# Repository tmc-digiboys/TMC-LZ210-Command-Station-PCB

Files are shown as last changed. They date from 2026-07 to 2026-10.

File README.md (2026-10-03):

[🇬🇧 English](README.md) | [🇩🇪 Deutsch](README.de.md) | [🇳🇱 Nederlands](README.nl.md)

# DCC Command Station LZ210-TMC

Modular DCC command station with Ethernet and USB connectivity, and (partial) support for the XpressNet and Z21 protocols. The board supports LocoNet-T and XpressNet handhelds and other equipment, provides an interface for external boosters via CDE and LocoNet-B, and has a connection for RS-Bus feedback modules.

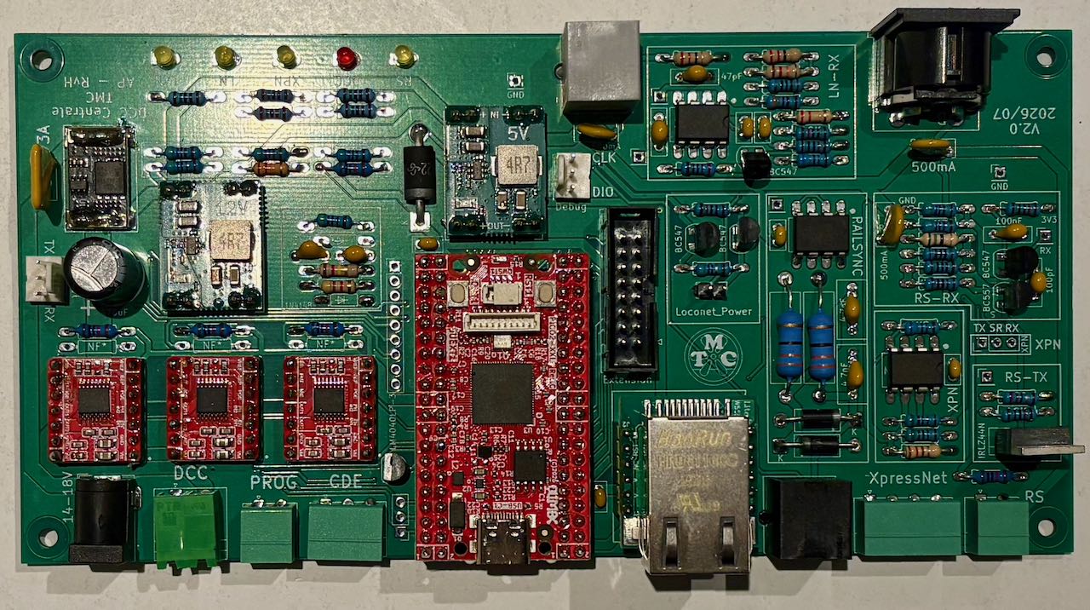
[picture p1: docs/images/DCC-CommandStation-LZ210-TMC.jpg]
DCC Command Station


## Why this board
The [Twentse Modelspoorweg Club (TMC)](https://twentsemodelspoorweg.club) is modernising its electronics and software for digital layout control. For each of its stations (Hengelo, Enschede, Oldenzaal, Almelo) it needs its own new DCC command station to operate all turnouts and signals, and to receive occupancy feedback. Although DCC command stations are of course available ready-made, building your own is not only a nice challenge, but also a potential cost saving.

The starting point is a modular design, similar to the [Z21PG](https://pgahtow.de/w/Zentrale_Z21PG/de). Initially we looked at whether we could simply adapt or replicate this design. We quickly realised that upgrading to a modern processor and ready-made modules would lead to better results and a lower price.

The goal is to develop a command station that can be extended step by step and that **club members and other interested persons can easily adapt and rebuild**. That is why we deliberately chose an easy-to-solder, low-cost THT (Through-Hole Technology) PCB, and, for the critical components, ready-made modules that can easily be bought online.

For the processor we chose the RP2350B, mainly because of its PIO peripheral, which allows a fully jitter-free DCC signal to be generated. It is an inexpensive and modern dual-core processor, running at 125 MHz. See [processor choice](docs/processor.md) for a comparison with ESP32, DxCore and STM32.

The name LZ210-TMC was chosen as a contraction of Z21 (Roco, Z21 protocol, LocoNet) and LZ100 (Lenz, XpressNet, RS-Bus interface and CDE booster connection).

## Schematic
The complete schematic (all hierarchical sheets) is available in [Schematic.pdf](docs/Schematic.pdf).

The schematic is divided into the following functional blocks (click the name for more details):

<details>
<summary><strong>Power supply</strong></summary>

The command station must be powered with a DC voltage equal to the desired track voltage. In practice, a switching or laptop-style power supply can be used that can deliver a voltage between 14 and 20 volts, and 3 to 4 amps.

⚠️ **Note:** not every switching power supply is suitable or safe for this purpose. Practical advice: choose a power supply of the kind used with other DCC command stations, for example the [Roco 10851](https://www.roco.cc/rde/10851-schaltnetzteil-54-watt.html) or [YaMoRC YD7460-18](https://yamorc.de/products/?singleproduct=13843).

The external supply voltage enters via a 3 amp eFuse and a so-called "ideal diode", which protects the circuit against reverse polarity, and then feeds VCC and two step-down converter modules.

VCC powers the H-bridges for the track voltage and the programming track. VCC also runs to the processor, so that a resistor divider and an ADC input can be used to check whether the external supply voltage has the correct value.

The 12V step-down converter supplies power to LocoNet, XpressNet, the CDE booster interface, and RS-Bus feedback. The 12V voltage is likewise, for monitoring purposes, fed through a resistor divider to an ADC input.

The choice of the 5V step-down converter requires some explanation, because the processor and peripherals actually expect 3V3. The reason 5V was chosen is that the Olimex RP2350 Pico2-XL module already has its own step-down chip on board. An external 3V3 converter must *not* be connected to the 3V3 output of the Olimex module (see below). The output of the Olimex module does deliver enough power to supply the rest of the peripherals with 3V3. The diode between the 5V step-down converter and the Olimex RP2350 Pico2-XL module prevents damage from occurring if, in addition to the external supply, power is also being supplied via the USB connector.

><details>
><summary>Explanation: why not an external 3V3 on the Olimex module?</summary>
>
> The TPS62A02A chip on the Olimex module has active output discharge: as soon as the TPS62A02A is switched off (for example by pulling 3V3_EN to GND), an internal FET is switched on to actively discharge the energy still stored in the external inductor. If, in that state, 3.3V is nevertheless applied to the output of the TPS62A02A, the internal FET keeps conducting and draws tens of mA from the external supply. This can cause the SOT-563 package to overheat. This behaviour is also described on [TI's E2E forum](https://e2e.ti.com/support/power-management-group/power-management/f/power-management-forum/1305135/tps62a01-active-output-discharge).
>
> Hence the choice to feed not the 3V3 output but the VSYS input. This keeps the onboard TPS62A02A always active, regardless of whether power comes from the 5V step-down converter or from USB. The TPS62A02A can deliver enough power to also supply the remaining peripherals.
>
> This behaviour differs from the original Raspberry Pi Pico2: that board uses the RT6150B as its step-down converter, which does not have this active output discharge. On the Pico2, pulling 3V3_EN to GND and then applying an external 3.3V to the output is in fact the method documented by Raspberry Pi itself. For other RP2350B modules: always check which step-down converter is fitted first, since behaviour can differ per board.
>
> </details>

</details>

<details>
<summary><strong>Processor</strong></summary>

We chose a Raspberry Pi Pico processor; see [processor choice](docs/processor.md) for details. An important advantage of the Raspberry Pi Pico is that it has a Programmable IO (PIO) peripheral, a specialised co-processor that can generate very precisely timed output signals.

Within the Pico series there are two variants: the RP2040, with two PIOs, and the RP2350, with three PIOs. Because we use three PIOs, we chose the RP2350. The first PIO is used for the DCC signal, the second for the RS-Bus master, and the third for the XpressNet RS-485 connection.

The RP2350 in turn comes in two variants: the "plain" RP2350, which has 30 General Purpose IO (GPIO) pins, and the RP2350B, which has 18 more. For an early test version of the command station the "plain" RP2350 was used, but because we wanted to use more IO pins we ultimately chose the RP2350B.

Several suppliers (such as Olimex, Waveshare and WeAct) offer different RP2350B modules. We chose the RP2350B-X(X)L module from Olimex; see the reasoning below under Building.

><details>
><summary>Explanation: are alternative modules possible?</summary>
>
> If fewer pins and fewer PIOs are needed — for example because there is no need for an RS-Bus master or XpressNet — RP2040 modules can also be used. In that case, the PCB layout and possibly the power supply would need to be adapted.
>
> </details>

><details>
><summary>Explanation: why a PIO for XpressNet?</summary>
>
> On most processors it is possible to use a UART to send and receive XpressNet messages. That works because the UART on many processors supports both 8 and 9 data bits. XpressNet, however, requires 9 data bits (where the ninth bit indicates whether it is an address or a data byte). Compared with other processors, the UART on the Raspberry Pi Pico is relatively limited and only supports 8 data bits. By writing a small PIO program, it is nevertheless possible to work with 9 data bits on the Raspberry Pi Pico as well, and so support XpressNet.
>
> It would in principle be possible, with some tricks, to still use the UART on the Raspberry Pi Pico for XpressNet. However, since there are only two UARTs, we decided against this.
>
> </details>

</details>

<details>
<summary><strong>Ethernet</strong></summary>

The Ethernet schematic contains only the WIZnet W5500 module. All pins are wired through to the processor.

The older (and often more expensive) W5100 and W5100S modules will probably also work, but this has not been tested.

</details>

<details>
<summary><strong>Track output</strong></summary>

The DCC signal is amplified by a DRV8874 module, fitted with the same driver IC that is also used in the DCC-EX project.

The schematic contains few components because the module itself already contains a number of resistors that result in settings usable for our command station.

By default, I<sub>TRIP</sub> is set to approximately 3 amps. If desired, a different value can be chosen by removing the 2.49 kΩ resistor on the module and fitting R601 with a different value.

By default, **PMODE** is connected to 3V3, which activates PWM mode. If desired, the "PWM (PH / EN) solder jumper" on the bottom of the PCB can be used to connect **PMODE** to GND instead. To do this, remove the existing copper connection to 3V3 to avoid a short circuit, and make the other solder connection to GND.

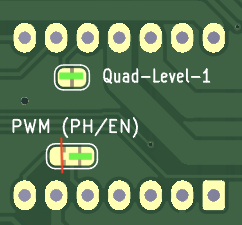
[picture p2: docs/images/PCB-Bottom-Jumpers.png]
CD booster input


By default, the module is set to Quad-Level 2, but this can be changed via a second "solder jumper" on the bottom of the PCB by connecting **IMODE** to GND. See the DRV8874 datasheet for the differences between the modes.

No space has been reserved on the PCB for a snubber circuit and/or power inductor. If desired, these can be placed after the connector, in the wiring to the rails.

Detailed background information on the choice and limitations of this driver IC is described on a separate page. That page discusses in detail the inrush-current problems that this and similar chips can have with capacitive loads. See: [DRV8874 output stage](docs/DRV8874.md)

How overcurrent faults (OCP and ITRIP) show up on the **nFAULT** pin, how the processor handles them, and which value of the sense resistor is recommended, is described in [Dealing with nFAULTs](docs/nFault.md).

</details>

<details>
<summary><strong>Programming track</strong></summary>

The PCB allows you to use the same DRV8874 H-bridge module as for the normal track output. The advantage of reusing modules is a uniform parts list and easier building.

However, it is better to use a DRV8876 module instead of a DRV8874 module. These modules can deliver somewhat less power, which is actually an advantage for a programming track, and they are also somewhat cheaper.

An important technical difference between the DRV8874 and DRV8876 modules is that the latter has a higher current-mirror gain factor **AIPROPI**, namely 1000 (instead of 450). As a result, the voltage seen by the processor's ADC input during a (60 mA) DCC-ACK signal is 150 mV (instead of 67 mV). This allows a more reliable measurement of the DCC-ACK signal.

As with the normal track output, it is possible to remove the 2.49 kΩ resistor fitted by default on the module and replace it with R801. A good value for R801 is 6.8 kΩ. With this value, the maximum current I<sub>TRIP</sub> that can be delivered during programming is limited to 500 mA. RCN-216 recommends a (non-mandatory) limit of 250 mA ±20% at power-up, but also permits fixed current limiters up to 1 A; 500 mA fits comfortably within that.

An additional advantage of replacing the 2.49 kΩ resistor with a 6.8 kΩ resistor is that the voltage during a DCC-ACK is increased to well over 400 mV, making it easier to measure on the processor's ADC input.

</details>

<details>
<summary><strong>CDE booster interface</strong></summary>

The PCB uses the same type of H-bridge module as for the programming track (DRV8876 or DRV8874). Technically, a DRV8871 module from AliExpress could also be used. However, the dimensions of this module do not fit the current PCB.

For the CDE output, the well-known inrush-current problems of the DRV887x ICs do not apply. The load is not capacitive, and the CDE signal requires no more than a few hundred milliamps. The internal short-circuit protection of the DRV887x does not trigger during start-up, unless the output is genuinely short-circuited. The DRV887x is oversized for this purpose, but can in principle be used without issue.

Detailed information about the CDE interface is described on a separate page: [CDE interface](docs/CDE.md).

</details>

<details>
<summary><strong>LocoNet</strong></summary>

The schematic for the LocoNet section is standard, and described in many places online. However, the values of a number of components have been adapted so that the whole works on 3V3 as well.

In addition to the LocoNet-T interface, there is also a LocoNet-B interface, which supplies a RailSync signal for boosters via the outermost pins of the connector. The RailSync signal can be generated in several ways.

- Up to and including V2.2, a design was used that was copied from the Internet (https://www.fucik.name/masinky/NanoL/, https://oshwlab.com/fiorinid/z21pg-by-df-pro). These circuits utilise a specialised driver IC; the diagram lists a number of options. Of the options listed, only the UCC27425 IC has an ENABLE input, which allows the RailSync signal to be easily disabled. Resistors rated at 33 Ω / 2 Watt (or preferably 22 Ω / 5 Watt) are connected to the outputs of this driver. On the one hand, these resistors serve as short-circuit protection (which is why they must be capable of dissipating 2 to 5 Watt). On the other hand, these resistors, together with the 4.7 nF capacitors, form a low-pass filter, thus reducing interference. The P6KE15A are ESD diodes that protect the LocoNet driver IC. The disadvantage of this circuit is that it cannot supply more than 100 mA, which limits the maximum number of boosters that can be connected to approximately 10, depending on the type of booster.

- From version 2.3 onwards, RailSync uses the CD(E) (booster) signal. This not only reduces the number of components required (thereby lowering costs), but also allows a much larger number of boosters to be connected. Furthermore, all connected boosters now have exactly the same signal, regardless of whether they are connected via CDE or via LocoNet-T.

</details>

<details>
<summary><strong>XpressNet</strong></summary>

The XpressNet interface is simple and standard. The [OpenDCC site](https://www.opendcc.de/elektronik/opendcc/xpressnet_hw.html) has a basic circuit that many have built. The only change is that the 1K5 resistors have been replaced with 560 Ω, because the driver IC is powered not from 5V but from 3V3. The 8K2 resistor (R504) ensures the driver starts in RX mode.

A MAX(3)485 IC is often used as the driver. A better choice is the MAX(3)483, the slew-rate-limited version of this driver, since it limits possible high-frequency interference on the RS-485 line. Unfortunately, this IC is noticeably more expensive. The OpenDCC page mentioned above gives further details on possible alternative driver ICs.

</details>

<details>
<summary><strong>RS-Bus feedback</strong></summary>

The schematic for the RS-Bus was taken from the [Der-Moba website](https://www.der-moba.de/index.php/RS-Rückmeldebus).
The transistor for transmitting mentioned there has, however, been replaced with an (IRLZ44) MOSFET, allowing for a somewhat higher load.

</details>

## Building
To build the command station, the easiest approach is to have the current PCB manufactured by sending the file [production/TMC-Centrale.zip](production/TMC-Centrale.zip) to a company such as JLCPCB. This file contains all the (Gerber) files the manufacturer needs. In the summer of 2026, having 5 PCBs made, including shipping, cost approximately €25.

The design is open source. Building, modifying, and distributing is encouraged under the terms of the [licence](LICENSE), and with reference to this source.

The complete list of components is: [production/bom.csv](production/bom.csv).

To make building as easy as possible, we chose, wherever possible, ready-made modules of the kind sold online by AliExpress and others. Below is an overview of the main modules, as well as the connectors that fit the PCB:

<details>
<summary><strong>RP2350B (MCU module)</strong></summary>

For the processor we chose the [Olimex RP2350B-XL](https://www.olimex.com/Products/RaspberryPi/PICO/PICO2-XXL/open-source-hardware) module. Olimex guarantees that production of these modules will be supported until at least 2035, and has published all KiCad design files and manufacturing files openly on GitHub.

There are two variants of this module: the RP2350B-XL (€5) and the RP2350B-XXL (€9). The difference is that the XXL has some extra capabilities that are not needed for this command station. Although the schematic references the XXL, the XL variant is preferred for its price. Both variants fit the PCB, however.

The modules can be bought from [Olimex](https://www.olimex.com/Products/RaspberryPi/PICO/PICO2-XXL/open-source-hardware) directly, but also via distributors such as [TME](https://www.tme.eu).

</details>

<details>
<summary><strong>DRV8874 / DRV8876 (motor drivers)</strong></summary>

Ready-made DRV8874 / DRV8876 modules are used for the DCC, programming track, and CDE outputs.

Pololu brought modules for the [DRV8874](https://www.pololu.com/product/4035) and [DRV8876](https://www.pololu.com/product/4037) to market some years ago. Since spring 2026, (cheaper) variants have also become available on AliExpress. The Pololu module includes an extra reverse-polarity-protection MOSFET as additional protection, which the AliExpress modules lack. This extra protection is not needed for this command station.

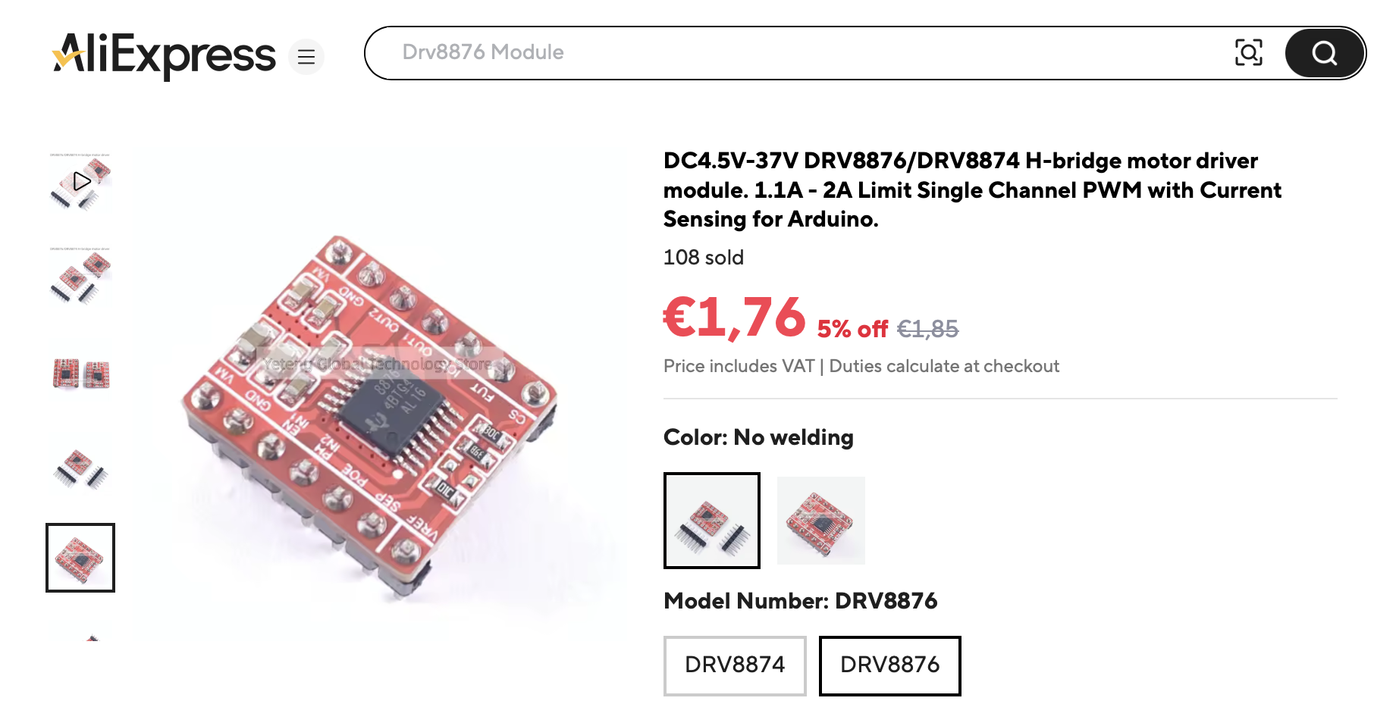
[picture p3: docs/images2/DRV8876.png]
AliExpress DRV8876


</details>

<details>
<summary><strong>Step-down module (5V/12V)</strong></summary>

The PCB footprint dimensions are matched to the well-known MP1584 step-down modules, offered by multiple suppliers on AliExpress. Two modules are needed. The first supplies the 5V supply voltage for the processor (note: the Olimex processor module itself converts this 5V to 3V3 again), and the second module supplies 12V. Instead of modules with a fixed 5V/12V output voltage, adjustable-output modules can also be used.

Modules other than the MP1584 will in principle also work, but do not fit the PCB footprint.

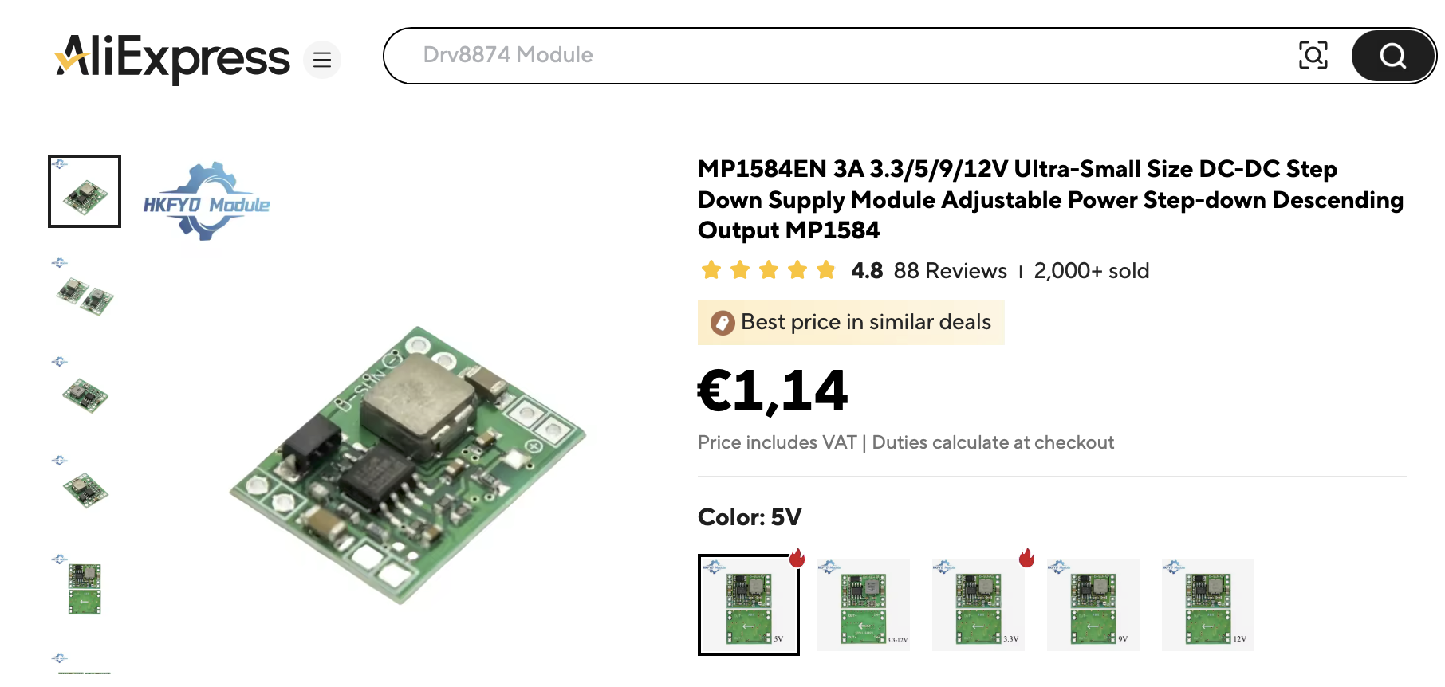
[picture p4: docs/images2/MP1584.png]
AliExpress MP1584


</details>

<details>
<summary><strong>Ideal-diode module</strong></summary>

An XL74610 module is used for reverse-polarity protection, as sold on AliExpress and by other suppliers.

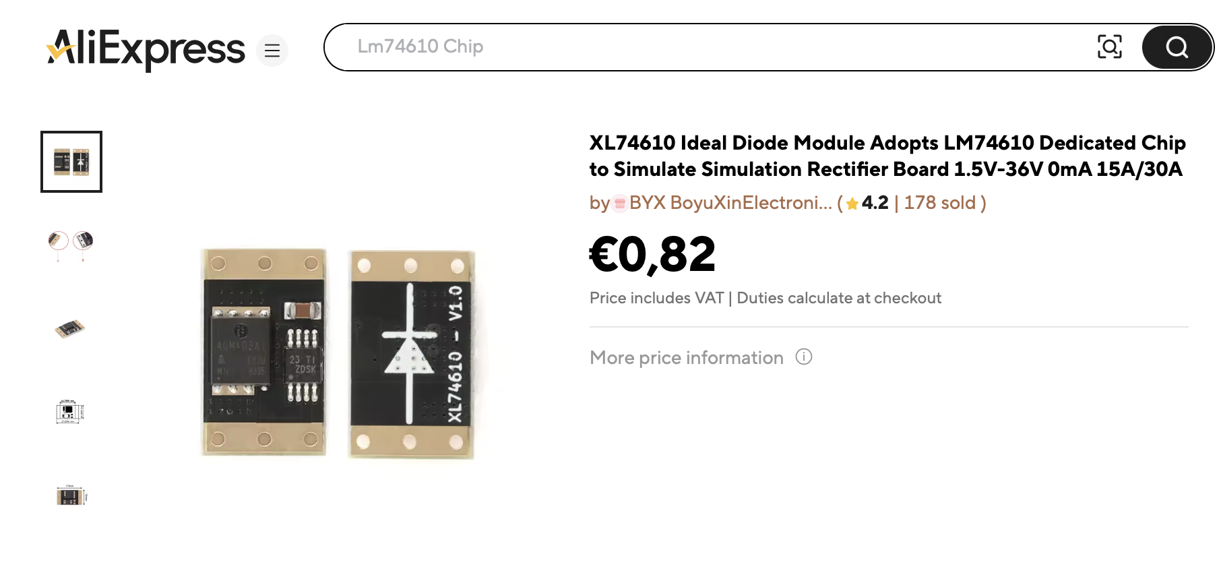
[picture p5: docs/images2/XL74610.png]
AliExpress XL74610


</details>

<details>
<summary><strong>W5500 Ethernet</strong></summary>

A W5500 module is used for the Ethernet connection, as sold on AliExpress and by other suppliers.

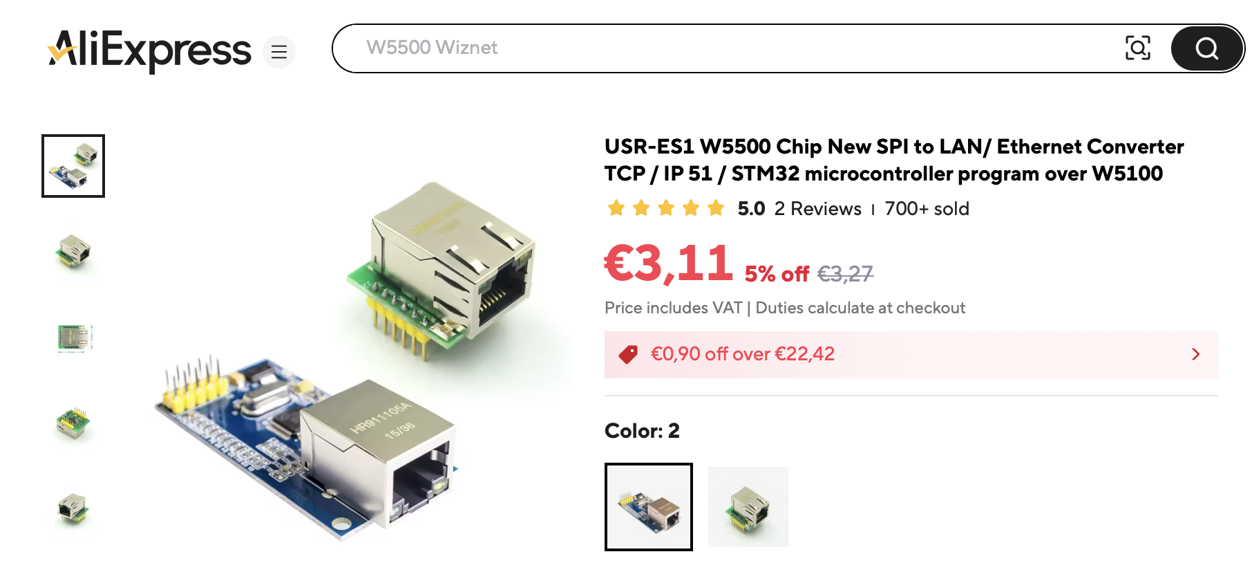
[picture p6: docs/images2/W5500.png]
AliExpress W5500


</details>

<details>
<summary><strong>Connectors</strong></summary>

The PCB is designed for the following connectors:

><details>
><summary>LocoNet: 6P6C (RJ12)</summary>
>
> There are several brands and types of 6P6C connectors on the market, with different footprints. The PCB is designed for connectors with a footprint matching the WayConn MJEA connectors. These have their electrical connections on the bottom (PCB side).
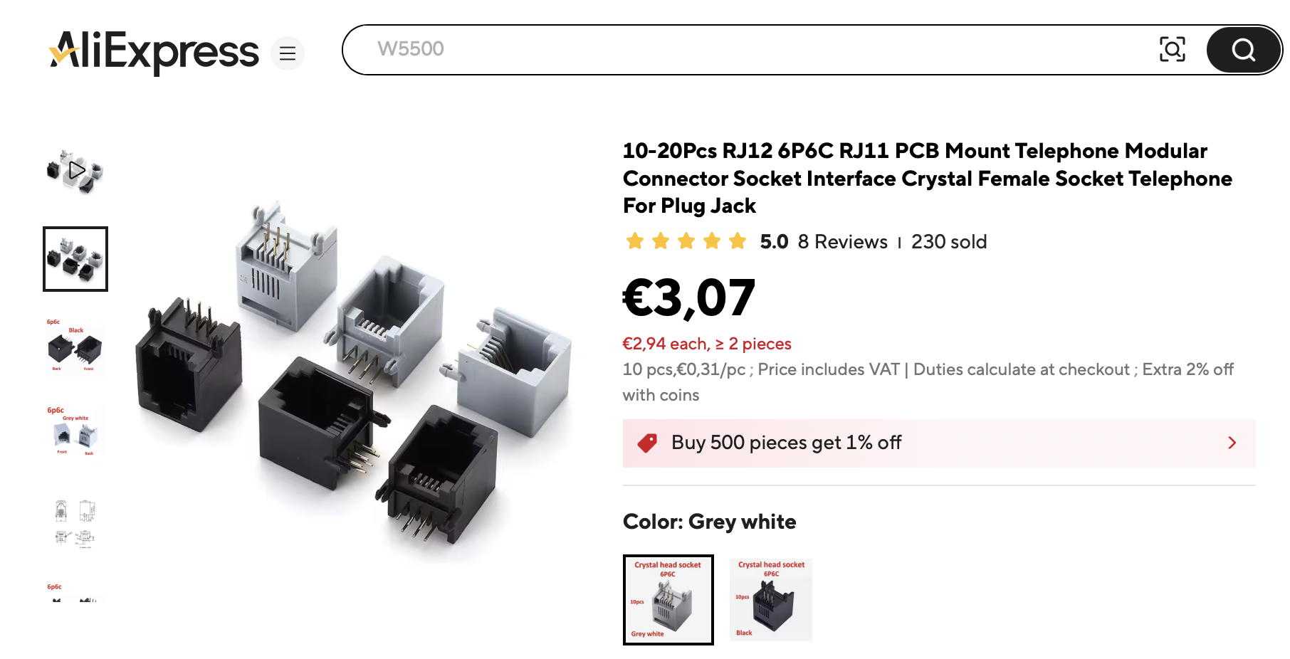
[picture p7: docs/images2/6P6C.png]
AliExpress 6P6C
> 
>
> </details>
><details>
><summary>Barrel Jack</summary>
>
> A 5.5x2.1mm barrel jack is used for the power connector.
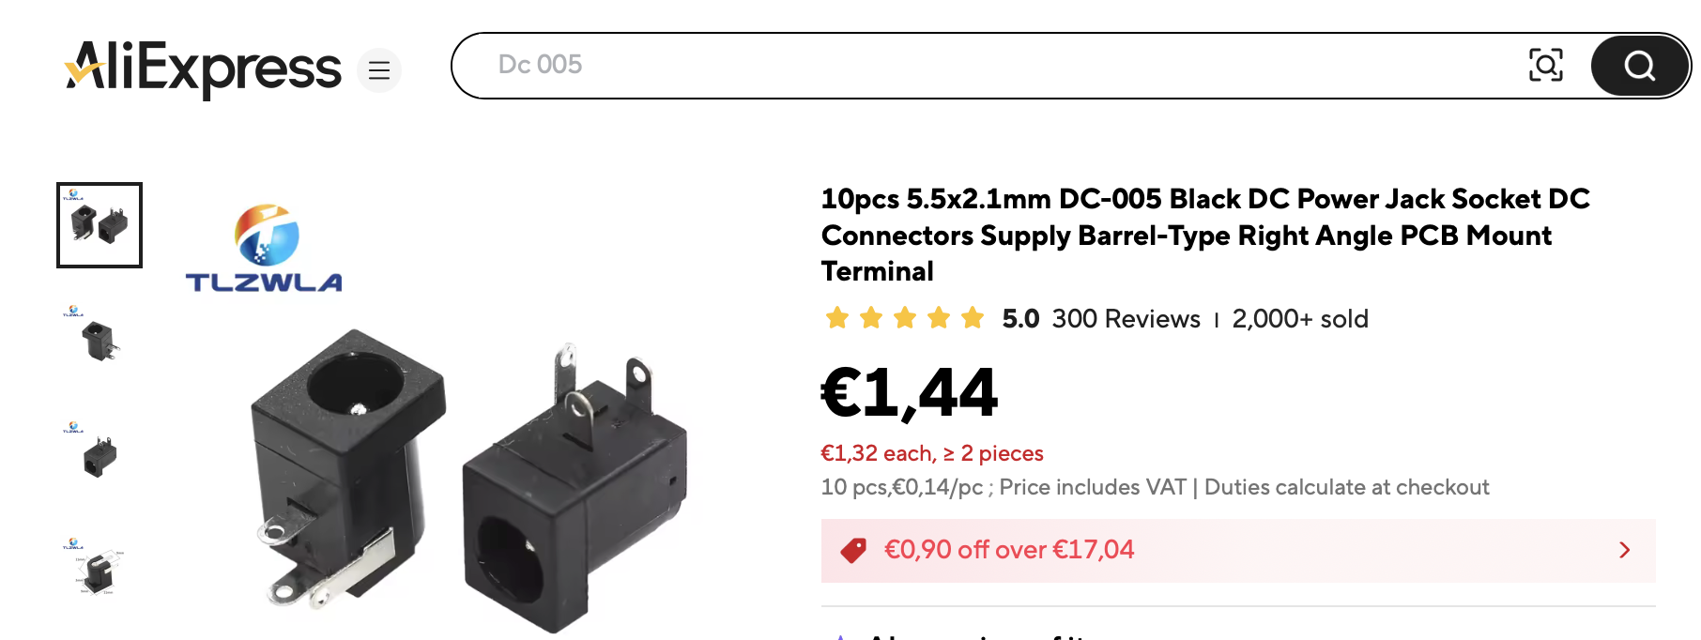
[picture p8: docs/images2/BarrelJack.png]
AliExpress BarrelJack
> 
>
> </details>
><details>
><summary>Terminal Blocks</summary>
>
> A PhoenixContact MSTBA 2.5/2-G, with a pin spacing of 5.00 mm, is used for the DCC track output. Terminal blocks with a pin spacing of 5.08 mm will also fit, however.
>
> A Phoenix Contact MC 1.5/2-G-3.81 terminal block is used for the programming output.
>
> A Phoenix Contact MC 1.5/3-G-3.81 terminal block is used for the CDE output.
>
> A Phoenix Contact MC 1.5/2-G-3.81 terminal block is used for the RS-Bus input.
>
> A Phoenix Contact MC 1.5/4-G-3.81 terminal block is used for the XpressNet output. A 5-pin DIN connector is fitted at the front.
>
> Variants of these connectors are offered by several manufacturers, including PTR/Hartmann.
>
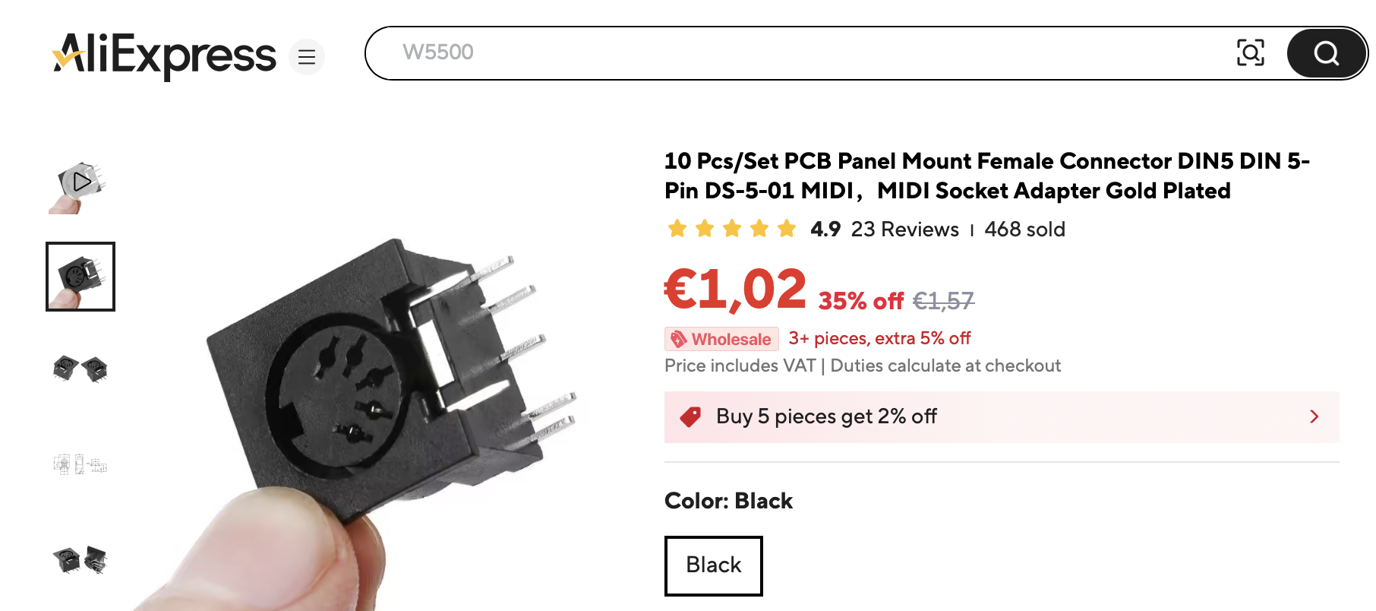
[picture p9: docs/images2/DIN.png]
AliExpress DIN
> 
>
> </details>

</details>

## Software

The firmware for this command station can be found in its own GitHub repository, and is therefore not discussed further at: [https://github.com/tmc-digiboys/TMC-LZ210-Command-Station](https://github.com/tmc-digiboys/TMC-LZ210-Command-Station)

## Comparison with other command stations

This command station does not stand on its own, but stands in a long tradition of open-source DCC command stations:

<details>
<summary><strong>OpenDCC</strong></summary>

One of the earliest open-source DCC command stations is the [OpenDCC Z1](https://www.opendcc.de/elektronik/opendcc/opendcc.html). This command station was designed twenty years ago by Wolfgang Kufer.
- **Processor.** OpenDCC runs on an 8-bit Atmel AVR (ATmega32 or ATmega644P) at 16 MHz. This command station uses a dual-core RP2350 at 125 MHz with a PIO peripheral, and is therefore orders of magnitude more powerful.
- **Output stage.** OpenDCC uses a fixed H-bridge (STM L6206), theoretically rated at 2.8 A per output, but thermally limited on the PCB to about 1.5 A continuous. This command station uses a DRV8874 module (6 A theoretical), whose current is limited on the module itself to about 2.7 A.
- **Feedback.** OpenDCC supports S88, with an extension for turnout-position feedback. This command station uses RS-Bus and LocoNet.
- **Connection to a PC.** OpenDCC communicates via RS232/USB with a PC, using XpressNet or P50X as the higher-layer protocol; OpenDCC itself has no network or WiFi connection. This command station has, in addition to USB, its own Ethernet connection, and supports XpressNet and Z21 as higher-layer protocols.
- **Boosters.** OpenDCC has no separate interface for external boosters, such as CDE or LocoNet-B.
- **Handhelds.** Like this command station, OpenDCC supports XpressNet handhelds (such as the Roco Multimaus). OpenDCC does not support LocoNet handhelds, however.

The OpenDCC Z1 command station can be seen as a forerunner of open-source DCC command stations. Many of its ideas, circuits, and software have been copied (in adapted form) by others, and are still in use today. However, building the Z1 today no longer seems like a good idea: modern microcontrollers are both cheaper and many times more powerful than the 8-bit ATmega generation on which the OpenDCC Z1 was based at the time.
</details>

<details>
<summary><strong>BiDiB</strong></summary>

[BiDiB](https://www.bidib.org/) can be seen as a successor to the OpenDCC Z1 command station. BiDiB has been developed since 2010 by — again — Wolfgang Kufer, and is brought to market in hardware form by, among others, Fichtelbahn.
- **Architecture.** BiDiB is primarily a bus onto which multiple intelligent components (such as GBMboost/GBM16T/OpenSwitch/IF2) can be connected. It is not a command station in the traditional sense, with a built-in booster and interfaces such as XpressNet, LocoNet and RS-Bus.
- **Processor.** BiDiB implementations are based on the Atmel XMEGA processor. Although this is one of the most powerful 8/16-bit / 32 MHz processors, it is also a fairly old processor and, compared with the dual-core RP2350 / 125 MHz processor of this command station, quite expensive.
- **Building.** BiDiB PCBs are designed for SMD components. Although BiDiB designs are more advanced and of higher quality than those of this (THT) command station, they are also harder to build, adapt and extend.
- **RailCom.** BiDiB excels at receiving, analysing and processing RailCom feedback. This command station offers no support for this.

BiDiB offers a complete ecosystem with a focus on intelligent components and extensive RailCom processing. This command station is primarily a traditional command station like those from Roco and Lenz, communicating via established protocols with equipment from various manufacturers.

</details>

<details>
<summary><strong>Z21PG</strong></summary>

[Z21PG](https://pgahtow.de/w/Zentrale_Z21PG/) is an Arduino-based self-build project by Philipp Gahtow for a low-cost Roco Z21 clone.
- **Ease of building.** Philipp Gahtow himself publishes mainly software (Arduino sketches) and separate schematics for a number of hardware variants (Arduino MEGA, ESP32, ...). Unlike this command station, there is no official Z21PG (KiCad) PCB design. Third-party PCB designs do exist for the Z21PG, however. Both command stations are easy to build.
- **Processor and DCC signal.** The most commonly built Z21PG variant runs on an (older) ATmega2560 (16 MHz), although ESP32 is also mentioned as an option. The DCC signal is generated in software via timer interrupts, not via a dedicated hardware peripheral. This command station uses a (modern) dual-core RP2350 at 125 MHz with a PIO peripheral, more than ten times as fast and with a jitter-free DCC signal.
- **Interfaces.** Z21PG offers connections comparable to the Roco Z21 command station: LAN, X-Bus (XpressNet), L-Bus (LocoNet-T), booster connection, track and programming output. This command station additionally has an RS-Bus connection, and its booster connections are compatible with CDE and LocoNet-B.

Of all the projects discussed here, Z21PG has the most in common with this command station. Both are modularly designed and relatively easy and cheap to build. Z21PG primarily takes the Roco Z21 as its model, whereas this command station also takes the Lenz command stations as a model. Z21PG is a somewhat older design; this command station uses more modern components.
</details>

<details>
<summary><strong>DCC-EX</strong></summary>

A currently popular self-build command station is [DCC-EX](https://dcc-ex.com/). There are functional similarities (including the DRV8874 output stage), but also a number of significant differences:
- **Availability.** DCC-EX offers both factory-assembled boards (EX-CSB1, from approx. €75–115 excl. VAT/shipping) and DIY builds on Arduino form-factor boards. This command station is intended for self-building, and its component cost is lower (approx. €40).
- **Connection to a PC/network.** This command station uses Ethernet (XpressNet and Z21); DCC-EX uses WiFi (with JMRI, WiThrottle and Engine Driver support).
- **Interfaces for handhelds.** This command station has native (RS485) XpressNet and LocoNet interfaces, to which Lenz, Roco and other handhelds can be connected. DCC-EX focuses primarily on WiFi throttles and JMRI.
- **Interfaces for feedback.** This command station has native RS-Bus and LocoNet interfaces. DCC-EX has no such interfaces.
- **Booster interfaces.** This command station supports external boosters via LocoNet-B and the CDE interface. DCC-EX has no CDE/LocoNet-B support, but does have a RailSync mechanism, through which external boosters can be connected.
- **Mixed DCC/DC operation.** DCC-EX can switch each output between DCC and DC PWM, so that classic DC locomotives can run as well. This command station supports DCC only.

Where this command station differs most clearly is the ecosystem it fits into. DCC-EX is strongly oriented towards the American hobby scene: WiFi throttles, JMRI, and, for accessories, the LCN (Layout Control Node) concept, in which inexpensive Arduino Nanos with nRF24L01 radio modules wirelessly drive turnouts, signals and lighting. This command station, by contrast, is more oriented towards traditional European users: XpressNet and LocoNet handhelds, CDE/LocoNet-B boosters, and RS-Bus feedback. For clubs that already work with Lenz, Roco or similar equipment, that is a more direct fit than the WiFi/JMRI/LCN route taken by DCC-EX.
</details>

<details>
<summary><strong>OpenRemise</strong></summary>

[OpenRemise](https://github.com/OpenRemise) is explicitly aimed at **ease of use without any soldering or electronics knowledge**: the system is essentially plug-and-play and, once installed, is operated entirely via a web interface on a smartphone, tablet or PC. In that sense, its philosophy is almost the opposite of this command station.
- **Hardware.** OpenRemise is aimed mainly at users who want a ready-made PCB; the board consists mostly of SMD components and is not easy to hand-solder. This command station is aimed mainly at people who want to solder it themselves and possibly modify it.
- **Processor.** OpenRemise is based on a modern, powerful processor (ESP32), just like this command station (RP2350). For jitter-free DCC signal generation, OpenRemise uses a dedicated peripheral (RMT), just like this command station (PIO).
- **Output stage.** OpenRemise has an output stage based on discrete MOSFETs, which is superior to the DRV8874 output stage used in this command station.
- **Target audience.** OpenRemise excels at updating decoder firmware, but can also be used as a complete command station. This command station is more intended as a traditional DCC command station, and has more standard interfaces (XpressNet, LocoNet, CDE).
- **Network.** OpenRemise supports WiFi and focuses on web-based control. This command station supports Ethernet and focuses on PC control via the XpressNet / Z21 protocol.

OpenRemise is primarily a ready-made SMD PCB design with accompanying firmware. This command station is aimed primarily at hobbyists who want an inexpensive command station that is easy to build and modify. As a result, this command station has had to make a number of trade-offs (such as the DCC output stage) that OpenRemise did not have to make.
</details>

## Status and future plans
The command station has been in use at TMC since summer 2026 for operating turnouts, signals, and for occupancy feedback. Although most functions have been tested and found to work well, there is no guarantee that everything works exactly as it should.

There are plans to also create an SMD version of the command station, although these plans are not yet definite.

The PCB has room for an extension connector, carrying SPI and I2C, among others. An extension board could be used to implement additional functions, such as a display, RailCom feedback, S88N, or the CAN bus.

In principle it should also be possible to equip the command station with a WiFi interface. However, because Ethernet is more reliable, we decided against WiFi.

## References

<details>
<summary><strong>Details of this design</strong></summary>

- [Processor choice](docs/processor.md) — comparison of the RP2350 with ESP32, DxCore and STM32
- [DRV8874 output stage](docs/DRV8874.md) — background on the chosen driver IC and inrush-current issues
- [Dealing with nFAULTs](docs/nFault.md) — OCP and ITRIP faults, inrush handling and recommendations for the sense resistor
- [CDE interface](docs/CDE.md) — background on the external booster interface

</details>

<details>
<summary><strong>Protocols and circuits</strong></summary>

- [RailCommunity (RCN)](https://railcommunity.de) — DCC standards
- [XpressNet Specification](https://www.lenz-elektronik.de/media/0a/d1/4e/1760451943/XpressNet_V40_2.pdf?ts=1760451943) — XpressNet Version 4.0 (Lenz)
- [XpressNet circuit](https://www.opendcc.de/elektronik/opendcc/xpressnet_hw.html) — Basic circuit (OpenDCC)
- [LocoNet](https://www.digitrax.com/static/apps/cms/media/documents/tech_notes/loconet-personal-edition-1-0.pdf) — Personal Use Edition (Digitrax)
- [RS-Bus](https://www.der-moba.de/index.php/RS-Rückmeldebus) — Basic circuit (Der Moba)
- [Paco's Official Web Site](https://usuaris.tinet.cat/fmco/home_en.htm) — Basic circuits for XpressNet, LocoNet, CDE and boosters

</details>

<details>
<summary><strong>Commercial command stations and comparable self-build projects</strong></summary>

- [Lenz](https://www.digital-plus.de/) — LZV100/LZV200 command stations (XpressNet, CDE and RS-Bus)
- [Roco/Fleischmann](https://www.z21.eu/) — Z21 command station
- [OpenDCC](https://www.opendcc.de/)
- [BiDiB](https://www.bidib.org/)
- [Z21PG](https://pgahtow.de/w/Zentrale_Z21PG/)
- [DCC-EX](https://dcc-ex.com/)
- [OpenRemise](https://github.com/OpenRemise)

</details>

<details>
<summary><strong>Other</strong></summary>

- [Olimex RP2350B-XL/XXL](https://www.olimex.com/Products/RaspberryPi/PICO/PICO2-XXL/open-source-hardware) — MCU module

</details>

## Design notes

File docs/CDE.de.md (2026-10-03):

[🇬🇧 English](CDE.md) | [🇩🇪 Deutsch](CDE.de.md) | [🇳🇱 Nederlands](CDE.nl.md)

# CDE-Booster-Schnittstelle

Im Gegensatz zu DCC selbst ist die CDE-Booster-Schnittstelle durch keinen RCN- oder NMRA-Standard definiert. Lenz, der Entwickler dieser Schnittstelle, hat zudem nur wenig technische Informationen dazu veröffentlicht. Im Internet finden sich jedoch verschiedene Schaltpläne für die Booster-Seite der Schnittstelle, darunter der [Z21PG Booster](https://pgahtow.de/w/Booster#/media/Datei:Booster_v2.png) und [Paco’s BoosteR-CDE](https://usuaris.tinet.cat/fmco/railcom_en.html#booster).

Die Herkunft des Namens **CDE** ist nicht dokumentiert. In einigen Internetforen wird vermutet, dass die Buchstaben für **C**ommon, **D**ata und **E**rror stehen. Das könnte eine mögliche Erklärung sein, passt jedoch nicht gut zu aktuellen Implementierungen. In modernen Implementierungen sind **C** und **D** zueinander symmetrisch und bilden somit ein Differentialsignal. Eine alternative Möglichkeit ist, dass Lenz die Buchstaben **A** und **B** bereits für die XpressNet-Schnittstelle verwendet hatte. Schließlich werden die RS-485-Signale, auf denen XpressNet basiert, oft als **A** und **B** bezeichnet. Nach dieser Logik könnte **CDE** einfach die nächste Buchstabenfolge sein.

## Das CD-Signal

Die Anschlüsse **C** und **D** führen das DCC-Signal, das vom Booster zur Erzeugung des Gleissignals verwendet wird. Messungen an einem **LZ100**, **LZV100** und **LZV200** zeigen, dass **C** und **D** relativ zur Masse abwechselnd zwischen etwa 0 V und +12 V wechseln.
Die beiden Signale wechseln in entgegengesetzter Phase: Wenn **C** bei 12 V liegt, liegt **D** bei 0 V und umgekehrt. Die Spannungsdifferenz zwischen **C** und **D** wechselt daher zwischen etwa +12 V und −12 V.

Die folgende Oszilloskopabbildung zeigt das **CD**-Signal eines LZV200.

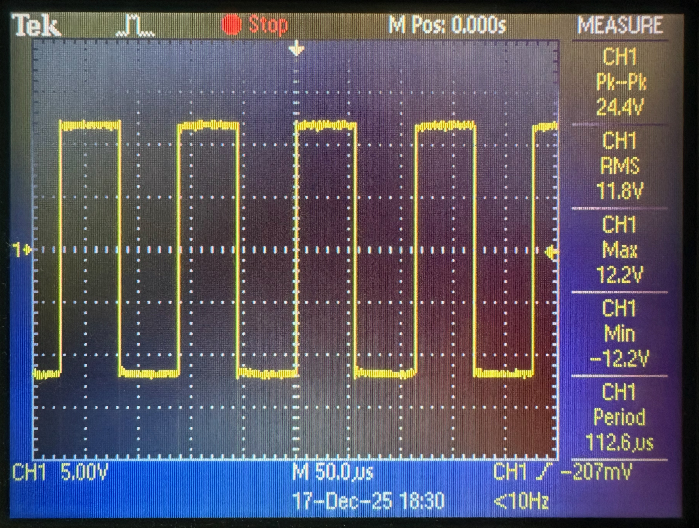
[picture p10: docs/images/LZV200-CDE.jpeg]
CD signal LZV200


Es ist wahrscheinlich, dass Lenz eine interne H-Brücke verwendet, um dieses **CD**-Signal zu erzeugen. Ohne eine H-Brücke wären zusätzliche Bauteile erforderlich, um sowohl +12 V als auch −12 V relativ zur Masse zu erzeugen. Dies würde einen zusätzlichen DC-Wandler erfordern, was das System unnötig komplex und damit teurer machen würde. Zu beachten ist, dass die H-Brücke nur eine begrenzte Leistung liefern muss.
Selbst bei großen Modelleisenbahnanlagen mit mehreren Verstärkern dürfte der benötigte Strom auf wenige hundert Milliampere begrenzt bleiben.

Es stellt sich die Frage, ob die Gleisspannung selbst oder ein 5-V-Signal nicht ausreichen würde, um das CD-Signal zu erzeugen. Um dies zu klären, muss die Eingangsseite eines modernen Boosters genauer betrachtet werden. Der folgende Schaltplan zeigt die Eingangsseite eines Paco-Boosters.

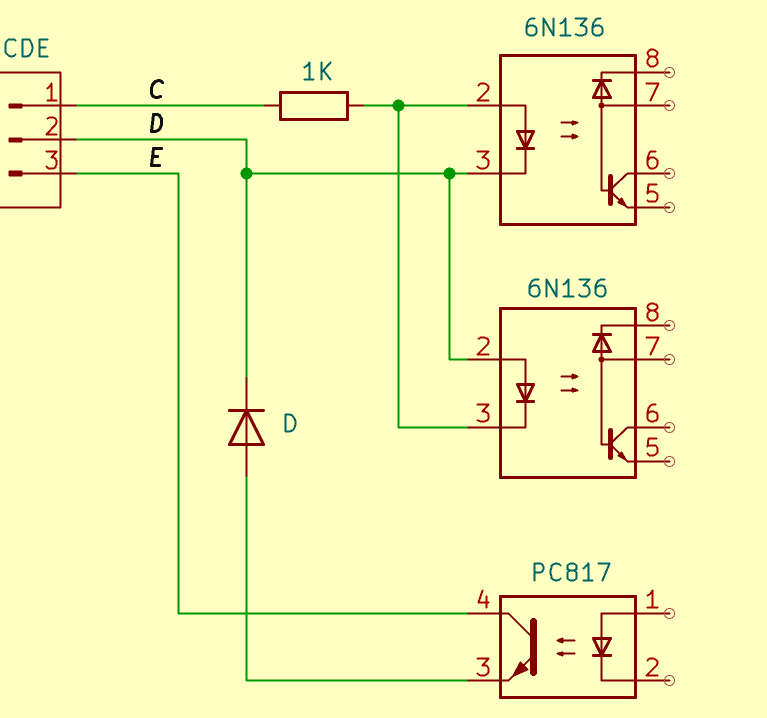
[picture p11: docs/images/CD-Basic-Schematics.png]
CD booster ingang


Die Schaltplan enthält zwei Hochgeschwindigkeits-Optokoppler (6N136). Der obere ist aktiv, wenn **C** relativ zu **D** positiv ist; der untere, wenn **C** relativ zu **D** negativ ist. Diese Konfiguration mit zwei Optokopplern ist erforderlich, da drei unterschiedliche Zustände zu berücksichtigen sind: **C** höher als **D**, **C** niedriger als **D** und die RailCom-Cutout, bei der **C** gleich **D** ist.

Entscheidend bei dieser Schaltung ist der in Reihe mit dem **C**-Signal geschaltete 1-kΩ-Widerstand, bei dem es sich in der Regel um einen 250-mW-Widerstand handelt. Bei einer **CD**-Spannung von 12 V fällt über diesem Widerstand ein Spannung von etwa 10,4 V (der Optokoppler hat eine feste Durchlassspannung von V<sub>F</sub> = 1,6 V). Der Widerstand muss also fast 110 mW Verlustleistung aushalten. Bei **CD** = 16 V steigt diese auf über 200 mW. Bei einer Spannung von 18 V oder höher wird der 250-mW-Widerstand überlastet.

Bei einer Spannung von **5 V** fallen am Widerstand nur **3,4 V** ab, und der Strom durch die Optokoppler-LED beträgt somit 3,4 mA. Dies ist zu gering, um die LEDs im Optokoppler bei DCC-Geschwindigkeit zuverlässig zu betreiben.

## Das E-Signal

Das **E**-Signal darf von einem Booster zur Anzeige eines Kurzschlusses verwendet werden. Zu diesem Zweck verwenden sowohl der Lenz- als auch der Paco-Booster einen zusätzlichen Optokoppler (z. B. einen PC817, siehe Abbildung oben). Im Falle eines Kurzschlusses wird dieser Optokoppler aktiviert, sodass Strom von **E** nach **D** fließen kann. Es ist auch möglich, einen Not-Aus-Schalter zwischen **E** und **M** (Masse) anzuschließen, wie in der folgenden Abbildung aus dem Lenz LZV100-Handbuch dargestellt, sodass Strom von **E** nach **M** fließen kann.

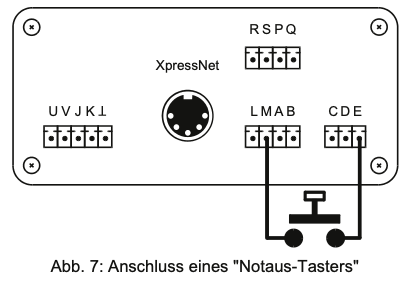
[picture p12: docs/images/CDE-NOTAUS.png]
Not Aus


### Prinzip der Kurzschlusserkennung

Das folgende Schema zeigt eine Schaltung, mit der eine DCC-Zentrale einen Kurzschluss oder ein Not-Aus-Signal erkennen kann.

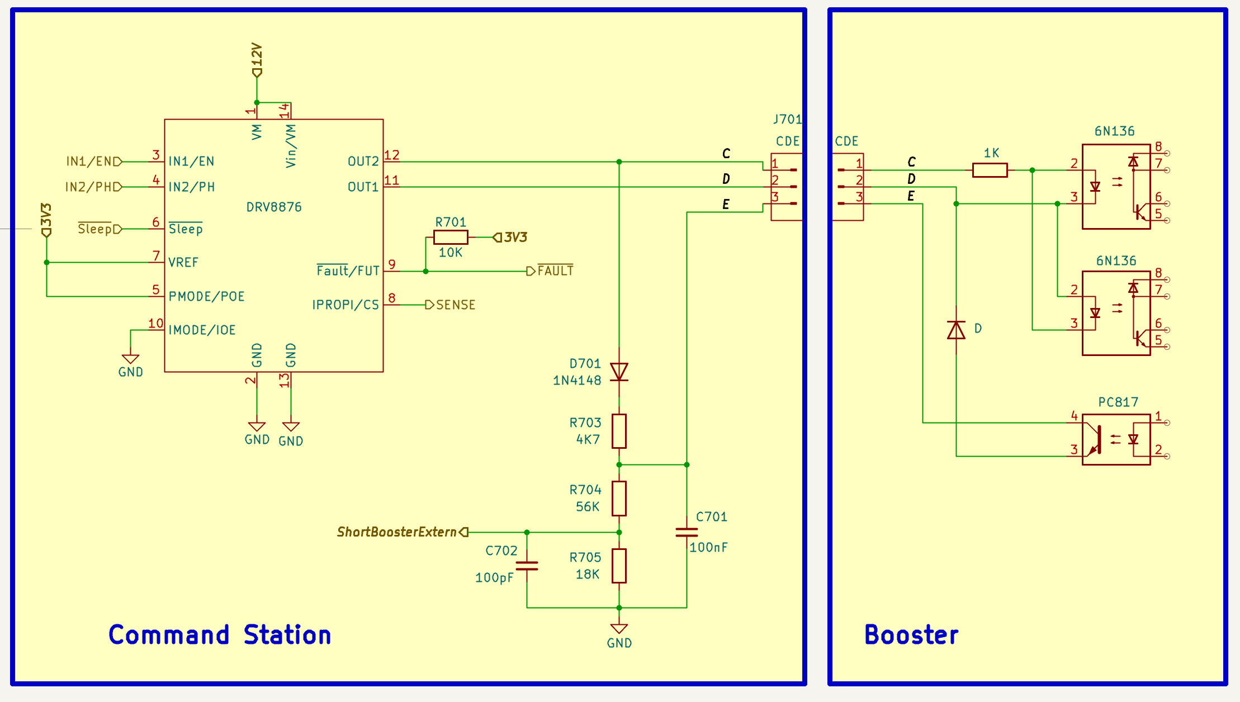
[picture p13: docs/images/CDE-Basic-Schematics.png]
Short-Circuit Detection


Wenn der Booster einen Kurzschluss erkennt, aktiviert er den Optokoppler (PC817). Ist die Spannung an **D** höher als die an **E**, verhindert die Diode (z. B. eine 1N4148), dass Strom von **D** nach **E** fließt, sodass die Spannung an **E** unverändert bleibt.
Ist die Spannung an **D** niedriger als die an **E**, kann Strom vom **E**-Anschluss des Boosters fließen. Dieser Strom fließt über Pin 4 (Kollektor) und Pin 3 (Emitter) des Optokopplers und dann zurück durch die Diode zum D-Anschluss. Der Booster zieht daher die Spannung an **E** über den Optokoppler in Richtung **D**.

<B>Die Schaltung liegt daher bei einem Kurzschluss oder Not-Aus auf *Low* und im Normalbetrieb auf *High*.</B>

### Normalbetrieb
Wird kein Kurzschluss gemeldet, funktioniert die Schaltung wie folgt: Wenn das **C**-Signal auf „High“ steht, wird der 100-nF-Kondensator (C701) über den 4,7-kΩ-Widerstand (R703) geladen. Die Zeit, die benötigt wird, um den Kondensator auf seine maximale Spannung aufzuladen, hängt von der Spannung und der genauen Form des DCC-Signals ab, liegt jedoch in der Größenordnung von wenigen Millisekunden. Die Diode 1N4148 (D701) verhindert, dass sich der Kondensator entlädt, wenn das **C**-Signal niedrig ist.

Um eine geeignete Eingangsspannung für einen 3V3-Mikrocontroller zu erhalten, wird die Spannung am Kondensator mithilfe eines Spannungsteilers aus den Widerständen 56 kΩ (R704) und 18 kΩ (R705) auf etwa 25 % der ursprünglichen Spannung reduziert. Bei einer maximalen **C**-Spannung von **12 V** wird der Knoten auf folgende Spannung aufgeladen: *V<sub>node</sub> = (12 − 0,7) × 18 / (56 + 18 + 4,7) ≈ 2,5 V*. Der 100-pF-Kondensator (C702) bildet zusammen mit dem Widerstandsteiler einen Tiefpassfilter mit einer Grenzfrequenz von etwa 100 kHz. Dieser Filter unterdrückt hochfrequente Störungen am Eingang des Mikrocontrollers.

Wird anstelle eines 3,3-V-Mikrocontrollers ein 5-V-Mikrocontroller verwendet, muss der 18-kΩ-Widerstand durch einen 47-kΩ-Widerstand ersetzt werden.

### Kurzschluss

Bei einem Kurzschluss oder einem Not-Aus kann sich der 100-nF-Kondensator über den Anschluss **E**, den Optokoppler und die Diode im Booster nach **D** entladen.
Diese Entladung findet nur statt, wenn das **D**-Signal auf Low ist, also jeweils für maximal 58 (DCC 1) oder 100 (DCC 0) µs.

Die Spannung an **E** sinkt auf einen Wert, der der Summe aus der Durchlassspannung der Diode und der Sättigungsspannung des Optokopplers entspricht (*V* <sub>CE(sat)</sub>). Diese liegt typischerweise bei etwa 0,7 bis 1,1 V: etwa 0,6 V für die Diode und 0,1 bis 0,5 V für den Optokoppler, je nachdem, inwieweit der Fototransistor gesättigt ist. Da der Spannungsteiler die Spannung am Kondensator auf etwa 25 % ihres ursprünglichen Wertes reduziert, beträgt die Spannung am Eingang des Mikrocontrollers während eines Kurzschlusses typischerweise nur 0,2 bis 0,4 V.

Im Falle eines NOT-AUS, bei dem **E** direkt mit Masse verbunden wird, wird die Spannung am Eingang des Mikrocontrollers schnell auf 0 V heruntergezogen. Bei 12 V fließt dadurch ein Strom von weniger als 3 mA durch den 4,7-kΩ-Widerstand. Dieser Strom ist klein genug, um eine thermische Überlastung des Widerstands zu verhindern.

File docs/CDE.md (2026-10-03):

[🇬🇧 English](CDE.md) | [🇩🇪 Deutsch](CDE.de.md) | [🇳🇱 Nederlands](CDE.nl.md)

# CDE Booster Interface

Unlike DCC itself, the CDE booster interface is not defined by any RCN or NMRA standard. Lenz, the developer of this interface, has also published very little technical information on the subject. However, various schematics for the booster side of the interface can be found online, including the [Z21PG Booster](https://pgahtow.de/w/Booster#/media/Datei:Booster_v2.png) and [Paco’s BoosteR-CDE](https://usuaris.tinet.cat/fmco/railcom_en.html#booster).

The origin of the name **CDE** is not documented. On some internet forums, it is suggested that the letters stand for **C**ommon, **D**ata and **E**rror. That could be a possible explanation, but it does not fit well with current implementations. In modern implementations, **C** and **D** are symmetrical in relation to each other and thus form a differential signal. An alternative possibility is that Lenz had already used the letters **A** and **B** for the XpressNet interface. After all, the RS-485 signals on which XpressNet is based are often designated as **A** and **B**. Based on that reasoning, **CDE** could simply be the next sequence of letters.

## The CD signal

The **C** and **D** connections carry the DCC signal used by the booster to generate the track signal. Measurements taken on an **LZ100**, **LZV100** and **LZV200** show that **C** and **D** switch alternately between approximately 0 V and +12 V relative to ground. The two signals switch in opposite phase: when **C** is at 12 V, **D** is at 0 V, and vice versa. The voltage difference between **C** and **D** therefore alternates between approximately +12 V and −12 V.

The oscilloscope waveform below shows the **CD** signal of a LZV200.

CD signal LZV200

It is likely that Lenz uses an internal H-bridge to generate this **CD** signal. Without an H-bridge, additional circuitry would be necessary to generate both +12 V and −12 V relative to ground. This would require an additional DC converter, making the system unnecessarily complex and therefore more expensive. Note that the H-bridge only needs to supply a limited amount of power. Even on large model railway layouts with multiple boosters, the required current is expected to remain limited to a few hundred milliamps.

A legitimate question is whether the DCC voltage itself, or a 5 V differential signal, would suffice to generate the **CD** signal. To answer that question, we need to take a closer look at the input side of a modern booster. The schematic below shows the input side of the Paco booster.

CD booster ingang

The schematic contains two high speed optocouplers (6N136). The upper one is active when **C** is positive relative to **D**; the lower one when **C** is negative relative to **D**. This two-optocoupler configuration is necessary because there are three distinct states to consider: **C** higher than **D**, **C** lower than **D**, and the RailCom cut-out, where **C** is equal to **D**.

Crucial to this circuit is the 1 kΩ resistor connected in series with the **C** signal, which is usually a 250 mW resistor. At a **CD** voltage of 12 V, approximately 10.4 V is dropped across this resistor (a fixed forward voltage of V<sub>F</sub> = 1.6 V is dropped across the optocoupler). The resistor must then dissipate nearly 110 mW. At **CD** = 16 V, this rises to over 200 mW. At a voltage of 18 V or higher, a 250 mW resistor will be overloaded.

At a voltage of **5 V**, only **3.4 V** is dropped across the resistor, and the current through the optocoupler LED is therefore 3.4 mA. This is too low for the LEDs in the optocoupler to switch reliably at DCC speed.

## The E-signal

The **E** signal may be used by a booster to indicate a short circuit. To this end, both the Lenz and Paco boosters use an additional optocoupler (such as a PC817, see the diagram above). In the event of a short circuit, this optocoupler is activated, allowing current to flow from **E** to **D**. It is also possible to connect an emergency stop switch between **E** and **M** (Masse = Ground), as illustrated in the figure below taken from the Lenz LZV100 manual, allowing current to flow from **E** to **M**.

Not Aus

### Principle of Short-Circuit Detection

The diagram below shows a circuit that enables a DCC command station to detect a short-circuit or emergency stop signal.

Short-Circuit Detection

When the booster detects a short circuit, it activates the (PC817) optocoupler. If the voltage at **D** is higher than that at **E**, the diode (for example, a 1N4148) prevents current from flowing from **D** to **E**, leaving the voltage at **E** unaffected.
If the voltage at **D** is lower than that at **E**, current can flow from the booster’s **E** connection. That current flows via pin 4 (collector) and pin 3 (emitter) of the optocoupler and then back through the diode to the D connection. The booster therefore pulls **E** towards **D** via the optocoupler.

<B>The circuit therefore has a *low signal* during a short circuit or emergency stop, and a *high signal* during normal operation.</B>

### Normal operation
If no short circuit is reported, the circuit operates as follows. When the **C** signal is high, the 100 nF capacitor (C701) is charged via the 4.7 kΩ resistor (R703). The time required to charge the capacitor to its maximum voltage depends on the voltage and the precise shape of the DCC signal, but is in the order of a few milliseconds. The 1N4148 diode (D701) prevents the capacitor from discharging when the **C** signal is low.

To obtain a suitable input voltage for a 3V3 microcontroller, the voltage across the capacitor is reduced to approximately 25% of the original voltage using a voltage divider comprising 56 kΩ (R704) and 18 kΩ (R705) resistors. At a maximum **C** voltage of **12 V**, the node charges to: *V<sub>node</sub> = (12 − 0,7) × 18 / (56 + 18 + 4,7) ≈ 2,5 V*. The 100 pF capacitor (C702), together with the resistor divider, forms a low-pass filter with a cut-off frequency of around 100 kHz. This filter suppresses any high-frequency interference at the microcontroller’s input.

If a 5 V microcontroller is used instead of a 3.3 V microcontroller, the 18 kΩ resistor must be replaced with a 47 kΩ resistor.

### Short circuit

During a short circuit or emergency stop, the 100 nF capacitor may discharge via the **E** terminal, the optocoupler and the diode in the booster, to **D**. This discharge only occurs when the **D** signal is low, so for a maximum of 58 (DCC 1) or 100 (DCC 0) µs each time.

The voltage at **E** drops to the sum of the diode’s forward voltage and the optocoupler’s saturation voltage (*V*<sub>CE(sat)</sub>). This is typically around 0.7 to 1.1 V: approximately 0.6 V for the diode and 0.1 to 0.5 V for the optocoupler, depending on the degree to which the phototransistor is saturated. As the voltage divider reduces the voltage across the capacitor to approximately 25% of its original value, the voltage at the microcontroller input during a short circuit is typically only 0.2 to 0.4 V.

In the event of an EMERGENCY STOP, where **E** is connected directly to ground, the voltage at the microcontroller input is rapidly pulled down to 0 V.  At 12 V, this causes a current of less than 3 mA to flow through the 4.7 kΩ resistor. This current is low enough to prevent thermal overload of the resistor.

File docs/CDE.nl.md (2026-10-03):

[🇬🇧 English](CDE.md) | [🇩🇪 Deutsch](CDE.de.md) | [🇳🇱 Nederlands](CDE.nl.md)

# CDE Booster Interface

Het CDE-boosterinterface is, in tegenstelling tot DCC zelf, niet vastgelegd in een RCN- of NMRA-norm. Ook Lenz, de ontwikkelaar van dit interface, heeft hierover weinig technische informatie gepubliceerd. Op internet zijn wel verschillende schema's voor de boosterkant van het interface te vinden, waaronder de [Z21PG Booster](https://pgahtow.de/w/Booster#/media/Datei:Booster_v2.png) en [Paco's BoosteR-CDE](https://usuaris.tinet.cat/fmco/railcom_en.html#booster).

De oorsprong van de naam **CDE** is niet gedocumenteerd. Op sommige internetfora wordt gesuggereerd dat de letters staan voor **C**ommon, **D**ata en **E**rror. Dat zou een mogelijke verklaring kunnen zijn, maar past niet goed bij de huidige implementatie. Bij moderne centrales zijn **C** en **D** symmetrische ten opzichte van elkaar en vormen dus een differentieel signaal. Een andere mogelijkheid is dat Lenz de letters **A** en **B** al had gebruikt voor het XpressNet-interface. De RS-485-signalen waarop XpressNet is gebaseerd, worden immers vaak aangeduid als **A** en **B**. Vanuit die gedachte zou **CDE** eenvoudigweg de volgende letterreeks kunnen zijn.

## Het CD-signaal

De aansluitingen **C** en **D** voeren het DCC-signaal waarmee de booster het railsignaal genereert. Metingen aan een **LZ100**, **LZV100** en **LZV200** laten zien dat **C** en **D** ten opzichte van massa afwisselend tussen ongeveer 0 V en +12 V schakelen. De twee aansluitingen schakelen daarbij in tegengestelde fase: wanneer **C** op 12 V staat, is **D** 0 V, en omgekeerd. Het spanningsverschil tussen **C** en **D** bedraagt daardoor afwisselend ongeveer +12 V en −12 V.

De onderstaande oscilloscoopafbeelding toont ter illustratie het **CD signaal van de LZV200**. CD signaal LZV200.
Het is waarschijnlijk dat Lenz intern een H-brug gebruikt om dit CD-signaal te genereren. Zonder H-brug zou een schakeling nodig zijn die zowel +12 V als −12 V ten opzichte van massa kan genereren. Daarvoor zou een extra DC/DC-omzetter nodig zijn, waardoor de schakeling onnodig complex en dus duurder zou worden. Merk op dat de H-brug hiervoor maar weinig vermogen hoeft te leveren. Ook bij grote modelbanen met meerdere aangesloten boosters zal de benodigde stroom naar verwachting beperkt blijven tot enkele honderden milliampères.

Een legitieme vraag is of niet de DCC-spanning zelf, of een differentieel signaal van 5 V zou volstaan. Om die vraag te beantwoorden, moeten we iets beter kijken naar de ingang van de Paco-booster, zie onderstaand schema.

CD booster ingang

Het schema bevat twee snelle optocouplers (6N136). De bovenste is actief wanneer **C** positief is ten opzichte van **D**; de onderste wanneer **C** negatief is ten opzichte van **D**. Deze constructie met twee optocouplers is nodig omdat er drie te onderscheiden toestanden zijn: **C** hoger dan **D**, **C** lager dan **D**, en de RailCom-cutout, waarbij **C** gelijk is aan **D**.

Cruciaal in deze schakeling is de weerstand van 1 kΩ die in serie staat met het **C**-signaal. Dit is meestal een weerstand met een vermogen van 250 mW. Bij een **CD** spanning van 12 V, valt ongeveer 10,4 V over deze weerstand (over de optocoupler valt een vaste voorwaartse spanning van V<sub>F</sub> = 1,6 V). De weerstand moet dan bijna 110 mW dissiperen. Bij **CD** = 16 V loopt dit op tot ruim 200 mW. Bij een spanning van 18 V of hoger wordt een 250 mW-weerstand dus overbelast.

Bij een spanning van **5 V** valt er nog maar **3,4 V** over de weerstand en bedraagt de stroom door de optocoupler-LED dus 3,4 mA. Dat is voor de LEDs in de optocoupler te weinig om bij DCC-snelheid betrouwbaar te schakelen.

## Het E-signaal

Het **E**-signaal kan door een booster worden gebruikt om kortsluiting te melden. Daartoe gebruiken zowel de Lenz- als de Paco-boosters een additionele optocoupler (zoals een PC817, zie het bovenstaande schema). Bij een kortsluiting wordt deze optocoupler ingeschakeld, waardoor stroom kan vloeien tussen **E** en **D**. Daarnaast is het mogelijk om tussen **E** en **M** (Masse = GND) een noodstopschakelaar aan te sluiten. Zie hiervoor de onderstaande afbeelding uit de handleiding van de Lenz LZV100.

Not Aus

### Principe Kortsluitdetectie

Onderstaand schema toont een schakeling waarmee een DCC centrale een kortsluit- of noodstopmelding kan detecteren.

Kortsluitdetectie

Wanneer de booster een kortsluiting detecteert, activeert deze de optocoupler (bijvoorbeeld een PC817). Als de spanning op **D** hoger is dan die op **E**, spert de diode (bijvoorbeeld een 1N4148), waardoor er geen stroom kan vloeien en de spanning op **E** niet wordt beïnvloed.
Als de spanning op **D** lager is dan die op **E**, kan er wel stroom vloeien vanaf de **E**-aansluiting van de booster. Deze stroom loopt via pin 4 (collector) en pin 3 (emitter) van de optocoupler en vervolgens door de diode terug naar de **D**-aansluiting. De booster trekt **E** in dat geval dus via de optocoupler naar **D** toe.

<B>De schakeling heeft dus een *laag signaal* tijdens kortsluiting / noodstop, en een *hoog signaal* tijdens normaal bedrijf.</B>

### Normaal bedrijf
Als er geen kortsluiting wordt gemeld, werkt de schakeling als volgt. Wanneer het **C**-signaal hoog is, wordt de 100 nF-condensator (C701) via de 4,7 kΩ-weerstand (R703) opgeladen. De benodigde tijd om de condensator tot vrijwel zijn maximale spanning op te laden, hangt af van de spanning en de precieze vorm van het DCC-signaal, maar ligt in de orde van enkele milliseconden. De 1N4148-diode (D701) voorkomt dat de condensator zich ontlaadt wanneer het **C**-signaal laag is.

Om een geschikte spanning voor een 3V3-microcontrolleringang te verkrijgen, wordt de spanning over de condensator met een spanningsdeler van 56 kΩ (R704) en 18 kΩ (R705) verlaagd tot ongeveer 25% van de oorspronkelijke spanning. Bij een maximale **C** spanning van **12 V** laadt het knooppunt op tot: *V<sub>node</sub> = (12 − 0,7) × 18 / (56 + 18 + 4,7) ≈ 2,5 V*. De 100 pF-condensator (C702) vormt samen met de weerstands­deler een laagdoorlaatfilter met een afsnijfrequentie van ruim 100 kHz. Dit filter onderdrukt eventuele hoogfrequente storingen op de ingang van de microcontroller.

Mocht in plaats van een 3V3-microcontroller een 5V-microcontroller worden gebruikt, dan moet de weerstand van 18 kΩ worden vervangen door een weerstand van 47 kΩ.

### Kortsluiting

Tijdens een kortsluiting of noodstop kan de 100 nF-condensator via de **E**-aansluiting, de optocoupler en de diode in de booster naar **D** ontladen. Dit ontladen kan alleen plaatsvinden wanneer het **D**-signaal laag is, dus steeds maximaal 58 (DCC-1) of 100 (DCC-0) µs.

De spanning op **E** daalt daarbij tot de som van de doorlaatspanning van de diode en de verzadigingsspanning (*V*<sub>CE(sat)</sub>) van de optocoupler. Deze bedraagt typisch ongeveer 0,7 tot 1,1 V: circa 0,6 V voor de diode en 0,1 tot 0,5 V voor de optocoupler, afhankelijk van de mate waarin de fototransistor verzadigd is. Omdat de spanningsdeler de spanning over de condensator verlaagt tot ongeveer 25% van de oorspronkelijke waarde, bedraagt de spanning op de microcontrolleringang bij een kortsluiting typisch slechts 0,2 tot 0,4 V.

Bij een NOODSTOP, waarbij **E** rechtstreeks met massa wordt verbonden, wordt de spanning op de microcontrolleringang hard naar 0 V getrokken. Door de 4,7 kΩ-weerstand loopt daarbij minder dan 3 mA. Deze stroom is laag genoeg om bij 12 V niet thermisch overbelast te raken.

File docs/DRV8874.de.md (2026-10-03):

[🇬🇧 English](DRV8874.md) | [🇩🇪 Deutsch](DRV8874.de.md) | [🇳🇱 Nederlands](DRV8874.nl.md)

# DRV8874 Überstromabschaltung (OCP)

Der DRV8874 verfügt über eine integrierte Überstromabschaltung, genannt **IOCP**, die auslöst, wenn der Ausgangsstrom einen festen internen Schwellwert überschreitet. Dieser Schwellwert ist nicht konfigurierbar und ist mit mindestens 6 A und typisch 10 A spezifiziert. Überschreitet der Ausgangsstrom den **IOCP**-Schwellwert länger als 3 µs (*t*<sub>OCP</sub>), wird die H-Brücke abgeschaltet und der **nFAULT**-Ausgang auf Low gezogen.

Was anschließend geschieht, hängt von der Einstellung von **IMODE** ab. Im Autorestart-Modus (Quad-Level 1 oder 2) bleiben die Ausgänge für 2 ms (*t*<sub>RETRY</sub>) deaktiviert, bevor die H-Brücke wieder eingeschaltet wird. Besteht die Überlastung weiterhin, wiederholt sich dieser Zyklus. Im latched-off mode (Quad-Level 3 oder 4) bleiben die Ausgänge deaktiviert, bis der Baustein über **nSLEEP** oder durch Abschalten der Versorgungsspannung **VM** zurückgesetzt wird. Auch ein Reset über **nSLEEP** benötigt mindestens 2 ms (*t*<sub>SLEEP</sub> + *t*<sub>WAKE</sub>).

Es ist nicht möglich, **IOCP** zu deaktivieren oder seine Auslösung beispielsweise durch einen niedrigeren Wert des Stromreglers (**ITRIP**) zu verhindern. Der Grund dafür ist, dass der **ITRIP**-Regelkreis zu langsam reagiert.

Laut Datenblatt des DRV8874 setzt sich die Reaktionszeit aus mehreren Zeitanteilen zusammen: der Verzögerung des Stromspiegels *t*<sub>DELAY</sub> (1,6 µs), der Sperrzeit nach einer Schaltflanke *t*<sub>BLK</sub> (1,1 µs) sowie der Entprellzeit des Komparators *t*<sub>DEG</sub> (0,6 µs). Zusammen ergibt sich daraus eine absolute minimale Reaktionszeit von 3,3 µs.

In der Praxis ist die tatsächliche Reaktionszeit aufgrund zusätzlicher Verzögerungen im internen Komparator, in der Gate-Treiberlogik sowie durch eine eventuell an **IPROPI** angeschlossene Kapazität deutlich länger.

### Anforderungen an eine DCC-Ausgangsstufe

Eine DCC-Ausgangsstufe betreibt ein Gleis mit hoher kapazitiver Last. Lokomotiven und Wagen mit eingebauten Kondensatoren müssen diese beim Einschalten der Versorgungsspannung zunächst aufladen. Die dabei auftretenden Einschaltströme sind ein normaler Bestandteil des Betriebs und dürfen nicht als Fehlerzustand interpretiert werden.

Der Einschaltstrom wird durch **I = C × dV/dt** beschrieben. Ein vollständig entladener 1000-µF-Kondensator, der an eine DCC-Versorgung von 16 V angeschlossen wird, zieht beispielsweise einen Einschaltstrom, der nahezu ausschließlich durch die parasitären Widerstände und Induktivitäten des Gleissystems begrenzt wird. Dadurch steigt der Strom extrem schnell an und kann innerhalb von 3 µs den **IOCP**-Schwellwert von 6 bis 10 A überschreiten, wodurch OCP auslöst.

Wenn OCP auslöst, wird die H-Brücke für die Sperrzeit (*t*<sub>RETRY</sub>) von 2 ms deaktiviert. Während der vorausgehenden 3 µs konnte der Kondensator jedoch nur eine vernachlässigbare Ladung aufnehmen. Wird die H-Brücke anschließend wieder aktiviert, ist der Kondensator praktisch noch vollständig entladen und verursacht erneut denselben Einschaltstrom. OCP löst erneut aus, die H-Brücke wird wieder deaktiviert und dieser Zyklus wiederholt sich unbegrenzt. Dadurch erreicht der Kondensator niemals seine Betriebsspannung und das DCC-Signal wird niemals stabil.

### Einschaltstrombegrenzung

Es gibt keine einfache Methode, das Auslösen von OCP während des Ladens von Kondensatoren zu verhindern. DCC-EX löst dieses Problem durch eine spezielle PWM-Einschaltsequenz. Das Prinzip besteht darin, jeden Puls kürzer als die OCP-Reaktionszeit (etwa 3 µs) zu halten, sodass OCP nicht auslöst. Die AUS-Zeit muss kurz genug sein, um die Gleiskondensatoren innerhalb einer angemessenen Zeit aufzuladen, gleichzeitig aber lang genug, um die Erwärmung des DRV8874 zu begrenzen. DCC-EX verwendet hierfür eine AUS-Zeit von 13 µs, wobei eine längere AUS-Zeit vorteilhaft sein kann, um die Chiptemperatur zu senken. Unsere Implementierung schlägt daher eine EIN-Zeit von 2,5 µs vor, gefolgt von einer AUS-Zeit von 17,5 µs.

Wann und wie diese Sequenz gestartet wird, wie ein Einschaltstrom von einem Kurzschluss unterschieden wird und wie der Strom gemessen wird, ist in [Umgang mit nFAULTs](nFault.de.md) beschrieben.

### Implementierung der Einschaltstrombegrenzung

Der DRV8874 unterstützt sowohl den **PH/EN-Modus** als auch den **PWM-Modus** zur Erzeugung der 2,5-µs-Pulsfolge für die Einschaltstrombegrenzung. Um einen Gleichspannungsanteil auf dem Gleis zu vermeiden, muss der 2,5-µs-Puls bei beiden Polaritäten des DCC-Signals symmetrisch erzeugt werden.

Im **PH/EN-Modus** wird der 2,5-µs-Puls erzeugt, indem der **EN**-Eingang auf High gesetzt wird, während **PH** abwechselnd auf High und Low geschaltet wird. Während der 17,5-µs-AUS-Zeit muss **EN** auf Low liegen.

Im **PWM-Modus** wird der 2,5-µs-Puls erzeugt, indem entweder **IN1** oder **IN2** auf High gesetzt wird, während der jeweils andere Eingang auf Low bleibt.

Im **PWM-Modus** kann die 17,5-µs-AUS-Zeit entweder im **Coast-** oder im **Brake-Modus** realisiert werden. Bei Schaltungen ohne Ausgangsspule sind beide Modi geeignet; der praktische Unterschied ist in der Regel gering. Wird jedoch eine Ausgangsspule eingesetzt, ist der **Brake-Modus** im Allgemeinen vorzuziehen. Im **Coast-Modus** fließt der Spulenstrom über die Body-Dioden des DRV8874, während der **Brake-Modus** einen definierten Freilaufpfad über die Low-Side-MOSFETs bereitstellt.

### Ausgangsspule

Eine mögliche Hardwarelösung zur Verringerung des Einschaltstroms besteht darin, eine Leistungsdrossel zwischen den Ausgang der H-Brücke und das Gleis zu schalten. Die Drossel begrenzt die Stromanstiegsgeschwindigkeit, wodurch die Wahrscheinlichkeit sinkt, dass der **IOCP**-Schwellwert schon innerhalb der ersten Mikrosekunden nach dem Einschalten erreicht wird. Gleichzeitig reduziert sie die Flankensteilheit des Ausgangssignals und verringert dadurch EMV-Störungen sowie Überschwingen des DCC-Signals.

Die erforderliche Induktivität ergibt sich unmittelbar aus

**dI/dt = V/L** bzw. **L = V × t / I**

Soll beispielsweise der Strom nach 3 µs auf höchstens 6 A begrenzt werden und wird ein entladener Kondensator an die DCC-Versorgung von 16 V angeschlossen, liegen etwa 16 V über der Drossel und die erforderliche Induktivität beträgt

**L = 16 V × 3 µs / 6 A = 8 µH**

In der Praxis verschlechtert eine Induktivität dieser Größe die Signalqualität des DCC-Signals bereits merklich.

### Strommessung – ADC

Neben der Einstellung der programmierbaren Strombegrenzung (**ITRIP**) kann der **IPROPI**-Ausgang auch zur Messung des Gleisstroms mit einem ADC verwendet werden. Der **IPROPI**-Pin liefert einen Strom, der proportional zum Ausgangsstrom der H-Brücke ist. Fließt dieser Strom durch den **R<sub>IPROPI</sub>**-Widerstand, entsteht eine Spannung, die vom Mikrocontroller gemessen werden kann.

Für den DRV8874 gilt:

**V<sub>IPROPI</sub> = I<sub>OUT</sub> × R<sub>IPROPI</sub> × 450 µA/A**

Mit **R<sub>IPROPI</sub> = 2,49 kΩ** (dem Wert des **R<sub>IPROPI</sub>**-Widerstands auf den Pololu- und AliExpress-Modulen) ergibt sich eine Ausgangsspannung von etwa **1,12 V/A**. Bei einem Ausgangsstrom von 2,9 A beträgt die **IPROPI**-Spannung ungefähr **3,25 V**.

### Zusammenfassung

Der DRV8874 eignet sich als Ausgangsstufe einer DCC-Zentrale oder eines Boosters, seine fest integrierte **IOCP**-Überstromabschaltung erfordert jedoch besondere Aufmerksamkeit. Kapazitive Lasten auf dem Gleis können Einschaltströme erzeugen, die den **IOCP**-Schwellwert bereits innerhalb weniger Mikrosekunden überschreiten. Dies führt zu wiederholten Abschaltungen von jeweils 2 ms und verhindert einen störungsfreien DCC-Betrieb.

Da sich **IOCP** nicht deaktivieren lässt und die programmierbare Stromregelung (**ITRIP**) zu langsam reagiert, um dies zu verhindern, muss der Einschaltstrom softwareseitig begrenzt werden. DCC-EX verwendet hierzu eine spezielle Pulsfolge mit 3 µs EIN- und 13 µs AUS-Zeit, wodurch sich die Gleiskondensatoren schrittweise aufladen lassen, ohne **IOCP** auszulösen. Durch die Überwachung von **nFAULT** kann die Software zwischen dem vorübergehenden Laden von Kondensatoren und einem echten Kurzschluss auf dem Gleis unterscheiden: Im ersten Fall verschwinden die Fehler während oder nach der Inrush-Sequenz, im zweiten Fall bleiben sie bestehen. Eine Ausgangsdrossel (mit einem Snubber zur Dämpfung von Überschwingen) kann den Einschaltstrom zwar verringern, sie verschlechtert jedoch die Signalqualität des DCC-Signals und stellt daher einen Kompromiss und keine vollständige Lösung dar.

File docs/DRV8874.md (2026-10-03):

[🇬🇧 English](DRV8874.md) | [🇩🇪 Deutsch](DRV8874.de.md) | [🇳🇱 Nederlands](DRV8874.nl.md)

# DRV8874 OverCurrent Protection (OCP)

The DRV8874 has a built-in overcurrent protection, called **IOCP**, that triggers when the output current exceeds a fixed internal threshold. This threshold is not user-configurable and is specified as 6 A minimum, 10 A typical. If the output current exceeds **IOCP** for longer than 3 µs (*t*<sub>OCP</sub>), the H-bridge is disabled and the **nFAULT** pin is driven low.

What happens next depends on the **IMODE** setting. In automatic retry mode (Quad-Level 1 or 2), the outputs remain disabled for 2 ms (*t*<sub>RETRY</sub>), after which the H-bridge is re-enabled. If the overcurrent condition persists, the cycle repeats. In latched-off mode (Quad-Level 3 or 4), the outputs remain disabled until the device is reset via **nSLEEP** or by removing **VM**. Reset via **nSLEEP** also takes at least 2 ms (*t*<sub>SLEEP</sub> + *t*<sub>WAKE</sub>).

It is not possible to disable **IOCP** or prevent it from operating by, for example, configuring the current regulator (**ITRIP**) to a lower value. The reason is that the **ITRIP** current regulation loop responds too slowly.

According to the DRV8874 datasheet, the response consists of several timing components: the current mirror delay, *t*<sub>DELAY</sub> (1.6 µs), the blanking time after a switching edge, *t*<sub>BLK</sub> (1.1 µs), and the comparator deglitch time, *t*<sub>DEG</sub> (0.6 µs). Together these add up to an absolute minimum response time of 3.3 µs.

In practice, the actual response time is considerably longer due to additional delays introduced by the internal comparator, the gate-driver logic, and any capacitance present on the **IPROPI** pin.

### DCC Output Stage Requirements

A DCC output stage drives a track that presents a highly capacitive load. Locomotives and wagons equipped with onboard capacitors must charge these capacitors when power is first applied. The resulting inrush currents are a normal part of operation and must not be interpreted as a fault condition.

The inrush current is governed by **I = C × dV/dt**. For example, a fully discharged 1000 µF capacitor connected to a 16 V DCC supply will draw an inrush current that is limited almost entirely by the parasitic resistance and inductance of the circuit. As a result, the current rises extremely rapidly and can easily exceed the **IOCP** threshold of 6–10 A within 3 µs, causing OCP to trigger.

When OCP triggers, the H-bridge is disabled for the retry interval (*t*<sub>RETRY</sub>) of 2 ms. However, during the preceding 3 µs the capacitor has accumulated only a negligible amount of charge. Consequently, when the H-bridge is re-enabled, the capacitor is still essentially discharged and generates the same inrush current again. OCP triggers once more, the H-bridge is disabled again, and the cycle repeats indefinitely. As a result, the capacitor never reaches its operating voltage and the DCC signal never becomes stable.

### Inrush Handling

There is no simple way to prevent OCP from triggering during capacitor inrush. DCC-EX, among others, solves this by using a dedicated PWM inrush sequence. The principle is to keep each ON pulse shorter than the OCP response time (approximately 3 µs), preventing OCP from triggering. The OFF time must be short enough to charge the track capacitors within a reasonable time, yet long enough to limit the heating of the DRV8874. DCC-EX uses an OFF time of 13 µs, although a longer OFF time may be desirable to reduce chip temperature. Our implementation therefore proposes an ON time of 2.5 µs, followed by an OFF time of 17.5 µs.

When and how this sequence is started, how an inrush is distinguished from a short circuit, and how the current is measured, is described in [Dealing with nFAULTs](nFault.md).

### Inrush Protection Implementation

The DRV8874 supports both **PH/EN mode** and **PWM mode** for implementing the inrush 2.5 µs pulse sequence. To avoid introducing a DC offset on the track, the 2.5 µs pulse must be applied symmetrically during both polarities of the DCC waveform.

In the DRV8874 **PH/EN mode**, the 2.5 µs pulse is generated by setting the **EN** input high while driving **PH** alternately high and low. During the 17.5 µs OFF period, **EN** must be low.

In the DRV8874 **PWM mode**, the 2.5 µs pulse is generated by driving either **IN1** or **IN2** high while keeping the other input low.

In **PWM mode** the 17.5 µs OFF period can be implemented using **coast** or **brake** mode. For designs without an output inductor, both modes are functionally suitable and the practical difference is generally small. When an output inductor is fitted, however, **brake** mode is generally preferred. In **coast** mode, the inductor current commutates through the DRV8874 body diodes, whereas **brake** mode provides a controlled freewheel path through the low-side MOSFETs.

### Output Inductor

One possible hardware solution to reduce the effect of capacitor inrush current is to place a power inductor between the H-bridge output and the track. The inductor limits the rate at which the output current can increase, making it less likely that the **IOCP** threshold is reached during the first few microseconds after power is applied. As an additional benefit, the inductor also reduces the output slew rate, lowering EMI and ringing on the DCC signal.

The required inductance follows directly from
**dI/dt = V/L** or **L = V × t / I**

For example, if the objective is to limit the current to 6 A after 3 µs, and a discharged capacitor is connected to the 16 V DCC supply, the voltage across the inductor is about 16 V and the required inductance is

**L = 16 V × 3 µs / 6 A = 8 µH**

In practice, an inductance of this size already degrades the DCC signal quality noticeably.

### Current Measurement - ADC

Besides providing the programmable current regulation threshold (**ITRIP**), the **IPROPI** output can also be used to measure the track current with an ADC. The **IPROPI** pin sources a current proportional to the H-bridge output current. Passing this current through the **R<sub>IPROPI</sub>** resistor produces a voltage that can be sampled by the microcontroller.

For the DRV8874, the relationship is: **V<sub>IPROPI</sub> = I<sub>OUT</sub> × R<sub>IPROPI</sub> × 450 µA/A**

With **R<sub>IPROPI</sub> = 2.49 kΩ** (the value of the **R<sub>IPROPI</sub>** resistor on the Pololu / AliExpress modules), the output voltage becomes approximately **1.12 V/A**. An output current of 2.9 A produces an **IPROPI** voltage of approximately **3.25 V**.

### Summary

The DRV8874 can be used as output stage of a DCC command station or booster, but its fixed **IOCP** protection requires special consideration. Capacitive loads on the track can generate inrush currents that exceed the **IOCP** threshold within a few microseconds, causing repeated 2 ms shutdown cycles that prevent normal DCC operation.

Because **IOCP** cannot be disabled and the programmable current regulation (**ITRIP**) responds too slowly to prevent it, capacitor inrush must be handled in software. DCC-EX uses a dedicated 3 µs / 13 µs pulse sequence to charge the track capacitors gradually without triggering **IOCP**. Monitoring **nFAULT** enables the software to distinguish temporary capacitor charging from a genuine track short circuit: the faults disappear during or after the inrush sequence in the first case, and persist in the second case. Although an output inductor (with a snubber to damp ringing) can reduce the inrush current, it degrades DCC signal quality and therefore represents a compromise rather than a complete solution.

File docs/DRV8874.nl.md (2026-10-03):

[🇬🇧 English](DRV8874.md) | [🇩🇪 Deutsch](DRV8874.de.md) | [🇳🇱 Nederlands](DRV8874.nl.md)

# DRV8874 Overstroombeveiliging (OCP)

De DRV8874 beschikt over een ingebouwde overstroombeveiliging, **IOCP** genoemd, die wordt geactiveerd wanneer de uitgangsstroom een vaste interne drempel overschrijdt. Deze drempel is niet door de gebruiker instelbaar en is gespecificeerd als minimaal 6 A en typisch 10 A. Wanneer de uitgangsstroom langer dan 3 µs (*t*<sub>OCP</sub>) boven de **IOCP**-drempel blijft, wordt de H-brug uitgeschakeld en wordt de **nFAULT**-uitgang laag gemaakt.

Wat er vervolgens gebeurt, hangt af van de instelling van **IMODE**. In de automatische herstartmodus (Quad-Level 1 of 2) blijven de uitgangen gedurende 2 ms (*t*<sub>RETRY</sub>) uitgeschakeld, waarna de H-brug opnieuw wordt ingeschakeld. Blijft de overstroomsituatie bestaan, dan herhaalt deze cyclus zich. In de vergrendelde modus (Quad-Level 3 of 4) blijven de uitgangen uitgeschakeld totdat de chip wordt gereset via **nSLEEP** of door de voedingsspanning **VM** te verwijderen. Ook een reset via **nSLEEP** duurt minimaal 2 ms (*t*<sub>SLEEP</sub> + *t*<sub>WAKE</sub>).

Het is niet mogelijk **IOCP** uit te schakelen of de werking ervan te voorkomen door bijvoorbeeld de stroomregelaar (**ITRIP**) op een lagere waarde in te stellen. De reden hiervoor is dat de **ITRIP**-regelkring te traag reageert.

Volgens het DRV8874-datasheet bestaat de reactietijd uit verschillende componenten: de vertraging van de stroomspiegel, *t*<sub>DELAY</sub> (1,6 µs), de blankingtijd na een schakelflank, *t*<sub>BLK</sub> (1,1 µs), en de deglitch-tijd van de comparator, *t*<sub>DEG</sub> (0,6 µs). Samen vormen deze een absolute minimale reactietijd van 3,3 µs.

In de praktijk is de werkelijke reactietijd aanzienlijk langer door extra vertragingen in de interne comparator, de gate-driverlogica en eventuele capaciteit op de **IPROPI**-pin.

### Eisen aan een DCC-uitgangstrap

Een DCC-uitgangstrap stuurt een spoor aan dat zich elektrisch gedraagt als een sterk capacitieve belasting. Locomotieven en rijtuigen met ingebouwde condensatoren moeten deze condensatoren opladen zodra de baanspanning wordt ingeschakeld. De daarbij optredende inschakelstromen zijn een normaal onderdeel van de werking en mogen niet als een foutconditie worden beschouwd.

De inschakelstroom wordt bepaald door **I = C × dV/dt**. Een volledig ontladen condensator van 1000 µF die wordt aangesloten op een DCC-spanning van 16 V zal bijvoorbeeld een inschakelstroom trekken die vrijwel uitsluitend wordt begrensd door de parasitaire weerstand en inductie van de schakeling. Hierdoor stijgt de stroom zeer snel en kan de **IOCP**-drempel van 6–10 A al binnen 3 µs worden overschreden, waardoor OCP wordt geactiveerd.

Wanneer OCP aanspreekt, wordt de H-brug gedurende de herstarttijd (*t*<sub>RETRY</sub>) van 2 ms uitgeschakeld. Gedurende de voorafgaande 3 µs heeft de condensator echter slechts een verwaarloosbare hoeveelheid lading kunnen opnemen. Wanneer de H-brug vervolgens opnieuw wordt ingeschakeld, is de condensator dus nog vrijwel volledig ontladen en ontstaat opnieuw dezelfde inschakelstroom. OCP wordt opnieuw geactiveerd, de H-brug schakelt weer uit en deze cyclus blijft zich eindeloos herhalen. Hierdoor bereikt de condensator nooit zijn normale bedrijfsspanning en wordt het DCC-signaal nooit stabiel.

### Behandeling van inschakelstromen

Er bestaat geen eenvoudige manier om te voorkomen dat OCP aanspreekt tijdens het opladen van condensatoren. DCC-EX lost dit op door gebruik te maken van een speciale PWM-sequentie voor inschakelstromen. Het uitgangspunt is dat iedere AAN-puls korter blijft dan de reactietijd van OCP (ongeveer 3 µs), zodat OCP niet wordt geactiveerd. De UIT-tijd moet kort genoeg zijn om de condensatoren binnen een redelijke tijd op te laden, maar tegelijkertijd lang genoeg om de opwarming van de DRV8874 te beperken. DCC-EX gebruikt hiervoor een UIT-tijd van 13 µs, hoewel een langere UIT-tijd wenselijk kan zijn om de chiptemperatuur te verlagen. Onze implementatie stelt daarom een AAN-tijd van 2,5 µs voor, gevolgd door een UIT-tijd van 17,5 µs.

Wanneer en hoe deze sequentie wordt gestart, hoe een inschakelstroom van een kortsluiting wordt onderscheiden en hoe de stroom wordt gemeten, is beschreven in [Omgaan met nFAULTs](nFault.nl.md).

### Implementatie van de inschakelbeveiliging

De DRV8874 ondersteunt zowel de **PH/EN**-modus als de **PWM**-modus voor het implementeren van de 2,5 µs pulsjes voor inschakelbeveiliging. Om te voorkomen dat een gelijkspanningscomponent op de rails ontstaat, moet de puls van 2,5 µs symmetrisch worden toegepast tijdens beide polariteiten van het DCC-signaal.

In de **PH/EN**-modus wordt de puls van 2,5 µs gegenereerd door **EN** hoog te maken, terwijl **PH** afwisselend hoog en laag wordt gestuurd. Tijdens de UIT-periode van 17,5 µs moet **EN** laag zijn.

In de **PWM**-modus wordt de puls van 2,5 µs gegenereerd door beurtelings **IN1** of **IN2** hoog te maken, terwijl de andere ingang laag blijft.

In de **PWM**-modus kan de UIT-periode van 17,5 µs worden gerealiseerd met **coast**- of **brake**-modus. Bij ontwerpen zonder uitgangsspoel zijn beide modi functioneel geschikt en is het praktische verschil doorgaans klein. Wanneer echter een uitgangsspoel wordt toegepast, heeft **brake**-modus over het algemeen de voorkeur. In **coast**-modus loopt de spoelstroom via de bodydiodes van de DRV8874, terwijl **brake**-modus een gecontroleerd vrijlooppad via de low-side MOSFET's biedt.

### Uitgangsspoel

Een mogelijke hardwareoplossing om de invloed van inschakelstromen te verminderen is het plaatsen van een vermogensspoel tussen de uitgang van de H-brug en het spoor. De spoel beperkt de snelheid waarmee de uitgangsstroom kan toenemen, waardoor de kans kleiner wordt dat de **IOCP**-drempel tijdens de eerste microseconden na het inschakelen wordt overschreden. Een bijkomend voordeel is dat de spoel tevens de flanksnelheid van het uitgangssignaal verlaagt, waardoor EMI en ringing op het DCC-signaal afnemen.

De benodigde inductie volgt direct uit:

**dI/dt = V/L** of **L = V × t / I**

Wanneer bijvoorbeeld de stroom na 3 µs moet worden beperkt tot 6 A en een ontladen condensator wordt aangesloten op de DCC-voeding van 16 V, staat er ongeveer 16 V over de spoel en bedraagt de benodigde inductie:

**L = 16 V × 3 µs / 6 A = 8 µH**

In de praktijk verslechtert een inductie van deze grootte de kwaliteit van het DCC-signaal al merkbaar.

### Stroommeting met de ADC

Naast het instellen van de programmeerbare stroombegrenzing (**ITRIP**) kan de **IPROPI**-uitgang ook worden gebruikt om de stroom die naar de rails loopt met een ADC te meten. De **IPROPI**-pin levert een stroom die evenredig is met de uitgangsstroom van de H-brug. Door deze stroom door de **R<sub>IPROPI</sub>** weerstand te laten lopen ontstaat een spanning die door de microcontroller kan worden gemeten.

Voor de DRV8874 geldt de relatie: **V<sub>IPROPI</sub> = I<sub>OUT</sub> × R<sub>IPROPI</sub> × 450 µA/A**

Bij **R<sub>IPROPI</sub> = 2,49 kΩ** (de waarde van de voorgemonteerde **R<sub>IPROPI</sub>** weerstand op de Pololu / AliExpress modules) bedraagt de uitgangsspanning ongeveer **1,12 V/A**. Een uitgangsstroom van 2,9 A resulteert dan in een **IPROPI**-spanning van ongeveer **3,25 V**.

### Samenvatting

De DRV8874 is bruikbaar als uitgangstrap van een DCC-centrale of booster, maar de vaste **IOCP**-overstroombeveiliging vraagt om bijzondere aandacht. Capacitieve belastingen op de baan kunnen inschakelstromen veroorzaken die de **IOCP**-drempel al binnen enkele microseconden overschrijden. Hierdoor wordt de H-brug telkens gedurende 2 ms uitgeschakeld, waardoor normaal DCC-gebruik onmogelijk wordt.

Omdat **IOCP** niet kan worden uitgeschakeld en de programmeerbare stroomregeling (**ITRIP**) te traag reageert om dit te voorkomen, moet de inschakelstroom softwarematig worden begrensd. DCC-EX gebruikt hiervoor een speciale pulssequentie van 3 µs AAN en 13 µs UIT, waarmee de condensatoren op de baan geleidelijk kunnen worden opgeladen zonder **IOCP** te activeren. Door **nFAULT** te bewaken, kan de software onderscheid maken tussen het tijdelijk opladen van condensatoren en een echte kortsluiting op de baan: in het eerste geval verdwijnen de storingen tijdens of na de inrush-sequentie, in het tweede geval blijven ze bestaan. Hoewel een uitgangsspoel (met een snubber om ringing te dempen) de inschakelstroom kan verminderen, gaat dit ten koste van de signaalkwaliteit van het DCC-signaal en vormt het dus een compromis in plaats van een volledige oplossing.

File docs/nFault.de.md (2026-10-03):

[🇬🇧 English](nFault.md) | [🇩🇪 Deutsch](nFault.de.md) | [🇳🇱 Nederlands](nFault.nl.md)

# Umgang mit nFAULTs

Der DRV8874 ist, wie andere moderne integrierte H-Brücken-Treiber, für (induktive) Motoranwendungen ausgelegt und kann beim Einsatz in (kapazitiven) DCC-Modellbahnanwendungen problematisch sein. Die Hauptprobleme stammen von den eingebauten Stromschutzmechanismen, die innerhalb weniger Mikrosekunden reagieren und damit für Modellbahnen zu schnell sind.

Es gibt zwei Arten von Stromschutz: OCP und ITRIP.

## OCP
OCP ist der eingebaute Überstromschutzmechanismus (OverCurrent Protection), der reagiert, wenn der Ausgangsstrom für 3 µs oder länger mehr als 6 (minimal) bis 10 (typisch) Ampere beträgt. Ist der DRV8874 auf Quad-Level 2 konfiguriert (= automatischer Neustart; wie bei der LZ210-TMC), zieht OCP nFAULT auf Low und schaltet das DCC-Ausgangssignal für 2 ms ab. Nach 2 ms erscheint das DCC-Signal wieder, wie in der folgenden Abbildung gezeigt.

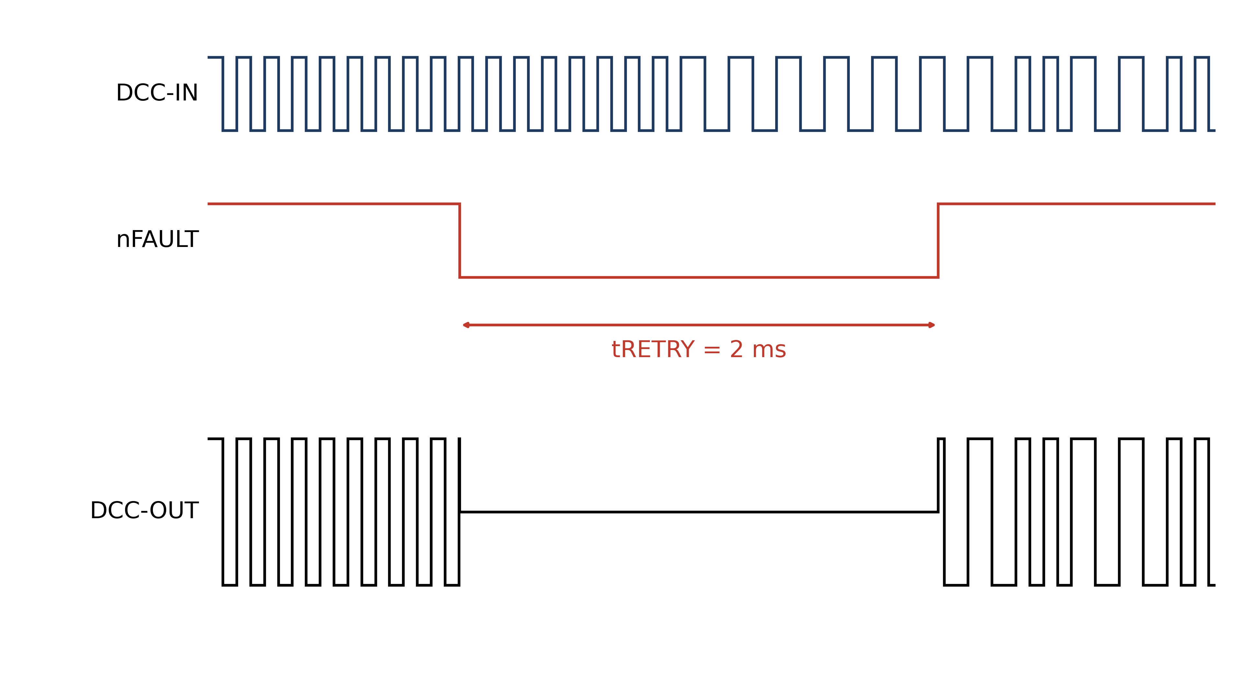
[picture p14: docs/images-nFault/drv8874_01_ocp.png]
OCP-Fehler


Bleibt die Ursache des OCP-Fehlers bestehen, wird nFAULT nach 2 ms erneut aktiv, sobald der Ausgang wieder eingeschaltet wird, wie in der folgenden Abbildung gezeigt.

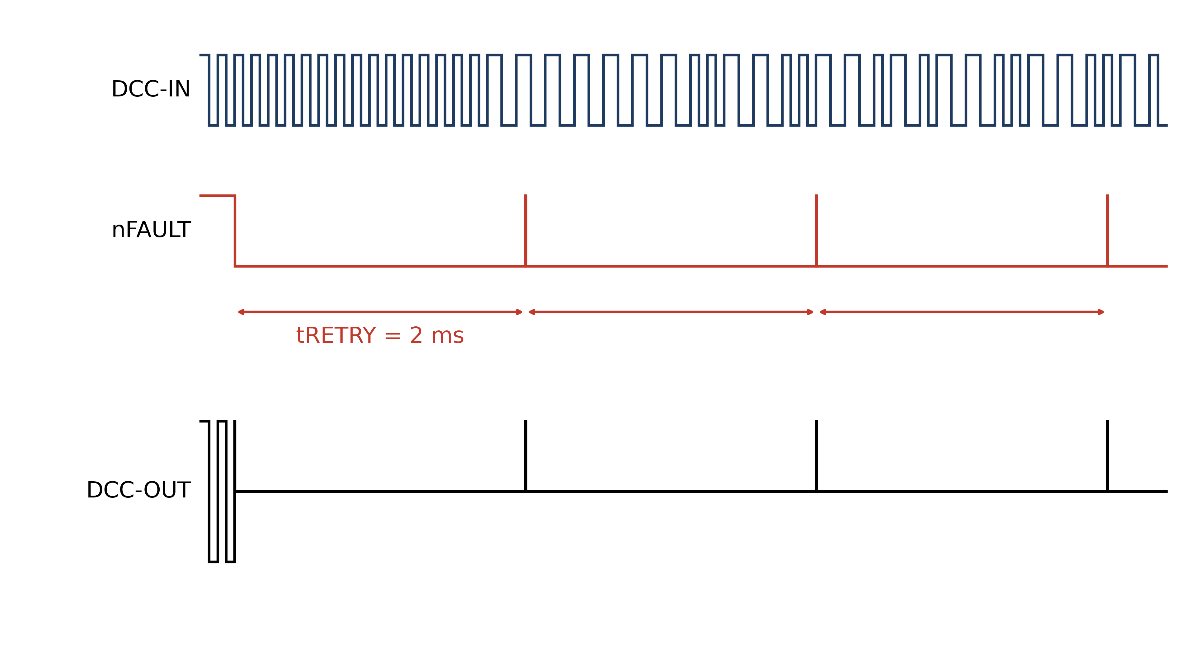
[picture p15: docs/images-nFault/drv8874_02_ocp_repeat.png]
Wiederholter OCP-Fehler


## ITRIP
ITRIP ist der eingebaute Stromregelmechanismus. Er vergleicht die Spannung über dem Sense-Widerstand (IPROPI) mit VREF. Überschreitet der Ausgangsstrom ITRIP länger als einige Mikrosekunden, wird das DCC-Ausgangssignal abgeschaltet. In Quad-Level 2 (= Cycle-By-Cycle) zieht der DRV8874 nFAULT auf Low, bis zur nächsten Flanke des Eingangssignals. Bei dieser Flanke wird nFAULT freigegeben und der Ausgang folgt wieder dem Eingang, wie in der folgenden Abbildung gezeigt.

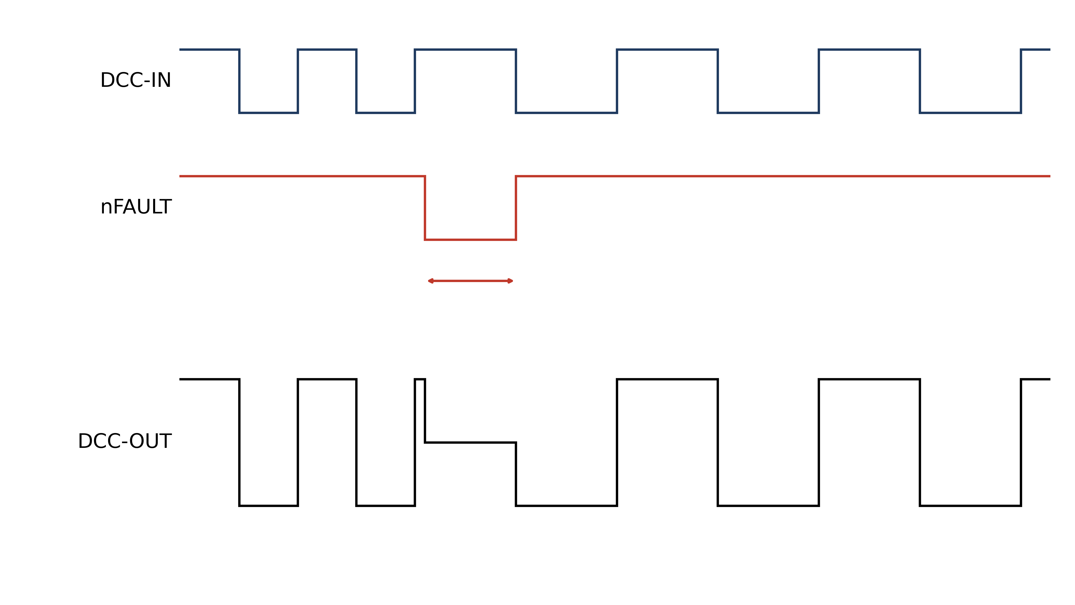
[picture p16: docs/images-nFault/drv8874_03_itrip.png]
ITRIP-Fehler


Im Gegensatz zu OCP schaltet ITRIP den Ausgang nicht für eine feste Zeit ab, sondern für den Rest des aktuellen Halbbits: höchstens 58 µs bei einem 1-Bit und 100 µs bei einem 0-Bit. Dennoch wird auch in diesem Fall das DCC-Ausgangssignal verfälscht.

Bleibt die Ursache des ITRIP-Fehlers bestehen, wird nFAULT nach jeder Flanke des Eingangssignals erneut aktiv, sobald der Ausgang wieder eingeschaltet wird, also alle 58 oder 100 µs. Dies zeigt die folgende Abbildung.

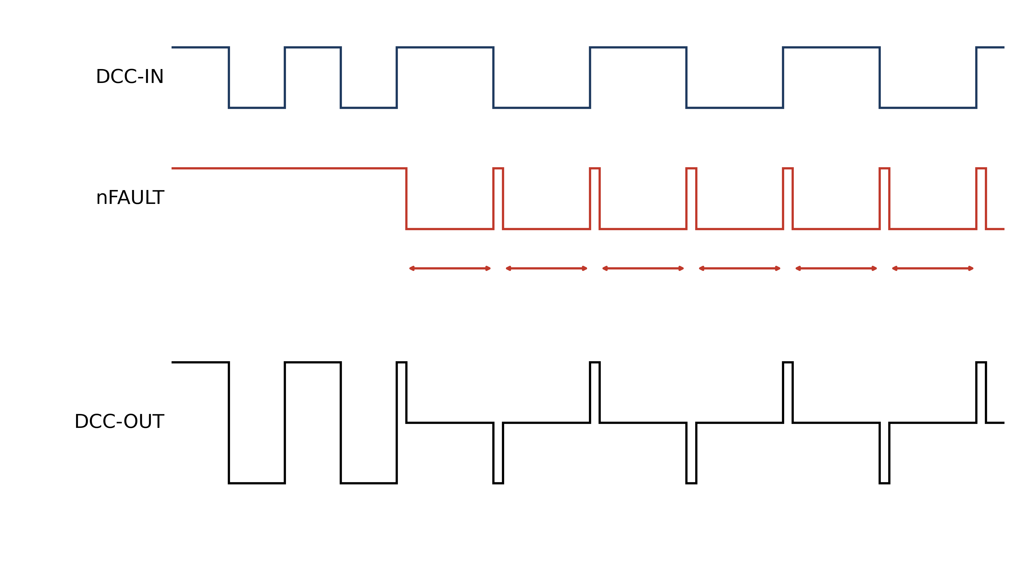
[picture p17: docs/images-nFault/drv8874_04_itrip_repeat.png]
Wiederholter ITRIP-Fehler


## Warum Überstrom?
Auf einer DCC-Modellbahnanlage gibt es mehrere mögliche Ursachen für einen Überstrom:
1. Die Last benötigt mehr Strom, als der DRV8874 liefern kann. Dies kann daran liegen, dass die Lokomotiven und Wagen zu viel Strom aufnehmen. Eine mögliche Abhilfe ist, den Wert des Sense-Widerstands (IPROPI) zu verringern, wodurch die ITRIP-Schwelle steigt.
2. Die Gleisspannung wurde gerade eingeschaltet. Kondensatoren in Lokomotiven und Wagen können beim Laden zunächst einen hohen Einschaltstrom (Inrush) ziehen. Dies kann den Stromschutz vorübergehend auslösen. Sind die Kondensatoren geladen, sinkt der Strom normalerweise wieder auf seinen normalen Wert.
3. Auf dem Gleis liegt ein Kurzschluss vor. In diesem Fall bleibt der Überstrom bestehen, bis der Kurzschluss beseitigt ist. Wichtig ist die Unterscheidung zwischen dauerhaften Kurzschlüssen, wie einer entgleisten Lokomotive, und vorübergehenden Mikrokurzschlüssen, wie kurzzeitigem Kontakt von Spurkränzen am Herzstück von Weichen.

Abhängig von der Ursache sind unterschiedliche Abhilfen möglich. In Fall 1 kann die Hardware angepasst werden, zum Beispiel durch Erhöhen der ITRIP-Schwelle. In Fall 2 können Softwaremaßnahmen wie ein spezielles Inrush-Signal beim Einschalten helfen. In Fall 3 verschwinden Mikrokurzschlüsse von selbst, ein echter Kurzschluss muss jedoch immer erkannt und beseitigt werden. In der Praxis tritt beim DRV8874 häufig eine Kombination aus Fall 1 (hohe mittlere Last) und Fall 2 (kurze Inrush-Last) auf, was die Lösung des Problems erschwert.

## Unterscheidung zwischen OCP- und ITRIP-Fehlern

Bevor Maßnahmen gewählt werden, ist es wichtig festzustellen, ob der Fehler durch OCP oder ITRIP verursacht wurde. Dies lässt sich durch Messen des Abstands zwischen aufeinanderfolgenden nFAULT-Ereignissen feststellen: Erkennt der Prozessor das erste nFAULT-Ereignis, startet er einen Timer und wechselt in einen besonderen Zustand.
1. Innerhalb der nächsten 2 ms treten mehrere neue nFAULT-Ereignisse auf. **Der Fehler wurde durch ITRIP ausgelöst**. Die genaue Anzahl der Ereignisse kann über die Weboberfläche gemeldet werden.
2. Das nächste nFAULT-Ereignis tritt nach etwa 2 ms auf. **Der Fehler wurde durch OCP ausgelöst**. Die Software sollte vermutlich einen Bereich von 1,5 bis 3 ms verwenden, um Zeittoleranzen zu berücksichtigen.
3. Innerhalb der nächsten Millisekunden tritt kein neues nFAULT-Ereignis auf. Das Problem kann durch Mikrokurzschlüsse verursacht worden sein. Es sind keine besonderen Maßnahmen erforderlich, und Statistiken zu diesen Ereignissen können über die Weboberfläche gemeldet werden.

## Maßnahmen bei OCP-Fehlern

Bei einem OCP-Fehler ist es wichtig, zwischen einem Inrush-Problem und einem Kurzschluss auf dem Gleis zu unterscheiden. Ein möglicher Ansatz ist, ein spezielles Inrush-Signal zu senden, das aus einem kurzen EIN-Puls von 2,5 µs besteht, der kürzer ist als die 3 µs, die zum Auslösen von OCP nötig sind, gefolgt von 17,5 µs AUS. Dadurch können sich Kondensatoren aufladen, während verhindert wird, dass OCP nach 2 ms erneut einen nFAULT auslöst.

Dies zeigt die folgende Abbildung. Nachdem der Prozessor das erste nFAULT erkannt hat, startet er einen Timer. Erkennt der Prozessor nach etwa 2 ms ein zweites nFAULT-Ereignis, wechselt er in den Inrush-Modus.

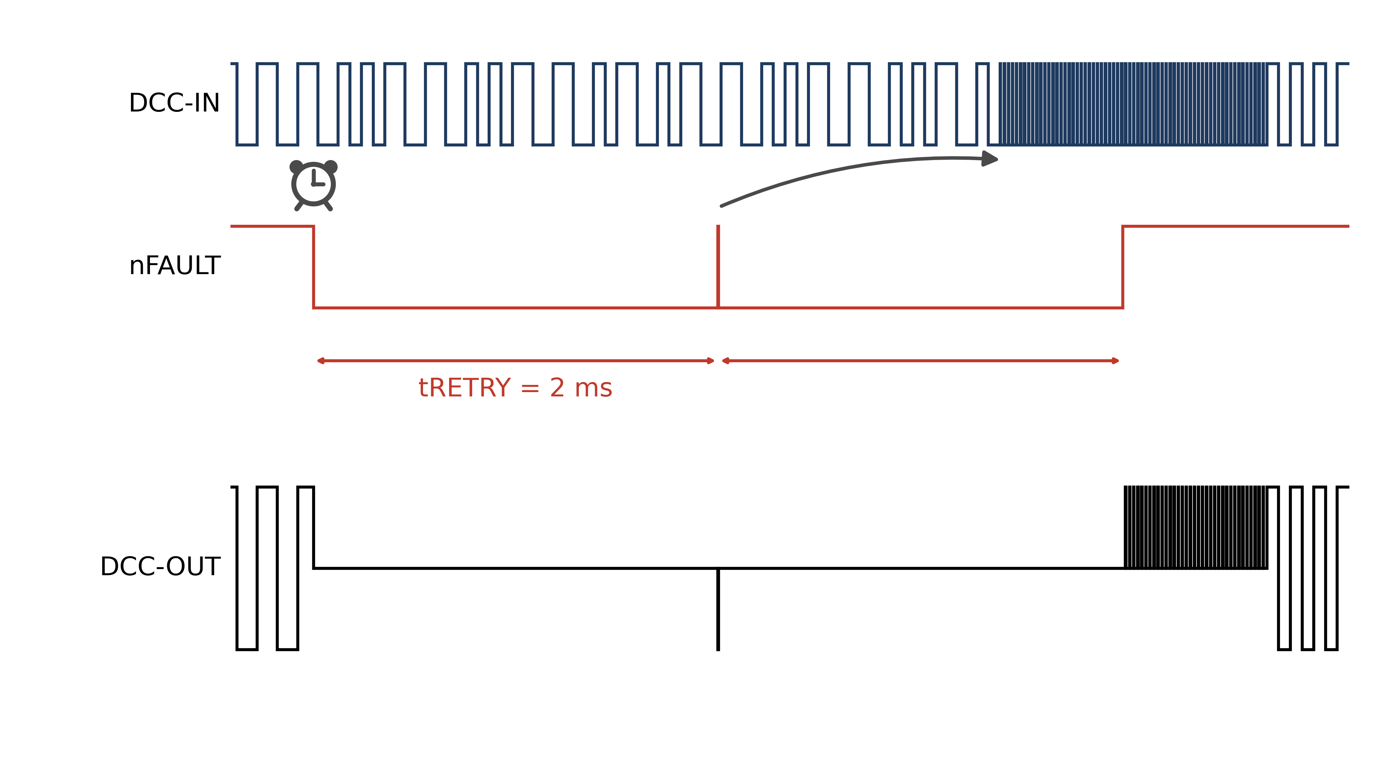
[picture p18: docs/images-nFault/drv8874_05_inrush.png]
Inrush-Muster


Wie in der obigen Abbildung zu sehen ist, erscheint das Inrush-Muster nicht sofort, sondern erst, nachdem das aktuelle DCC-Paket vollständig gesendet wurde. Da die Länge eines DCC-Pakets (grob) zwischen 6 und 13 ms liegen kann, ist es möglich, dass noch mehrere nFAULTs auftreten, bevor das Inrush-Muster am Ausgang erscheint.

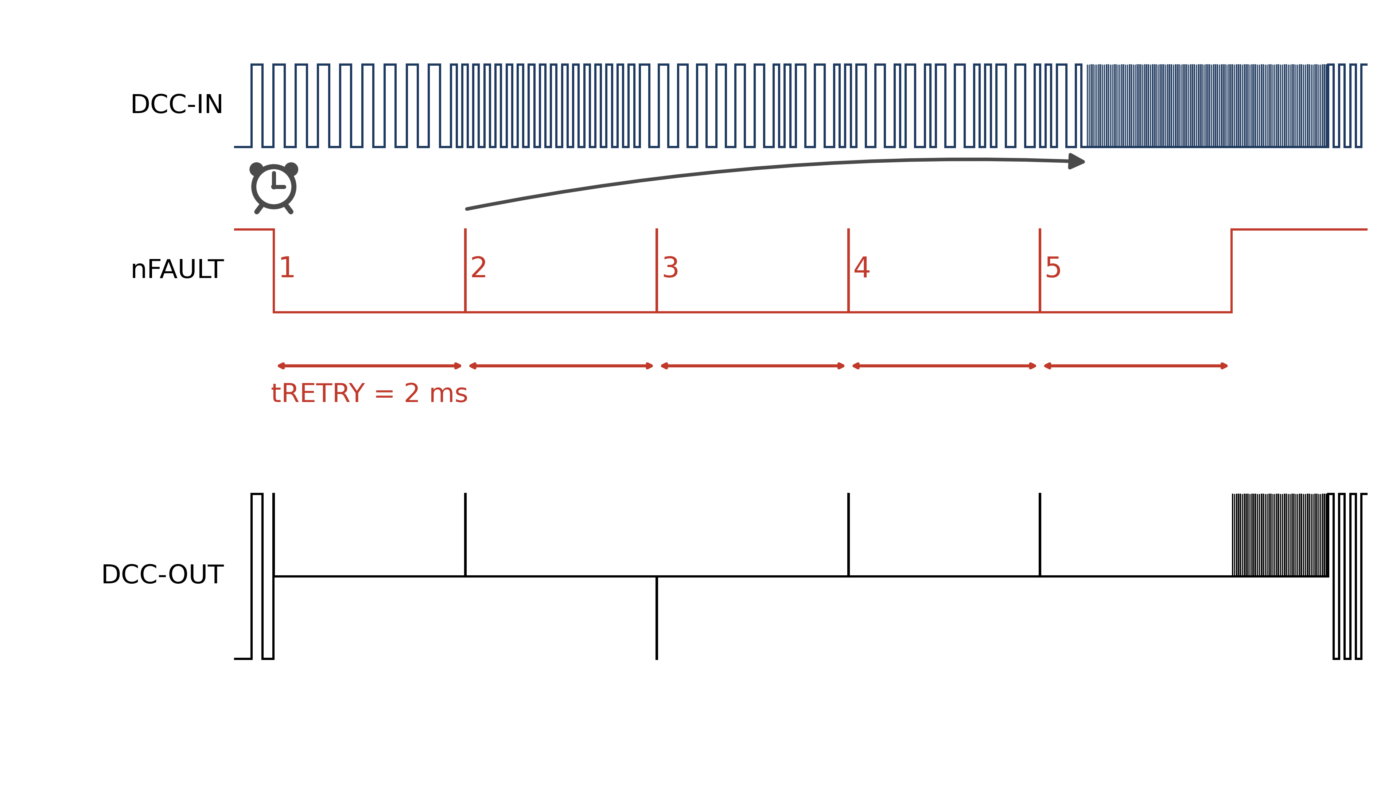
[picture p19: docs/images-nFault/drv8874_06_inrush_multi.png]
Inrush-Muster


Sobald das Inrush-Muster erscheint, werden die Kondensatoren geladen. Für einen 1000-µF-Kondensator kann die erforderliche Ladezeit 10 bis 20 ms betragen. Das Inrush-Muster sollte daher mindestens 20 ms auf dem Gleis anliegen, bevor es eine Wirkung zeigt, danach wird der normale DCC-Betrieb wieder aufgenommen. Treten danach erneut nFAULTs auf, liegt wahrscheinlich ein Kurzschluss vor und das DCC-Signal wird abgeschaltet (siehe die Empfehlung unten).

Es ist jedoch wichtig, dass das Inrush-Muster nicht zu lange dauert. Da die Pulse kürzer sind als die OCP-Entprellzeit, löst OCP nie aus, wodurch die Gefahr besteht, dass der DRV8874 überhitzt. Weil die Pulse sehr kurz sind, kann sich die Wärme möglicherweise nicht schnell genug ausbreiten, um die interne thermische Abschaltung (TSD) auszulösen, und der Chip kann dadurch zerstört werden.

Daher könnte die Software die Spannung über dem Sense-Widerstand (IPROPI) überwachen, um zu prüfen, ob der Strom hoch bleibt oder langsam abnimmt. Bleibt er hoch, liegt wahrscheinlich ein Kurzschluss auf dem Gleis vor und der Prozessor sollte das Ausgangssignal abschalten. Nimmt der Strom ab, wurde OCP wahrscheinlich durch den Einschaltstrom von Kondensatoren ausgelöst, und der Prozessor kann länger im Inrush-Modus bleiben.

Die Messung der Spannung über dem Sense-Widerstand ist nicht trivial. Die Pulse sind sehr kurz, und die Form des Signals am ADC-Eingang hängt davon ab, ob der im DRV8874-Datenblatt vorgeschlagene 10-nF-Kondensator bestückt ist. Die folgende Abbildung veranschaulicht dies für Stromspitzen von 10 A (idealisiert: die interne IPROPI-Klemmung begrenzt die tatsächliche Spannung). Ohne den Kondensator sind die Spitzen hoch, dauern aber weniger als 1 µs. Der ADC kann sie nur im Free-Running-Modus erfassen, und nicht jeder Puls wird erfasst: Bei 20 Samples mit 500 kS/s (40 µs) sollte der Prozessor den höchsten gemessenen Wert auswählen. Mit dem Kondensator beträgt die maximale Spannung nur etwa 0,4 V und fällt mit einer Zeitkonstante von etwa 13 µs ab.

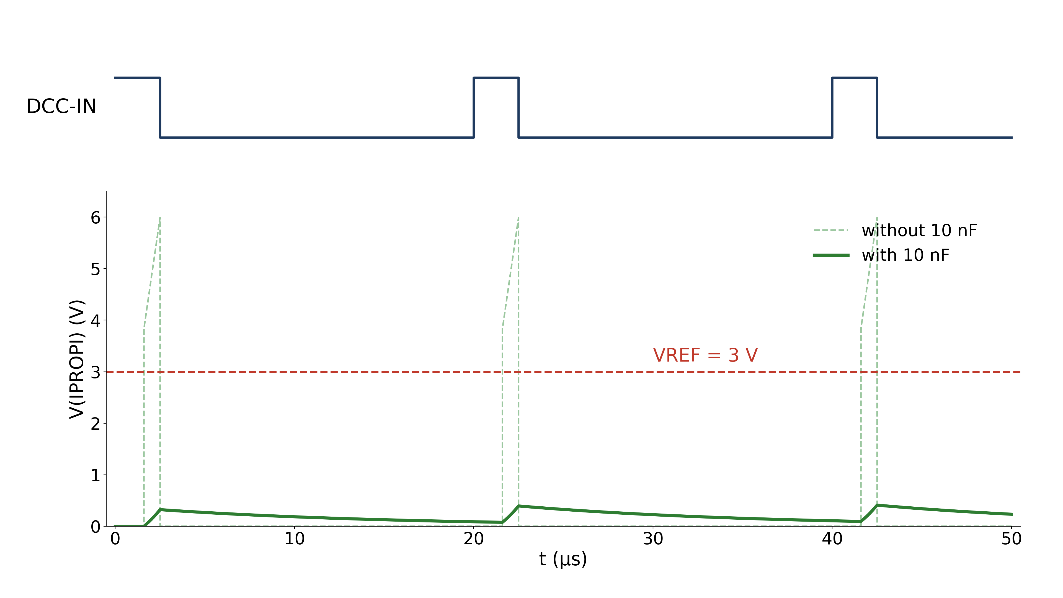
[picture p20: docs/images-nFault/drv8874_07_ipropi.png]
V(IPROPI) mit und ohne 10-nF-Kondensator


In der Praxis kann eine Kombination aus hoher Dauerlast und einem kurzen kapazitiven Einschaltstrom auftreten. Beträgt die Dauerlast zum Beispiel 2 A und wird eine neue Lokomotive mit einem 1000-µF-Kondensator auf das Gleis gesetzt, kann OCP ausgelöst werden. In diesem Fall reicht das Aktivieren des Inrush-Musters möglicherweise nicht aus, um den Kondensator zu laden und gleichzeitig weiterhin 2 A zu liefern. Dadurch verhält sich das System, als läge ein Kurzschluss auf dem Gleis vor.

## Maßnahmen bei ITRIP-Fehlern

Auch wenn nFAULT durch ITRIP ausgelöst wird, kann es eine Kombination von Ursachen geben.
Eine mögliche Ursache ist, dass Kondensatoren in Lokomotiven einen hohen Inrush-Strom verursachen, der Widerstand von Verkabelung und Gleisen diesen Strom jedoch unter den OCP-Pegel begrenzt. Wie in den ITRIP-Abbildungen oben zu sehen ist, wird das DCC-Ausgangssignal nach etwa 3 µs abgeschaltet, alle 58 oder 100 µs. Sofern keine andere nennenswerte Last auf dem Gleis liegt, kann ein 1000-µF-Kondensator nach einigen zehn ms geladen sein. In diesem Fall verschwinden die nFAULTs von selbst. Auf einer realen Anlage ist jedoch eine Kombination aus kapazitiver und ohmscher Last wahrscheinlicher, was zu ähnlichen Problemen wie oben beschrieben führt, sodass die nFAULTs möglicherweise nie verschwinden.

Bei ITRIP-Fehlern kann das Erzeugen eines speziellen Inrush-Signals von gewissem Nutzen sein. Ohne das Inrush-Muster beträgt das Tastverhältnis etwa 2 % bis 4 %, je nachdem, ob ein 1-Bit (58 µs) oder ein 0-Bit (100 µs) gesendet wird. Mit dem Inrush-Muster steigt das Tastverhältnis auf 12,5 %, sodass Kondensatoren schneller geladen werden. Sobald die nFAULTs verschwinden, sollte der Prozessor den Inrush-Modus verlassen und zum normalen DCC-Betrieb zurückkehren. Verschwinden die nFAULTs nicht, ist keine Softwarelösung möglich. Dieser Fall sollte in die Weboberfläche gemeldet werden und das DCC-Signal soll abgeschaltet werden.

Dauerhafte ITRIP-Fehler lassen sich nur durch Änderungen an der Hardware beheben. Es gibt drei Möglichkeiten:
1. VREF erhöhen. In der Praxis ist dies meist nicht möglich, weil VREF oft bereits an die maximale Spannung angepasst ist, die der ADC verarbeiten kann (auf dem LZ210-TMC-Board beträgt VREF 3 V).
2. Den Sense-Widerstand (IPROPI) verringern und dadurch den maximalen Strom erhöhen, bevor ITRIP anspricht. Die Pololu- und AliExpress-Module haben einen Sense-Widerstand von 2,49 kΩ, was bei einem VREF von 3 V zu einem ITRIP-Wert von knapp 2,7 A führt. Dieser Wert ist ziemlich niedrig, aber nachvollziehbar, da diese Module auch mit einem VREF von 5 V betrieben werden können, was 4,4 A ergibt. Überwacht die CPU ohnehin den mittleren Stromverbrauch und greift ein, wenn die mittlere Verlustleistung 2,5 bis 3 W überschreitet, ist es ratsam, den ITRIP-Wert auf etwa 6 A zu erhöhen. Bei einem VREF von 3 V kann der Sense-Widerstand durch einen 1-kΩ-Widerstand ersetzt oder ein zusätzlicher 1,8-kΩ-Widerstand parallel zum 2,49-kΩ-Sense-Widerstand auf dem Modul angebracht werden.
3. Einen Kondensator parallel zum Sense-Widerstand (IPROPI) anbringen. Das Datenblatt schlägt einen 10-nF-Kondensator vor, um Transienten zu filtern, damit die Stromregelung nicht vorzeitig anspricht. Als Nebeneffekt verzögert er ITRIP und glättet die Spannung, wodurch sich der ADC-Wert leichter auslesen lässt.

Zur Veranschaulichung zeigt die folgende Abbildung (VREF = 3 V, R_sense = 1,35 kΩ, ITRIP = 4,9 A) die Wirkung des 10-nF-Kondensators bei einem mittleren Strom von 3 A und 5 A. Wie auf der rechten Seite der Abbildung zu sehen ist (der 5-A-Fall, also Überlast), spricht ITRIP ohne den 10-nF-Kondensator bereits nach wenigen µs an, mit dem 10-nF-Kondensator dagegen deutlich später. Das Messen der Spannung über dem Sense-Widerstand mit dem ADC ist ohne Kondensator recht schwierig, mit Kondensator jedoch machbar, sofern der ADC im Free-Running-Modus läuft und die höchsten Werte erfasst.

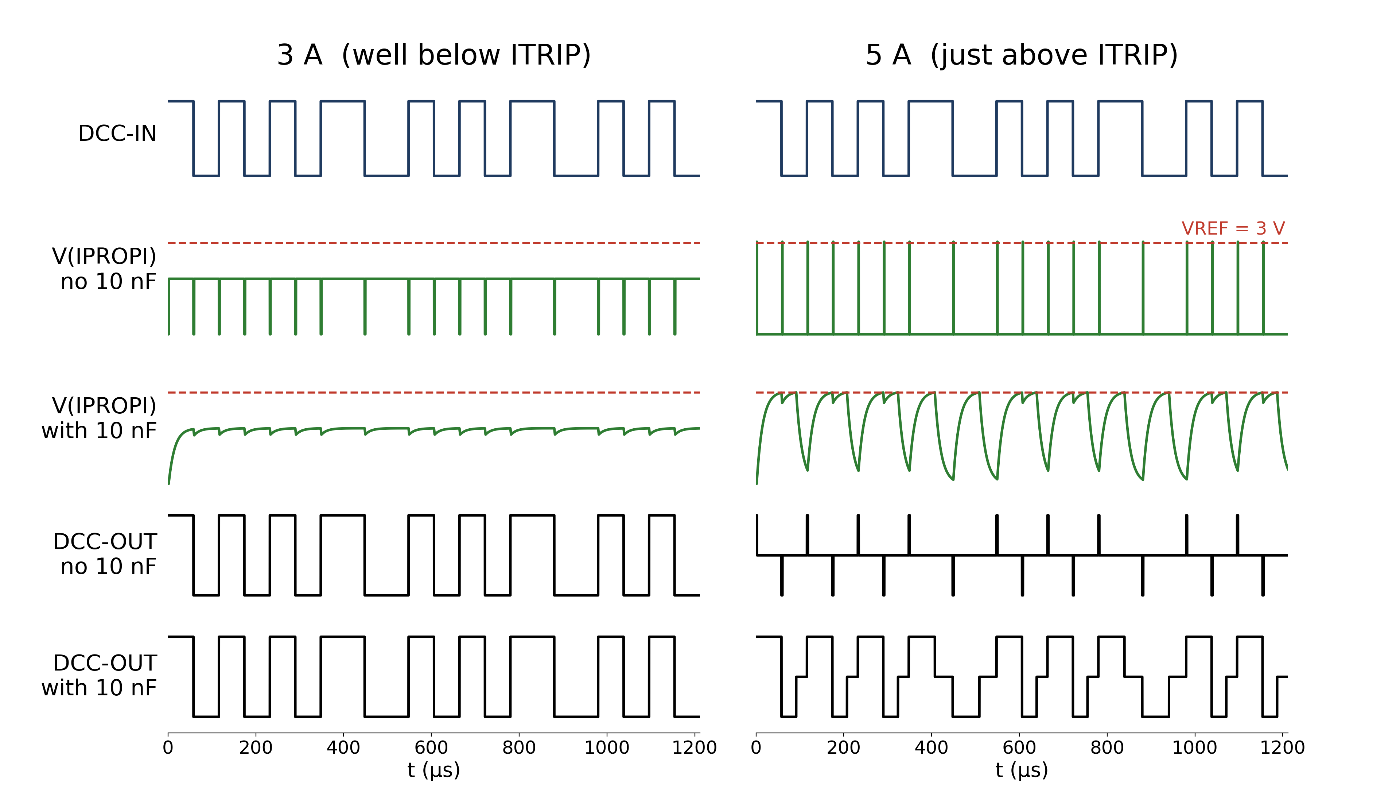
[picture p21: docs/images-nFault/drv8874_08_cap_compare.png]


## Empfehlung

Der beste Ansatz ist, ITRIP-bezogene nFAULTs so weit wie möglich zu vermeiden. Auf dem LZ210-TMC-Board lässt sich dies erreichen, indem der Sense-Widerstand (IPROPI) auf 1 kΩ gesetzt wird oder indem ein zusätzlicher 1,8-kΩ-Widerstand parallel zum 2,49-kΩ-Sense-Widerstand auf dem Modul angebracht wird. In beiden Fällen liegt der ITRIP-Wert über 6 A. Der 10-nF-Kondensator kann bestückt werden, ist aber nicht zwingend. Der ADC kann den Strom dann zuverlässig bis etwa 5 bis 6 A messen, und die Software sollte die Verlustleistung im DRV8874 abschätzen (I² × RDS(on), über die Zeit gemittelt, um die thermische Trägheit des Chips nachzubilden) und bei Bedarf das DCC-Signal abschalten, um Überhitzung zu verhindern.

Tritt ein nFAULT auf, unabhängig davon, ob er durch OCP oder ITRIP verursacht wurde, wechselt der Prozessor in einen Fehlerzustand und der ADC wird nicht mehr gelesen. Während der ersten 1,5 ms werden neue nFAULTs ignoriert, da sie durch einen Mikrokurzschluss verursacht sein können. Ab 1,5 ms überwacht der Prozessor nFAULT wieder (Hinweis: Der nFAULT-Pegel kann vom ersten nFAULT noch Low sein). Wurde der nFAULT durch OCP verursacht, wird der nächste nFAULT 500 µs nach Wiederaufnahme der Überwachung erwartet (da die Sperrzeit 2 ms beträgt); wurde der nFAULT durch ITRIP verursacht, wird der nächste nFAULT innerhalb weniger hundert µs erwartet. Tritt in den folgenden 20 ms (konfigurierbar) kein neuer nFAULT auf, war die Ursache ein Mikrokurzschluss, und der Prozessor kehrt zum Normalbetrieb zurück. Treten ein oder mehrere neue nFAULTs auf, wird der Inrush-Modus für 35 ms aktiviert (konfigurierbar bis 100 ms). Da das Inrush-Muster erst auf dem Gleis erscheint, nachdem das aktuelle DCC-Paket vollständig gesendet wurde (was etwa 13 ms dauern kann), liegt das Muster mindestens 20 ms auf dem Gleis an. Alle zusätzlichen nFAULTs, die in dieser Zeit auftreten, werden ignoriert.

Nachdem das Inrush-Muster gesendet wurde, werden wieder normale DCC-Pakete gesendet. Der Prozessor überwacht nFAULTs weitere 5 ms (konfigurierbar, aber mindestens die OCP-Sperrzeit von 2 ms). Tritt kein nFAULT auf, kehrt der Prozessor zum normalen DCC-Betrieb zurück. Treten neue nFAULTs auf, liegt wahrscheinlich ein Kurzschluss vor: Das DCC-Signal muss abgeschaltet und nach beispielsweise 1 s (konfigurierbar) erneut versucht werden.

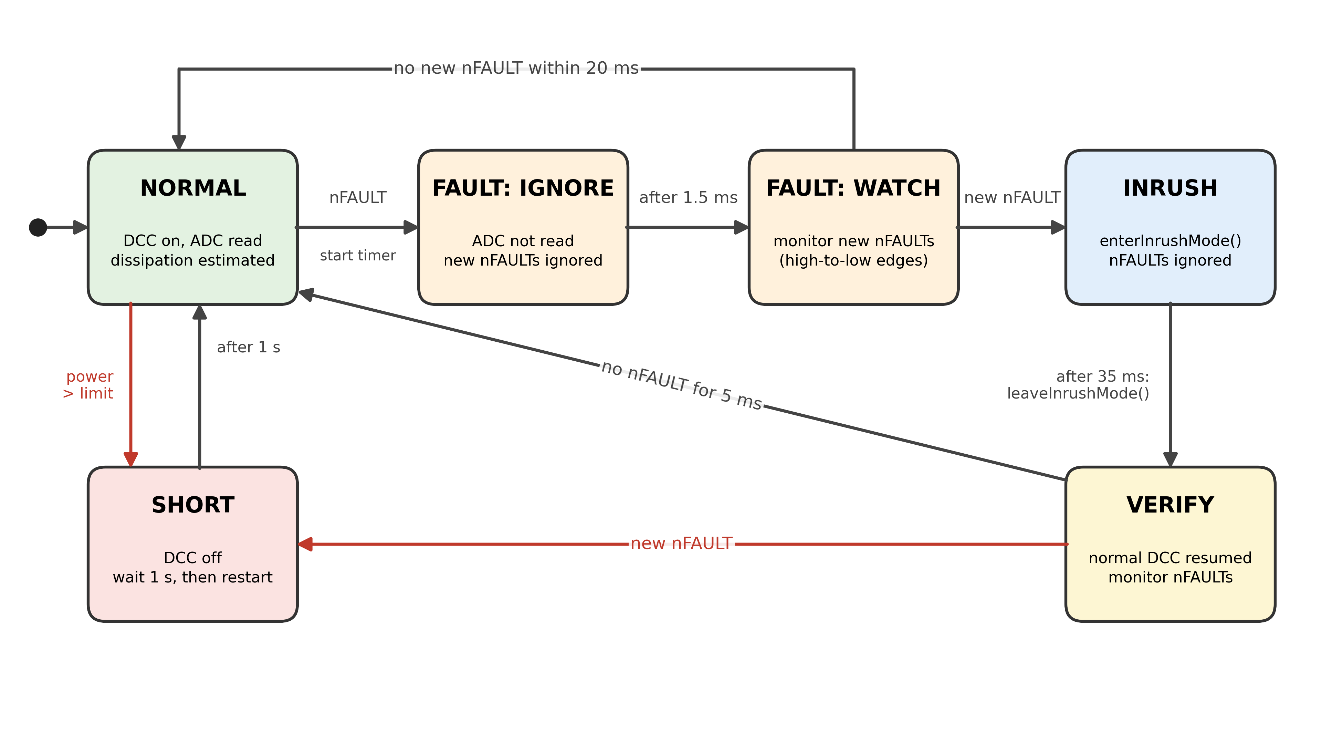
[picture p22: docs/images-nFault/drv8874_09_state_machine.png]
Zustandsdiagramm


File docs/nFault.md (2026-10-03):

[🇬🇧 English](nFault.md) | [🇩🇪 Deutsch](nFault.de.md) | [🇳🇱 Nederlands](nFault.nl.md)

# Dealing with nFAULTs

The DRV8874, like other modern integrated H-bridge drivers, is designed for (inductive) motor applications and can be problematic when used in (capacitive) DCC model train applications. The main problems stem from the built-in current protection mechanisms, which react within a few microseconds and are thus too fast for model trains.

There are two forms of current protection: OCP and ITRIP.

## OCP
OCP is the built-in Overcurrent Protection mechanism, which reacts if the output current exceeds 6 (minimum) to 10 (typical) amperes for a period of 3 µs or longer. If the DRV8874 is configured in Quad-Level 2 (= Automatic Retry; the case for the LZ210-TMC), OCP pulls down nFAULT and disables the DCC output signal for a period of 2 ms. After 2 ms the DCC reappears, as shown in the figure below.

OCP fault

If the cause of the OCP fault remains, nFAULT is asserted again when the output power is restored after 2 ms, as shown in the figure below.

Repeating OCP fault

## ITRIP
ITRIP is the built-in current regulation mechanism. It compares the voltage across the sense (IPROPI) resistor with VREF. If the output current exceeds ITRIP for longer than a few microseconds, the DCC output signal is switched off. In Quad-Level 2 (= Cycle-By-Cycle) the DRV8874 pulls down nFAULT, until the next transition of the input signal. At that transition nFAULT is released and the output follows the input again, as shown in the figure below.

ITRIP fault

Unlike OCP, ITRIP does not switch the output off for a fixed time, but for the remainder of the current half-bit: at most 58 µs for a 1-bit and 100 µs for a 0-bit. Nevertheless, also in this case the DCC output signal is corrupted.

If the cause of the ITRIP fault remains, nFAULT is asserted again when the output power is restored after each transition of the input signal, thus every 58 or 100 µs. This is shown in the figure below.

Repeating ITRIP fault

## Why overcurrent?
On a DCC model railway layout, there are several possible causes of an overcurrent condition:
1. The load requires more current than the DRV8874 can deliver. This may be caused by the locomotives and coaches drawing too much current. A possible remedy is to lower the value of the sense (IPROPI) resistor, thereby increasing the ITRIP threshold.
2. The track power has just been switched on. Capacitors in locomotives and coaches can initially draw a high inrush current while they are being charged. This may temporarily trigger the current protection. Once the capacitors are charged, the current normally drops to its normal level.
3. There is a short circuit on the track. In this case, the overcurrent condition remains until the short circuit is removed. It is important to distinguish between permanent short circuits, such as a derailed locomotive, and temporary micro-short circuits, such as brief contact of wheel flanges at the frog of a turnout.

Depending on the cause, different remedies are possible. In case 1, the hardware can be adapted, for example by increasing the ITRIP threshold. In case 2, software measures such as a special inrush signal during power-up may help. In case 3, micro short circuits will automatically disappear, but a real short circuit must always be detected and removed. In practice the DRV8874 may often encounter a combination of condition 1 (high average load) and condition 2 (short inrush load), which makes it more difficult to resolve the problem.

## Distinguishing between OCP and ITRIP faults

Before deciding on possible measures, it is important to determine whether the fault is caused by OCP or ITRIP. This can be determined by measuring the interval between successive nFAULT events: when the processor detects the first nFAULT event, it starts a timer and enters a special state.
1. Several new nFAULT events occur within the next 2 ms. **The fault was triggered by ITRIP**. The exact number of events can be reported via the web interface.
2. The next nFAULT event occurs after roughly 2 ms. **The fault was triggered by OCP**. The software should presumably use a range between 1.5 and 3 ms to account for timing variations.
3. No new nFAULT event occurs within the next few milliseconds. The problem may have been caused by micro-short circuits. No specific actions are needed and statistics on these events can be reported via the web interface.

## Measures for OCP faults

In case of an OCP fault, it is important to distinguish between an inrush problem and a short circuit on the track. A possible approach is to send a special inrush signal consisting of a short 2.5 µs ON pulse, which is shorter than the 3 µs required to trigger OCP, followed by 17.5 µs OFF. This allows capacitors to charge while preventing OCP from triggering another nFAULT after 2 ms.  

This is shown in the figure below. After the processor detects the first nFAULT, it starts a timer. If the processor detects a second nFAULT event after roughly 2 ms, it enters inrush mode.  

Inrush pattern

As can be seen from the figure above, the inrush pattern does not appear immediately, but only after the current DCC packet is complete. Since the length of a DCC packet may be anything between (roughly) 6 and 13 ms, it is possible to still see multiple nFAULTs before the inrush pattern appears on the output.

Inrush pattern

Once the inrush pattern appears, the capacitors are charged. For a 1000 µF capacitor, the required charging time may be 10 to 20 ms. The inrush pattern should therefore be present on the track for at least 20 ms before it has any effect, after which normal DCC operation is resumed. If nFAULTs appear again after that, there is likely a short circuit and the DCC signal is switched off (see the Recommendation below).

However, it is important that the inrush pattern does not take too long. In fact the pulses are shorter than the OCP deglitch time, so OCP never trips, which runs the risk of overheating the DRV8874. Since pulses are very short, the heat may not spread quickly enough to trigger the internal thermal shutdown (TSD) protection, and thereby destroying the chip.

Therefore the software could monitor the voltage over the sense (IPROPI) resistor, to check if the current remains high, or slowly decreases. If it remains high, there is likely a short circuit on the track and the processor should remove the output signal. If the current decreases, the OCP is likely triggered by capacitor inrush current, and the processor may stay in the inrush mode for a longer period.

Measuring the voltage across the sense resistor is not trivial. The pulses are very short, and the shape of the signal at the ADC input depends on whether the 10 nF capacitor suggested in the DRV8874 datasheet is fitted. The figure below illustrates this for 10 A current peaks (idealized: the internal IPROPI clamp limits the real voltage). Without the capacitor the peaks are high but last less than 1 µs. The ADC can only catch them in free-running mode, and not every pulse will be caught: with 20 samples at 500 kS/s (40 µs) the processor should select the highest measured value. With the capacitor the maximum voltage is only about 0.4 V, decaying with a time constant of about 13 µs.

V(IPROPI) with and without the 10 nF capacitor

In practice there may be a combination of high permanent load and a short capacitive inrush. If, for example, the permanent load is 2 A and a new locomotive with a 1000 µF capacitor is placed on the tracks, the OCP may get triggered. In that case activating the inrush pattern may not be sufficient to charge the capacitor, and still deliver 2 A. As a result, the system behaves as if there is a short circuit on the track.

## Measures for ITRIP faults

Also if nFAULT is triggered by ITRIP, there may be a combination of causes.
One possible cause is that capacitors within locomotives are responsible for a high inrush current, but the resistance of wires and tracks limit that current below the OCP level. As can be seen in the ITRIP figures above, the DCC output will be disabled after roughly 3 µs every 58 or 100 µs. Provided that no other significant load exists on the tracks, a 1000 µF capacitor may get loaded after some tens of ms. In that case the nFAULTs will automatically disappear. However, on a real layout, a combination of capacitive and resistive load is more likely, which results in similar problems as discussed above, meaning that the nFAULTs may never disappear.

In case of ITRIP faults the generation of a dedicated inrush signal may be of some use. Without the inrush pattern, the duty cycle is around 2% to 4%, depending on whether a 1-bit (58 µs) or a 0-bit (100 µs) is being sent. With inrush pattern, the duty cycle increases to 12.5%, thus capacitors will be charged faster. As soon as the nFAULTs disappear, the processor should leave the inrush mode, and switch back to normal DCC mode. If the nFAULTs do not disappear, no software solution is possible. This case should be written to the web interface, and the DCC signal should be removed.

Permanent ITRIP faults can only be resolved by modifying the hardware. Three options exist:
1. Increase VREF. In practice this is usually not possible, because VREF is often already matched to the maximum voltage the ADC can handle (on the LZ210-TMC board VREF is 3 V).
2. Lower the sense (IPROPI) resistor, and thereby increase the maximum current before ITRIP triggers. The Pololu and AliExpress modules have a sense resistor of 2.49 kΩ, which for a VREF of 3 V results in an ITRIP value of nearly 2.7 A. This value is fairly low, but understandable, since these modules can also be used with a VREF of 5 V, which gives 4.4 A. If the CPU already monitors the average current consumption and intervenes when the average dissipation exceeds 2.5 to 3 W, it is advisable to increase the ITRIP value to around 6 A. With a VREF of 3 V, the sense resistor can be replaced by a 1 kΩ resistor, or an additional 1.8 kΩ resistor can be placed in parallel to the 2.49 kΩ sense resistor on the module.
3. Put a capacitor over the sense (IPROPI) resistor. The datasheet proposes a 10 nF capacitor, to filter transients so that the current regulation does not trigger prematurely. As a side effect it delays ITRIP and smooths the voltage, which makes the ADC reading easier.

To illustrate this, the figure below shows (VREF = 3 V, Rsense = 1.35 kΩ, ITRIP = 4.9 A) the effect of the 10 nF capacitor for a 3 A and 5 A average current. As can be seen at the right side of the figure (the 5 A case, thus overload), without the 10 nF capacitor ITRIP triggers already after a few µs, whereas with 10 nF capacitor ITRIP triggers much later. Using the ADC to measure the voltage over the sense resistor without capacitor will be quite difficult, but with capacitor doable, provided the ADC runs in free-running mode, and catch the highest values.

V(IPROPI) with and without the 10 nF capacitor

## Recommendation

The best approach is to prevent ITRIP-related nFAULTs as much as possible. On the LZ210-TMC board this can be done by setting the sense (IPROPI) resistor to 1 kΩ, or by placing an additional 1.8 kΩ resistor in parallel to the 2.49 kΩ sense resistor on the module. In both cases the ITRIP value is above 6 A. The 10 nF capacitor may be fitted, but is not essential. The ADC can then measure the current reliably up to roughly 5 to 6 A, and the software should estimate the dissipation in the DRV8874 (I² × RDS(on), averaged over time to model the thermal inertia of the chip) and, if needed, switch off the DCC signal to prevent overheating.

If an nFAULT occurs, regardless of whether it is caused by OCP or ITRIP, the processor enters a fault state and the ADC is no longer read. During the first 1.5 ms new nFAULTs are ignored, since they may be caused by a micro short circuit. From 1.5 ms onwards the processor monitors nFAULT again (note that the nFAULT level may still be low from the first nFAULT). In case the nFAULT was caused by OCP, the next nFAULT is expected 500 µs after nFAULT monitoring is resumed (since the retry time is 2 ms); in case the nFAULT was caused by ITRIP, the next nFAULT is expected within a few hundred µs. If no new nFAULT occurs during the following 20 ms (configurable), the cause was a micro short circuit, and the processor returns to normal operation. If one or more new nFAULTs occur, inrush mode is enabled for 35 ms (configurable up to 100 ms). Since the inrush pattern only appears on the tracks after the current DCC packet has been completed (which can take roughly 13 ms), the pattern remains present on the tracks for at least 20 ms. Any additional nFAULTs occurring during this period are ignored.

After the inrush pattern is sent, the sending of normal DCC packets is resumed. The processor keeps monitoring nFAULTs for 5 ms (configurable, but at least the OCP retry interval of 2 ms). If no nFAULT occurs, the processor returns to normal DCC operation. If new nFAULTs occur, there is likely a short circuit: the DCC signal must be switched off and retried after, for example, 1 s (configurable).

State machine

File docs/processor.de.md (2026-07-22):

[🇬🇧 English](processor.md) | [🇩🇪 Deutsch](processor.de.md) | [🇳🇱 Nederlands](processor.nl.md)

# Prozessorauswahl

Modulares Design ist ein wichtiges Kriterium für den Bau unserer TMC-DCC-Zentrale.
 Die [Z21PG](https://pgahtow.de/w/Zentrale_Z21PG/de)-Zentrale von Philipp Gahtow war dabei für uns ein leuchtendes Beispiel. Diese Zentrale ist modular aufgebaut und unterstützt mehrere Prozessoren, wie beispielsweise den ATMega2560, den ATMega328 und den ESP32.

Der ATMega2560 scheint dabei mit Abstand die beste Unterstützung zu haben und am häufigsten eingesetzt zu werden.
Da der ATMega2560 jedoch ein relativ teurer und alter 8-Bit-Prozessor ist, hatten wir den Wunsch, ihn durch einen moderneren und billigeren Prozessor zu ersetzen.

Bei der Z21PG-Zentrale werden die verschiedenen Prozessoren über „Bit-Banging“ von der DCCInterfaceMaster-Bibliothek (https://github.com/Digital-MoBa/DCCInterfaceMaster) angesteuert. Dabei werden die Ausgangspins des Prozessors über sogenannte Interrupt-Service-Routinen (ISRs) gesetzt.

Obwohl diese Methode den Vorteil hat, dass nur wenig prozessorspezifischer Code benötigt wird, ist unsere Erfahrung dennoch, dass obengenannte Bibliothek aufgrund der großen Anzahl von #ifdef-Konstruktionen relativ schwer zu verstehen und daher schwer anzupassen ist. Daher haben wir zunächst den „Bit-Banging“-Code dieser Bibliothek neu strukturiert und überarbeitet und den ATMega- sowie den ESP32-Code entsprechend angepasst.
Anschließend haben wir den Code für eine Reihe neuer Prozessoren erweitert, darunter den STM32, den RP2040 und den DxCore.

Ein Nachteil des „Bit-Banging“ ist, dass es im DCC-Signal zu einem Jitter von mehreren Mikrosekunden kommen kann. Nachdem wir den „Bit-Banging“-Code der ursprünglichen Bibliothek überarbeitet hatten, wagten wir uns an ein weiteres Experiment: Wie einfach bzw. schwierig würde es sein, den Code von Grund auf komplett neu zu schreiben, diesmal unter Nutzung der modernen Peripheriegeräte, die die aktuelle Prozessorgeneration mit sich bringt. In diesem Schritt haben wir die Zustandsmaschine, die den Kern des „Bit-Banging“-Codes bildet, durch einen Ansatz ersetzt, bei dem das gesamte DCC-Paket im Voraus berechnet wird, einschließlich des exakten Timings aller Bits. Wir haben Implementierungen für DxCore-, STM32-, ESP32- und RP2040/2350-Prozessoren erstellt. Im Laufe dieses Experiments haben wir einige Erfahrungen gesammelt, bei denen wir (für uns) überraschende Ergebnisse feststellen konnten. Diese Erkenntnisse werden im Folgenden beschrieben. Wir beginnen mit dem Prozessor, den wir für die Erzeugung von DCC weniger geeignet halten, und schließen mit dem Prozessor ab, der uns am besten gefallen hat

## ESP32
Wir sind etwas enttäuscht vom ESP32. Auf dem Papier ist der sogenannte RMT-Timer ideal für die Erzeugung von DCC-Signalen und wird daher auch in Projekten wie DCC-EX und OpenRemise verwendet. Innerhalb eines DCC-Pakets liefert der RMT ein hervorragendes DCC-Signal, und es tritt kein Jitter auf. Das Problem tritt jedoch zwischen den DCC-Paketen auf. Durch die Kombination aus FreeRTOS, der relativ ressourcenintensiven ESP-IDF-Hardware-Abstraktionsschicht (HAL) und den (was DCC betrifft) unzureichenden IDF v5-RMT-Treibern (also der aktuellen Version) entsteht jedes Mal eine erhebliche Verzögerung bei einer Neukonfiguration des RMT für das nächste Paket. Diese Verzögerung beträgt in der Regel etwa 20 bis 30 Mikrosekunden und ist zudem nicht konstant. Messungen zeigen, dass der Jitter im Durchschnitt etwa 2 Mikrosekunden beträgt, jedoch bis zu 7 Mikrosekunden oder mehr ansteigen kann, wobei in einigen Internetforen sogar Spitzenwerte von über 10 Mikrosekunden gemeldet werden, insbesondere bei WLAN-Aktivität.
Da dieser Jitter sowohl zwischen DCC-Paketen als auch beim RailCom-Cutout auftritt, entspricht das Signal nicht immer den DCC-Spezifikationen.

Daher ist der ESP32 unserer Meinung nach am wenigsten geeignet, um DCC-Signale zu erzeugen.

## DxCore
Die DxCore-Familie bietet eine deutlich bessere performance, wie beispielsweise der AVR64DA48, der als moderner Nachfolger der klassischen Arduino-Prozessoren (ATMega 328, 2560) angesehen werden kann.

Wir verwenden dabei TCA0 für das DCC-Signal und TCD0 (das meist ungenutzt bleibt) für den RailCom-Cutout. Da diese Prozessoren kein DMA unterstützen, wird nach jedem DCC-Bit (116/200 µs) ein Interrupt ausgelöst, in dem die Timer-Register für das nächste Bit gesetzt werden. In der Praxis ergibt dies ein äußerst stabiles DCC-Signal ohne Jitter zwischen den Paketen. Der RailCom-Cutout-Timer TCD0 wird in der ISR zu Beginn jedes Pakets erneut gestartet, wodurch es – abhängig von anderen Interrupts – zu einem gewissen Jitter im Cutout kommen kann.
Versuche, den Cutout-Timer vollständig hardwaremäßig an den DCC-Timer zu koppeln (beispielsweise über das Ereignissystem), waren bei uns nicht von Erfolg gekrönt. Dennoch ist das DCC-Signal selbst jitterfrei, auch wenn dies aufgrund der vielen Interrupts mit einer relativ hohen CPU-Auslastung einhergeht.

## STM32
Die STM32-Serie besteht aus modernen 32-Bit-Mikrocontrollern und umfasst eine große Vielfalt an Varianten. Es gibt verschiedene Familien, wie die C-, F-, G- und H-Familien, und innerhalb jeder Familie gibt es wiederum eine Reihe von Varianten (wie die F1 und F4). Obwohl alle STM32-M Prozessoren eine gemeinsame Basis haben, unterscheiden sich die Varianten erheblich voneinander, beispielsweise hinsichtlich der DMA-Architektur, des Caching, der Speicherstruktur und der verfügbaren Peripheriegeräte. In der Praxis bedeutet dies, dass (Arduino-)Code nicht ohne Weiteres zwischen verschiedenen STM32-Varianten austauschbar ist und dass oft Anpassungen für die jeweilige Variante erforderlich sind. Wir haben Implementierungen für die F4- und H7-Serien erstellt, ohne FreeRTOS zu verwenden.

Wir haben Timer 3 und DMA zur Erzeugung des DCC-Signals und Timer 4 für den RailCom-Cutout verwendet.
Das gesamte DCC-Paket wird vorab in einen DMA-Puffer geladen, sodass die Signalgenerierung vollständig über die Hardware erfolgt. Lediglich am Ende jedes DCC-Pakets ist ein Interrupt erforderlich, um den DMA-Kanal neu zu konfigurieren, ergänzt durch Timer-4-Interrupts am Anfang und am Ende des Cutouts. Da pro Paket Dutzende Mikrosekunden für diese Neukonfiguration zur Verfügung stehen, tritt in der Praxis kein Jitter zwischen aufeinanderfolgenden DCC-Paketen auf. Für die RailCom-Cutout-Funktion ist theoretisch ein gewisses Maß an Jitter möglich, doch in der Praxis erwies sich dies als nicht messbar, auch weil die Interrupt-Priorität einstellbar ist und optimiert werden kann.

Das Ergebnis ist ein sehr stabiles und sauberes DCC-Signal bei geringer CPU-Auslastung, da pro Paket nur eine begrenzte Anzahl (3) von Interrupts erforderlich ist.

## RP2040/RP2350
Die größte Überraschung für uns waren der RP2040 und der RP2350, die vom Raspberry Pi Pico bekannt sind.
Original-Raspberry-Pi-Pico-Boards kosten etwa 5 Euro, und kleine Boards sind bereits ab etwa 1,5 Euro erhältlich.
Die RP-Familie besteht aus nur zwei Varianten, die softwaretechnisch weitgehend kompatibel sind und über eine interessante Peripherie verfügen: den PIO (Programmable IO). Dabei handelt es sich im Grunde um einen kleinen, spezialisierten Coprozessor, mit dem sehr präzise getaktete Ausgangssignale erzeugt werden können. In Kombination mit DMA kann das gesamte DCC-Signal, einschließlich RailCom-Cutout, vollständig von einem einzigen PIO (in dem zwei sehr einfache Zustandsmaschinen verwendet werden) erzeugt werden. Unsere RP-Implementierung liefert ein absolut stabiles DCC-Signal ohne jeglichen Jitter zwischen den Paketen oder beim Cutout. Zudem ist die Implementierung relativ einfach und die CPU-Auslastung minimal: nur ein Interrupt pro Paket. Mit einer Taktrate von 125 bis 200 MHz und einer Dual-Core-Architektur bietet der RP2040 zudem sehr viel Rechenleistung.

Für die Erzeugung von DCC-Signalen ist der RP2040 unserer Meinung nach daher der am besten geeignete Prozessor. Ein Nachteil ist jedoch die relativ mäßige Qualität des ADC, was diesen Prozessor beispielsweise für Belegtmelder weniger geeignet macht.

## Fazit
Während der ESP32 aufgrund seiner nicht optimierten RMT-Treiberimplementierung und Jitter-Problemen enttäuscht, erzeugen sowohl DxCore als auch STM32 ein gutes DCC-Signal, wenn auch mit unterschiedlichen Kompromissen.

Der RP2040/2350 sticht jedoch hervor: mit der besten DCC-Signalqualität, der geringsten CPU-Auslastung, niedrigen Kosten und einer relativ einfachen Implementierung. Deshalb haben wir uns in unserer Zentrale für den RP2040/2350 entschieden.

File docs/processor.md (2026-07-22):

[🇬🇧 English](processor.md) | [🇩🇪 Deutsch](processor.de.md) | [🇳🇱 Nederlands](processor.nl.md)

# Choosing a processor

Modular design is a key criterion for the construction of our TMC DCC command station. Philipp Gahtow’s [Z21PG](https://pgahtow.de/w/Zentrale_Z21PG/de) command station served as a shining example for us in this regard. This command station has a modular design and is compatible with several processors, such as the ATMega2560, ATMega328 and ESP32. The ATMega2560 appears to have by far the best support and is the most widely used.
However, as the ATMega2560 is a relatively expensive and outdated 8-bit processor, we wanted to replace it with a more modern and cheaper processor.

In the Z21PG command station, the various processors are controlled via “bit-banging” by the DCCInterfaceMaster library (https://github.com/Digital-MoBa/DCCInterfaceMaster). In this method, the processor’s output pins are set from so-called Interrupt Service Routines (ISRs).
 Although this method has the advantage of requiring little processor-specific code, our experience is that the library is relatively difficult to understand due to the large number of #ifdef constructs, and is therefore difficult to adapt. We therefore initially restructured and rewrote the “bit-banging” code from this library, and adapted the ATMega and ESP32 code accordingly. We then extended the code to support a number of new processors, such as the STM32, RP2040 and DxCore.

A disadvantage of “bit-banging” is that jitter of several microseconds can occur in the DCC signal. After rewriting the “bit-banging” code from the original library, we decided to try the following experiment: how easy or difficult would it be to completely rewrite the code from scratch, this time utilising the modern peripherals offered by the current generation of processors? In this step, we replaced the state machine that forms the core of the “bit-banging” code with an approach in which the entire DCC packet is calculated in advance, including the exact timing of all bits. We created implementations for DxCore, STM32, ESP32 and RP2040/2350 processors. During this experiment, we gained some insights that yielded results which were surprising to us. These insights are described below. We’ll start with the processor we consider least suitable for generating DCC, and conclude with the one we were most impressed by

## ESP32
We are somewhat disappointed with the ESP32. On paper, the so-called RMT timer is ideal for generating DCC signals and is therefore also used in projects such as DCC-EX and OpenRemise. Within a DCC packet, the RMT delivers an excellent DCC signal and there is no jitter.
 However, the problem arises between DCC packets. The combination of FreeRTOS, the relatively resource-intensive ESP-IDF hardware abstraction layer (HAL) and the (as far as DCC is concerned) inadequate IDF v5 RMT drivers (i.e. the current version) results in a significant delay when reconfiguring the RMT for the next packet. This delay is typically around 20 to 30 microseconds and is, moreover, not constant. Measurements show that the jitter averages around 2 microseconds but can rise to 7 microseconds or more; indeed, some online forums even report peak values of over 10 microseconds, particularly during Wi-Fi activity.
As this jitter occurs both between DCC packets and at the RailCom cut-out, the signal does not always comply with the DCC specifications. For this reason, we consider the ESP32 to be the least suitable for generating DCC signals.

## DxCore
The DxCore family performs considerably better; for example, the AVR64DA48, which can be regarded as the modern successor to the classic Arduino processors (ATMega 328, 2560). Here, we use TCA0 for the DCC signal and TCD0 (which usually remains unused) for the RailCom cut-out. As these processors do not support DMA, an interrupt is triggered after every DCC bit (116/200 µs), during which the timer registers are set for the next bit. In practice, this results in an extremely stable DCC signal with no jitter between packets. The RailCom cut-out timer is triggered in the ISR at the start of each packet, which means that, depending on other interrupts, some jitter may occur in the cut-out. Attempts to link the cutout timer entirely via hardware to the DCC timer (for example, via the event system) have not been successful in our tests. Nevertheless, the DCC signal itself is jitter-free, even though this is accompanied by a relatively high CPU load due to the numerous interrupts.

## STM32
The STM32 series consists of modern 32-bit microcontrollers and comprises a wide variety of variants. There are several families, such as the C, F, G and H families, and within each family there are a number of variants (such as the F1 and F4). Although all STM32s share a common basis, the variants differ considerably from one another, for example in terms of DMA architecture, caching, memory structure and available peripherals. In practice, this means that (Arduino) code is not simply interchangeable between different STM32 variants and that adaptations are often required for each variant. We have created implementations for the F4 and H7 series, in which we did not use FreeRTOS.
We used Timer 3 and DMA to generate the DCC signal and Timer 4 for the RailCom cut-out. The entire DCC packet is loaded into a DMA buffer in advance, so that signal generation is handled entirely by the hardware. An interrupt is required only at the end of each DCC packet to reconfigure the DMA channel, supplemented by Timer 4 interrupts at the start and end of the cutout.
As tens of microseconds are available per packet for this reconfiguration, there is effectively no jitter between consecutive DCC packets. For the RailCom cut-out function, a certain degree of jitter is theoretically possible, but in practice this proved to be not measurable, also because the interrupt priority is adjustable and can be optimised.
The result is a very stable and clean DCC signal with low CPU load, as only a limited number (3) of interrupts are required per packet.

## RP2040/RP2350
The biggest surprise for us were the RP2040 and the RP2350, known from the Raspberry Pi Pico.
Original Raspberry Pi Pico boards cost around 5 euros, and small boards are available from around 1.5 euros. The RP family consists of just two variants, which are largely software-compatible and feature an interesting peripheral: the PIO (Programmable IO). This is essentially a small, specialised coprocessor capable of generating very precisely clocked output signals. In combination with DMA, the entire DCC signal, including the RailCom cut-out, can be generated entirely by a single PIO (using two very simple state machines). Our RP implementation delivers an absolutely stable DCC signal without any jitter between packets or at the cut-out. Furthermore, the implementation is relatively straightforward and the CPU load is minimal: just one interrupt per packet. With a clock speed of 125 to 200 MHz and a dual-core architecture, the RP2040 also offers a great deal of processing power. In our opinion, the RP2040 is therefore the most suitable processor for generating DCC signals.
One drawback, however, is the relatively average quality of the ADC, which makes this processor less suitable for occupancy sensors, for example.

## Conclusion
Whilst the ESP32 disappoints due to its non-optimised RMT driver implementation and jitter issues, both DxCore and STM32 generate a good DCC signal, albeit with different trade-offs. The RP2040/2350, however, stands out: it offers the best DCC signal quality, the lowest CPU load, low cost and a relatively simple implementation. That is why we have opted for the RP2040/2350 in our command station.

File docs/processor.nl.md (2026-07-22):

[🇬🇧 English](processor.md) | [🇩🇪 Deutsch](processor.de.md) | [🇳🇱 Nederlands](processor.nl.md)

# Processor keuze

Modulair ontwerp is een belangrijk criterium voor de bouw van onze TMC DCC centrale. De [Z21PG](https://pgahtow.de/w/Zentrale_Z21PG/de) centrale van Philipp Gahtow was daarbij voor ons een lichtend voorbeeld. Deze centrale is modulair opgebouwd en kan met meerdere processoren overweg, zoals de ATMega2560, ATMega328 en ESP32. De ATMega2560 lijkt hierbij veruit de beste ondersteuning te hebben en het meest te worden toegepast.
Omdat de ATMega2560 echter een relatief dure en oude 8-bits processor is, bestond bij ons de wens die te vervangen door een modernere en goedkopere processor.

Bij de Z21PG centrale worden de verschillende processoren via “bit-banging” door de DCCInterfaceMaster-bibliotheek (https://github.com/Digital-MoBa/DCCInterfaceMaster) aangestuurd. Daarbij worden uitgangspinnen van de processor gezet vanuit zogeheten Interrupt Service Routines (ISRs). Alhoewel deze methode als voordeel heeft dat er weinig processor specifieke code nodig is, is onze ervaring toch dat deze bibliotheek door het grote aantal #ifdef constructies relatief lastig te begrijpen is en daardoor moeilijk aan te passen. In eerste instantie hebben we daarom de “bit-banging” code van deze library geherstructureerd en herschreven, en de ATMega en ESP32-code hierop aangepast. Vervolgens hebben we de code uitgebreid voor een aantal nieuwe processoren, zoals de STM32, RP2040 en DxCore.

Een nadeel van “bit-banging” is dat er jitter van meerdere microsecondes in het DCC signaal kan ontstaan. Nadat we de “bit-banging” code van de oorspronkelijke library hadden herschreven, durfden we het aan een volgende experiment te doen: hoe makkelijk / moeilijk zou het zijn om de code vanaf de basis compleet opnieuw te schrijven, dit keer met gebruikmaking van de moderne peripherals die de huidige generatie processors meebrengen. In deze stap hebben we de toestandsmachine die de kern van de “bit-banging”-code vormt, vervangen door een aanpak waarbij het volledige DCC-pakket vooraf wordt berekend, inclusief de exacte timing van alle bits. We hebben implementaties gemaakt voor DxCore-, STM32-, ESP32- en RP2040/2350-processors. Tijdens dit experiment hebben we wat ervaringen opgedaan waarbij we (voor ons) verrassende resultaten zagen. Deze ervaringen is hieronder beschreven. We beginnen met de processor die we het minst geschikt vinden voor het genereren van DCC, en sluiten af met de processor die ons het beste beviel

## ESP32
We zijn enigszins teleurgesteld over de ESP32. Op papier is de zogenaamde RMT-timer ideaal voor het genereren van DCC-signalen en wordt daarom ook gebruikt in projecten als DCC-EX en OpenRemise. Binnen een DCC-pakket levert de RMT een uitstekend DCC-signaal en treedt er geen jitter op. Het probleem ontstaat echter tussen de DCC-pakketten. Door de combinatie van FreeRTOS, de relatief resource-intensieve ESP-IDF-hardware-abstractielaag (HAL) en de (wat DCC betreft) ontoereikende IDF v5-RMT-drivers (dus de huidige versie) ontstaat er een aanzienlijke vertraging bij het opnieuw configureren van de RMT voor een volgend pakket. Deze vertraging bedraagt doorgaans ongeveer 20 tot 30 microseconden en is bovendien niet constant. Metingen tonen aan dat de jitter gemiddeld ongeveer 2 microseconden bedraagt, maar kan oplopen tot 7 microseconden of meer, waarbij in sommige internetfora zelfs piekwaarden van meer dan 10 microseconden worden gemeld, met name bij wifi-activiteit.
Omdat deze jitter zowel tussen DCC-pakketten als bij de RailCom-cutout optreedt, voldoet het signaal niet altijd aan de DCC-specificaties. Daarom is de ESP32 naar onze mening het minst geschikt voor het genereren van DCC-signalen.

## DxCore
De DxCore-familie presteert aanzienlijk beter, zoals bijvoorbeeld de AVR64DA48, die kan worden beschouwd als de moderne opvolger van de klassieke Arduino-processoren (ATMega 328, 2560). Hier gebruiken we TCA0 voor het DCC-signaal en TCD0 (dat meestal ongebruikt blijft) voor de RailCom-cutout. Omdat deze processors geen DMA ondersteunen, wordt na elke DCC-bit (116/200 µs) een interrupt geactiveerd, waarin de timerregisters voor de volgende bit worden ingesteld. In de praktijk levert dit een uiterst stabiel DCC-signaal op zonder jitter tussen de pakketten. De RailCom-Cutout-timer wordt in de ISR aan het begin van elk pakket geactiveerd, waardoor er, afhankelijk van andere interrupts, enige jitter in de cutout kan optreden. Pogingen om de cutout-timer volledig hardwarematig aan de DCC-timer te koppelen (bijvoorbeeld via het eventsysteem) waren niet succesvol. Toch is het DCC-signaal zelf jittervrij, ook al gaat dit vanwege de vele interrupts gepaard met een relatief hoge CPU-belasting.

## STM32
De STM32-serie bestaat uit moderne 32-bits microcontrollers en kent een grote verscheidenheid aan varianten. Er zijn verschillende families, zoals de C-, F-, G- en H-families, en binnen elke familie zijn er weer een aantal varianten (zoals de F1 en F4). Hoewel alle STM32’s een gemeenschappelijke basis delen, verschillen de varianten onderling aanzienlijk, bijvoorbeeld wat betreft DMA-architectuur, caching, geheugenstructuur en beschikbare randapparatuur. In de praktijk betekent dit dat (Arduino-)code niet zomaar tussen verschillende STM32-varianten uitwisselbaar is en dat aanpassingen per variant vaak nodig zijn. We hebben implementaties gemaakt voor de F4- en H7-series, waarbij we geen FreeRTOS hebben gebruikt.
We hebben Timer 3 en DMA gebruikt voor het genereren van het DCC-signaal en Timer 4 voor de RailCom-Cutout. Het volledige DCC-pakket wordt vooraf in een DMA-buffer geladen, zodat de signaalgeneratie volledig via de hardware verloopt. Alleen aan het einde van elk DCC-pakket is een interrupt nodig om het DMA-kanaal opnieuw te configureren, aangevuld met Timer-4-interrupts aan het begin en einde van de cutout.
Omdat er per pakket tientallen microseconden beschikbaar zijn voor deze herconfiguratie, is er in de praktijk geen jitter tussen opeenvolgende DCC-pakketten. Voor de RailCom-Cutout-functie is theoretisch een zekere mate van jitter mogelijk, maar in de praktijk bleek dit niet meetbaar, mede omdat de interruptprioriteit instelbaar is en geoptimaliseerd kan worden.
Het resultaat is een zeer stabiel en zuiver DCC-signaal bij een lage CPU-belasting, aangezien er per pakket slechts een beperkt aantal (3) interrupts nodig is.

## RP2040/RP2350
De grootste verrassing voor ons waren de RP2040 en de RP2350, bekend van de Raspberry Pi Pico.
Originele Raspberry Pi Pico-boards kosten ongeveer 5 euro, en kleine boards zijn verkrijgbaar vanaf ongeveer 1,5 euro. De RP-familie bestaat uit slechts twee varianten, die qua software grotendeels compatibel zijn en over een interessante peripheral beschikken: de PIO (Programmable IO). Dit is in feite een kleine, gespecialiseerde coprocessor waarmee zeer nauwkeurig getakte uitgangssignalen kunnen worden gegenereerd. In combinatie met DMA kan het volledige DCC-signaal, inclusief RailCom-Cutout, volledig door één enkele PIO (waarin twee zeer eenvoudige toestandsmachines worden gebruikt) worden gegenereerd. Onze RP-implementatie levert een absoluut stabiel DCC-signaal zonder enige jitter tussen de pakketten of bij de cutout. Bovendien is de implementatie relatief eenvoudig en is de CPU-belasting minimaal: slechts één interrupt per pakket. Met een kloksnelheid van 125 tot 200 MHz en een dual-core-architectuur biedt de RP2040 bovendien heel veel rekenkracht. Voor het genereren van DCC-signalen is de RP2040 naar onze mening daarom de meest geschikte processor. Een nadeel is echter de relatief matige kwaliteit van de ADC, wat deze processor bijvoorbeeld minder geschikt maakt voor bezettingsmelders.

## Conclusie
Terwijl de ESP32 teleurstelt vanwege zijn niet-geoptimaliseerde RMT-driverimplementatie en jitterproblemen, genereren zowel DxCore als STM32 een goed DCC-signaal, zij het met verschillende compromissen. De RP2040/2350 springt er echter uit: met de beste DCC-signaalkwaliteit, de laagste CPU-belasting, lage kosten en een relatief eenvoudige implementatie. Daarom hebben we in onze centrale gekozen voor de RP2040/2350.

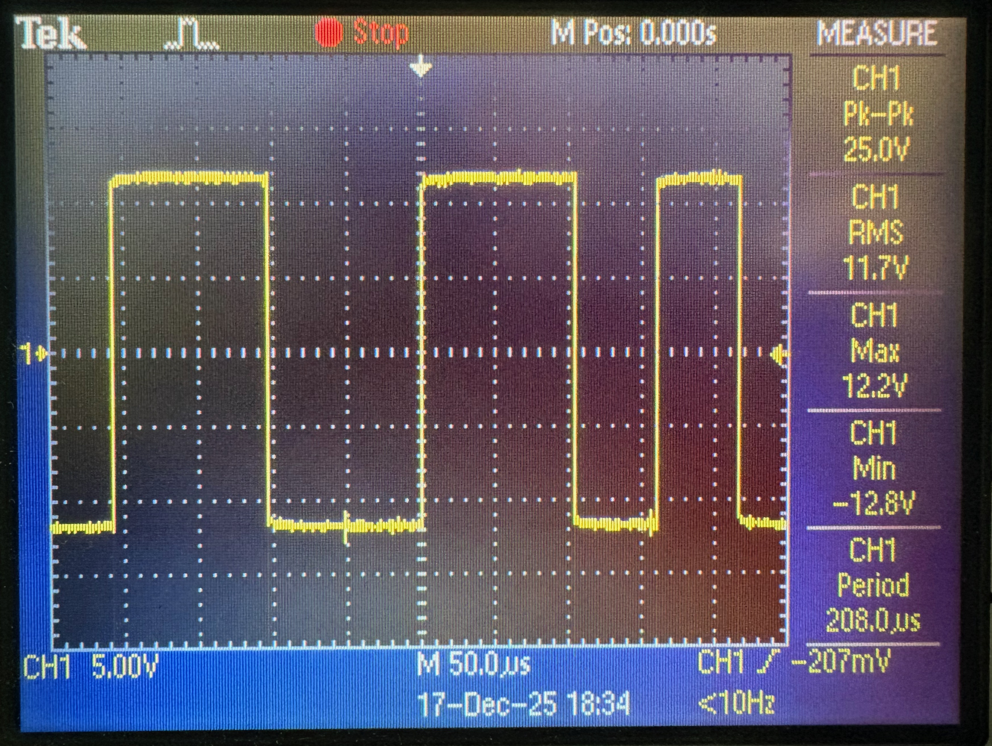
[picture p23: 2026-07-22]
docs/images/LZV100-CDE.jpeg

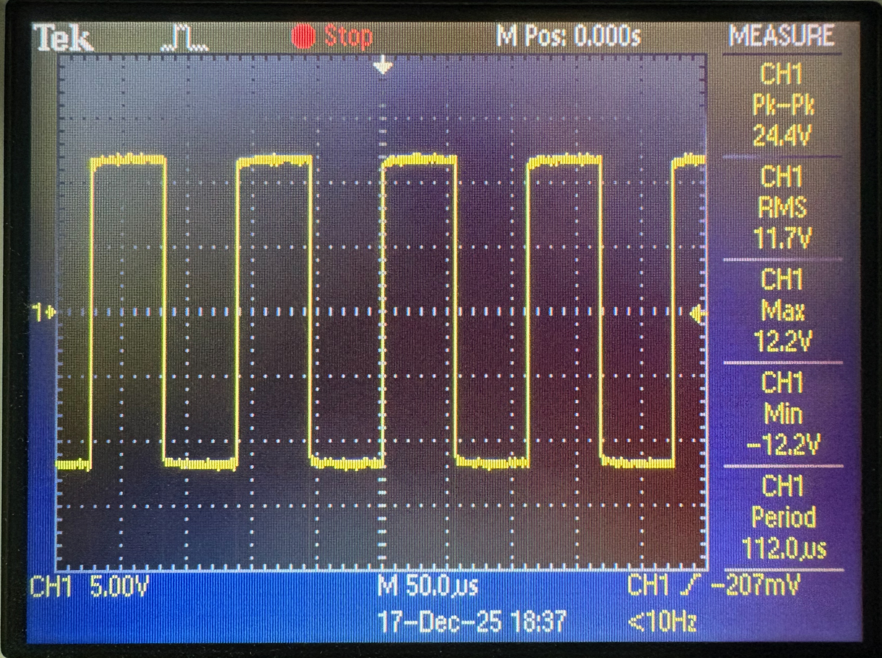
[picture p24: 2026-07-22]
docs/images/LZ100-CDE.jpeg

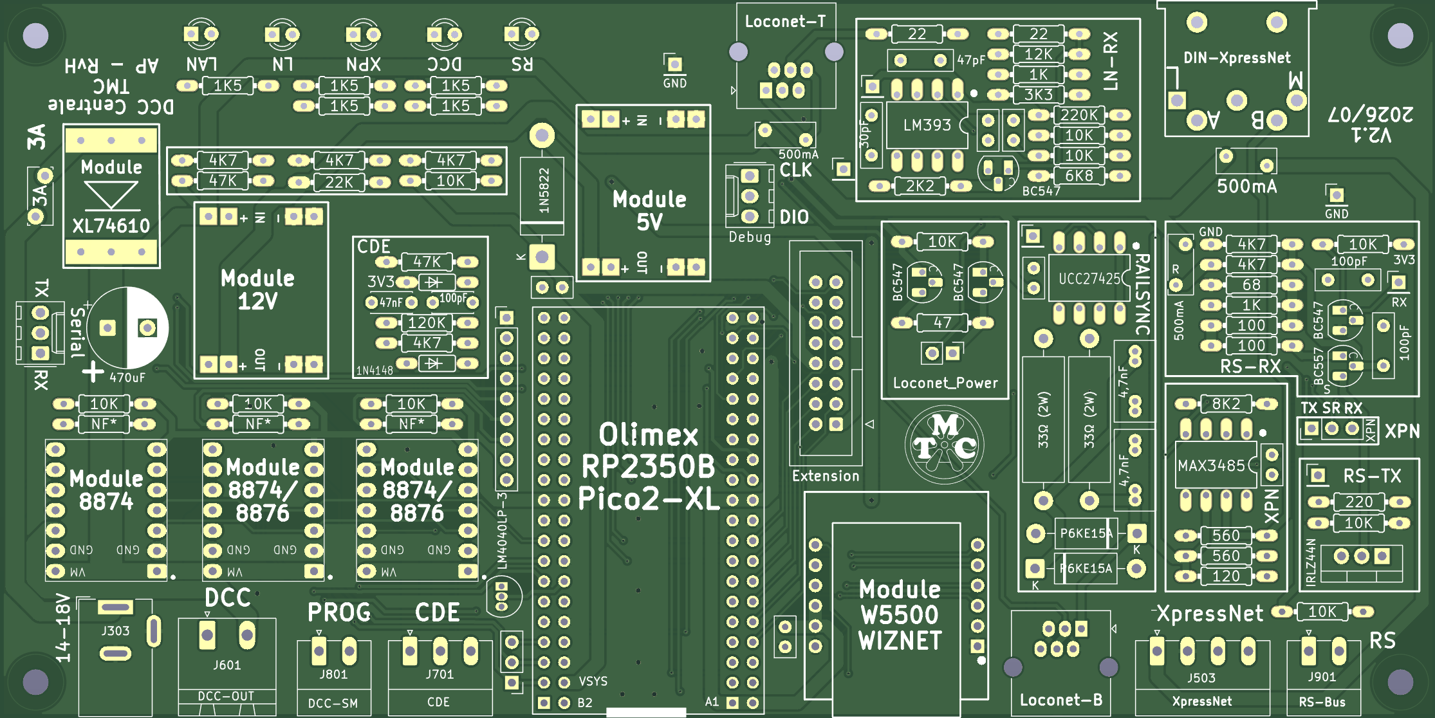
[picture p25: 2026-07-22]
docs/images/PCB-Top.png

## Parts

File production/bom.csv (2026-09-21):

Designator | Footprint | Quantity | Value | LCSC Part #
C1001 | C_Disc_D8.0mm_W2.5mm_P5.00mm | 1 | 47pF
C1002 | C_Disc_D8.0mm_W2.5mm_P5.00mm | 1 | 30pF
C1003, C1004, C201, C401, C501 | C_Disc_D5.0mm_W2.5mm_P2.50mm | 5 | 100nF
C301 | CP_Radial_D10.0mm_P5.00mm | 1 | 470uF
C701 | C_Disc_D5.0mm_W2.5mm_P5.00mm | 1 | 100nF
C702 | C_Disc_D5.0mm_W2.5mm_P5.00mm | 1 | 100pF
C901, C902 | C_Disc_D8.0mm_W2.5mm_P5.00mm | 2 | 100pF
D201 | LED_D3.0mm | 1 | LAN
D202 | LED_D3.0mm | 1 | LN
D203 | LED_D3.0mm | 1 | XPN
D204 | LED_D3.0mm | 1 | DCC
D205, D206 | LED_D3.0mm | 2 | RS
D301 | D_DO-201AD_P15.24mm_Horizontal | 1 | 1N5822
D302 | Module-XL74610 | 1 | D
D701 | DO35-7 | 1 | 1N4148
F1001, F501 | Fuse_Bourns_MF-RHT050 | 2 | Polyfuse 500mA
F301 | Fuse_Bourns_MF-RG300 | 1 | Polyfuse
F901 | Fuse_Bourns_MF-RHT050 | 1 | 500mA
J1001 | PinHeader_1x02_P2.54mm_Vertical | 1 | Loconet_Power
J1002 | RJ25_Wayconn_MJEA-660X1_Horizontal | 1 | Loconet-T
J1003 | PinHeader_1x01_P2.54mm_Vertical | 1 | LN_RX
J1004 | PinHeader_1x01_P2.54mm_Vertical | 1 | LN_TX
J1006 | RJ25_Wayconn_MJEA-660X1_Horizontal | 1 | Loconet-B
J201 | IDC-Header_2x08_P2.54mm_Vertical | 1 | Extension
J202 | Molex_KK-254_AE-6410-03A_1x03_P2.54mm_Vertical | 1 | Debug
J203 | Molex_KK-254_AE-6410-03A_1x03_P2.54mm_Vertical | 1 | Serial
J204 | PinHeader_1x03_P2.54mm_Vertical | 1 | DCC
J205 | PinHeader_1x09_P2.54mm_Vertical | 1 | Sense
J301, J302 | PinHeader_1x01_P2.54mm_Vertical | 2 | GND
J303 | Connector-Power-Barrel-Jack | 1 | Connector-Power-Barrel-Jack
J501 | Connector-DIN-XpressNet | 1 | DIN-XpressNet
J502 | PinHeader_1x03_P2.54mm_Vertical | 1 | XPN
J503 | PhoenixContact_MC_1,5_4-G-3.81_1x04_P3.81mm_Horizontal | 1 | XpressNet
J601 | PhoenixContact_MSTBA_2,5_2-G_1x02_P5.00mm_Horizontal | 1 | DCC-OUT
J701 | PhoenixContact_MC_1,5_3-G-3.81_1x03_P3.81mm_Horizontal | 1 | CDE
J801 | PhoenixContact_MC_1,5_2-G-3.81_1x02_P3.81mm_Horizontal | 1 | DCC-SM
J901 | PhoenixContact_MC_1,5_2-G-3.81_1x02_P3.81mm_Horizontal | 1 | RS-Bus
J902 | PinHeader_1x01_P2.54mm_Vertical | 1 | RS_TX
J903 | PinHeader_1x01_P2.54mm_Vertical | 1 | RS_RX
Q1001, Q1002, Q1003, Q903 | TO-92_BC5xx_HandSolder | 4 | BC547
Q901 | TO-92_BC5xx_HandSolder | 1 | BC557
Q902 | TO-220-3_Vertical | 1 | IRLZ44N
R1001, R1005, R1006, R203, R602, R701, R802, R901, R905, R908 | R-0207-10 | 10 | 10K
R1002 | R-0207-10 | 1 | 47
R1003, R1004 | R-0207-10 | 2 | 22
R1007 | R-0207-10 | 1 | 12K
R1008 | R-0207-10 | 1 | 2K2
R1009, R909 | R-0207-10 | 2 | 1K
R1010 | R-0207-10 | 1 | 220K
R1011 | R-0207-10 | 1 | 3K3
R1012 | R-0207-10 | 1 | 6K8
R201 | R-0207-10 | 1 | 47K
R202 | R-0207-10 | 1 | 22K
R204, R205, R206, R207, R208, R212 | R-0207-10 | 6 | 1K5
R209, R210, R211, R703, R902, R903 | R-0207-10 | 6 | 4K7
R501, R503 | R-0207-10 | 2 | 560
R502 | R-0207-10 | 1 | 120
R504 | R-0207-10 | 1 | 8K2
R601, R702, R801 | R-0207-10 | 3 | NF*
R704 | R-0207-10 | 1 | 56K
R705 | R-0207-10 | 1 | 18K
R904, R906 | R-0207-10 | 2 | 100
R907 | R-0207-10 | 1 | 220
R910 | R-0207-10 | 1 | 68
U1001 | DIL08 | 1 | LM393
U201 | Module-RP2350B-XXL-Olimex | 1 | RaspberryPi_Pico2_Module-RP2350B-XXL-Olimex
U202 | TO-92_Inline | 1 | LM4040LP-3
U301 | Module-StepDown-MP1584-Formfactor | 1 | 5V Step down Module
U302 | Module-StepDown-MP1584-Formfactor | 1 | 12V Step down Module
U401 | Module-W5500 | 1 | Module-W5500
U501 | DIL08 | 1 | MAX3485
U601 | Module-DRV8874 | 1 | DRV8874
U701 | Module-DRV8874 | 1 | DRV8876
U801 | Module-DRV8874 | 1 | DRV8874/8876

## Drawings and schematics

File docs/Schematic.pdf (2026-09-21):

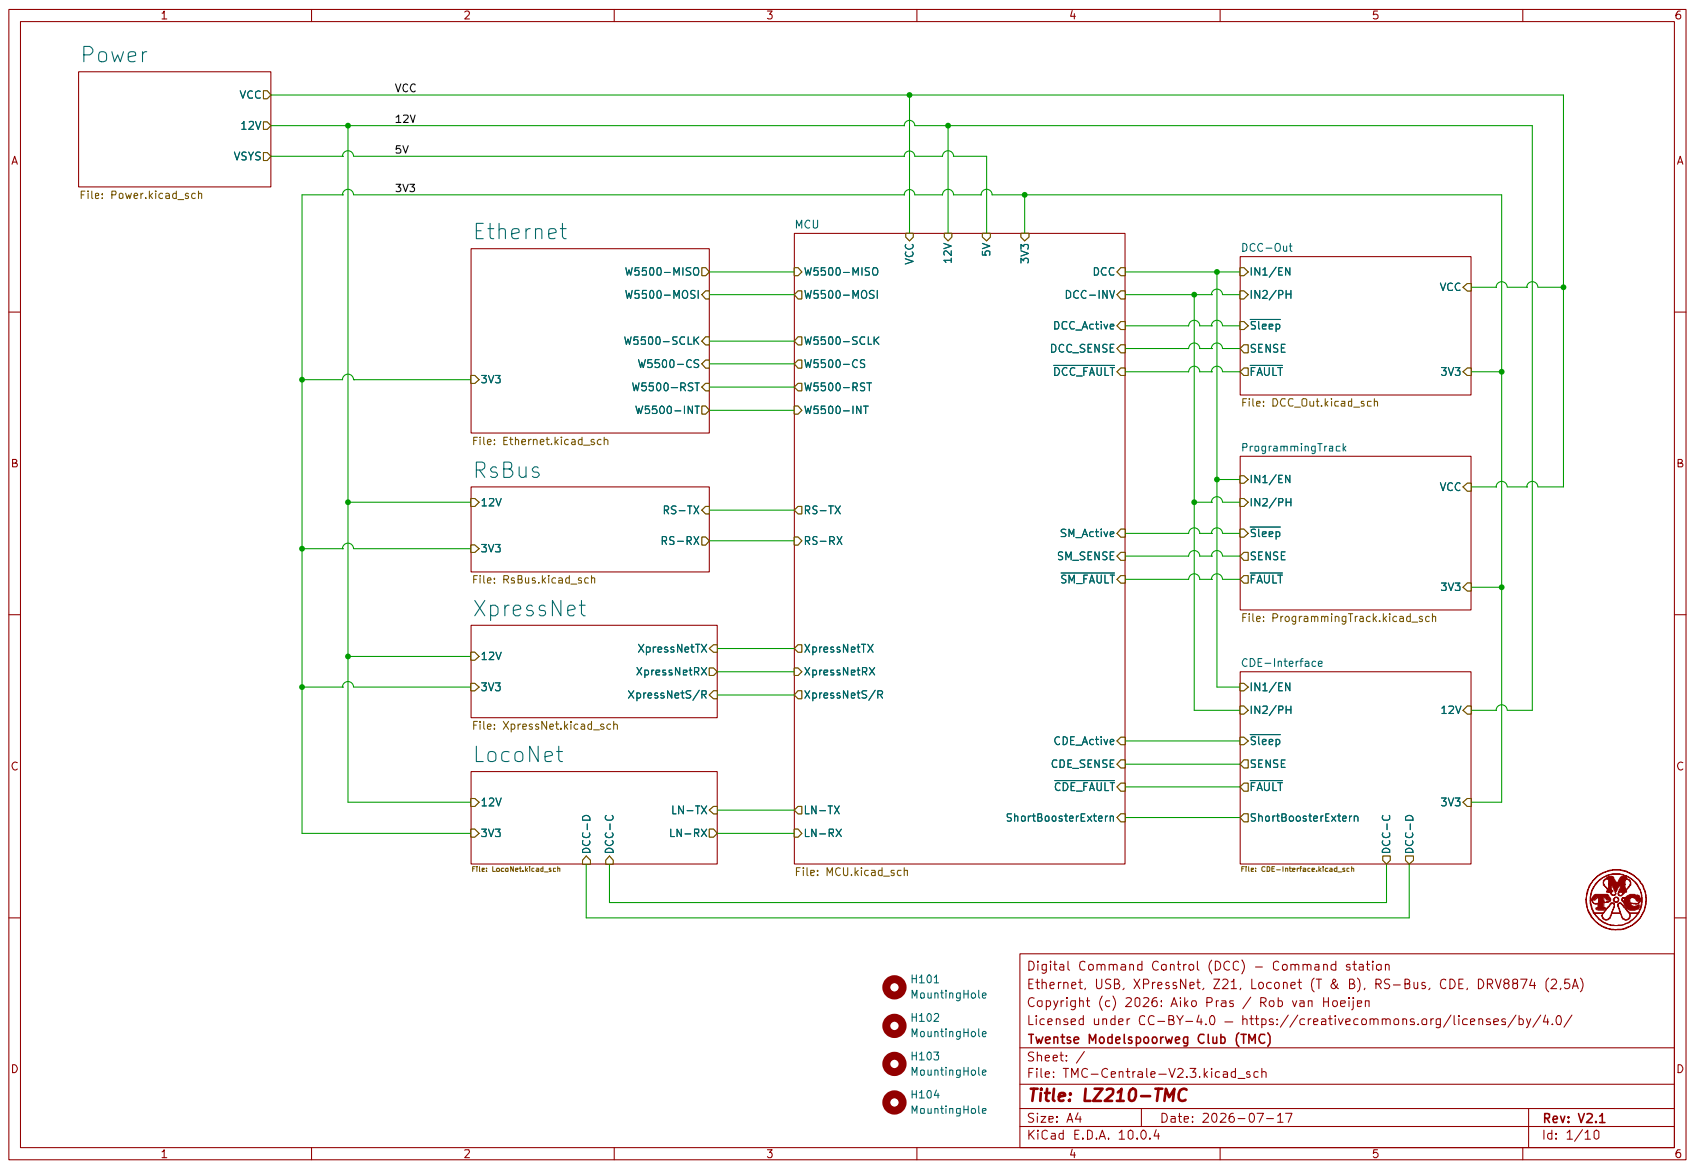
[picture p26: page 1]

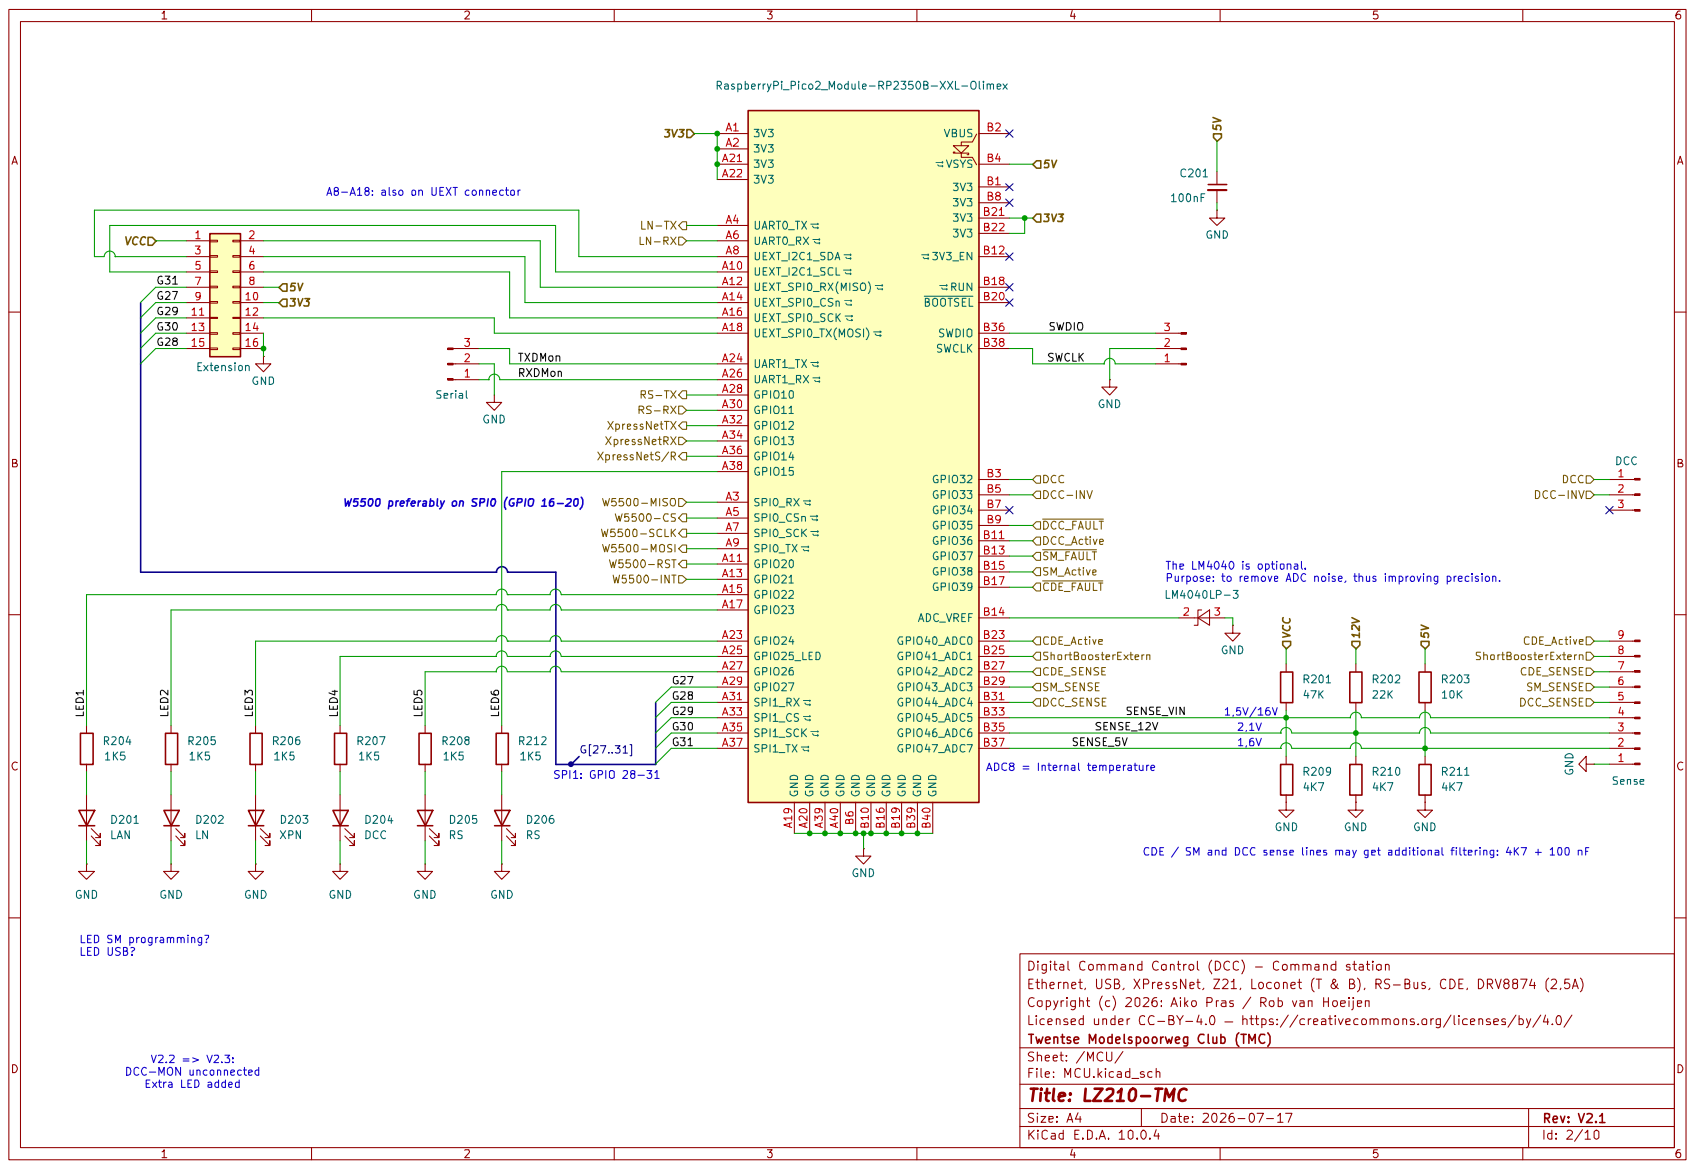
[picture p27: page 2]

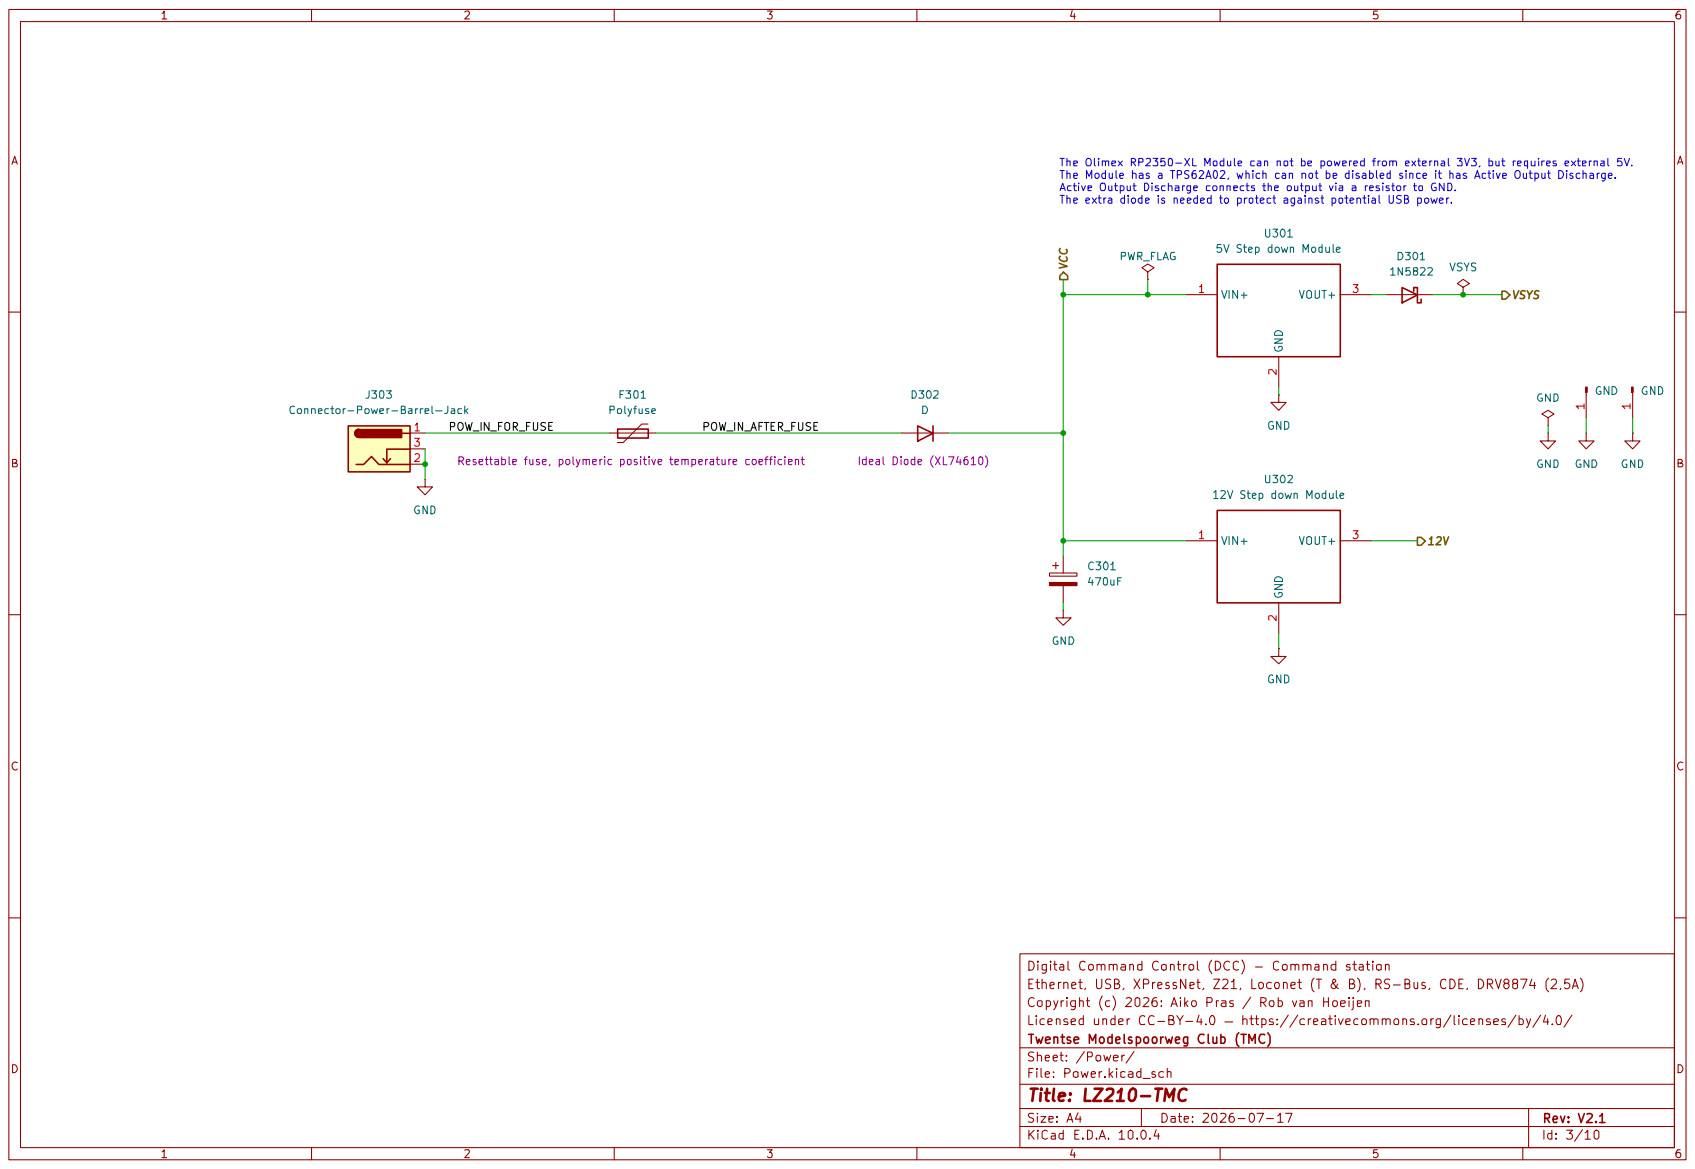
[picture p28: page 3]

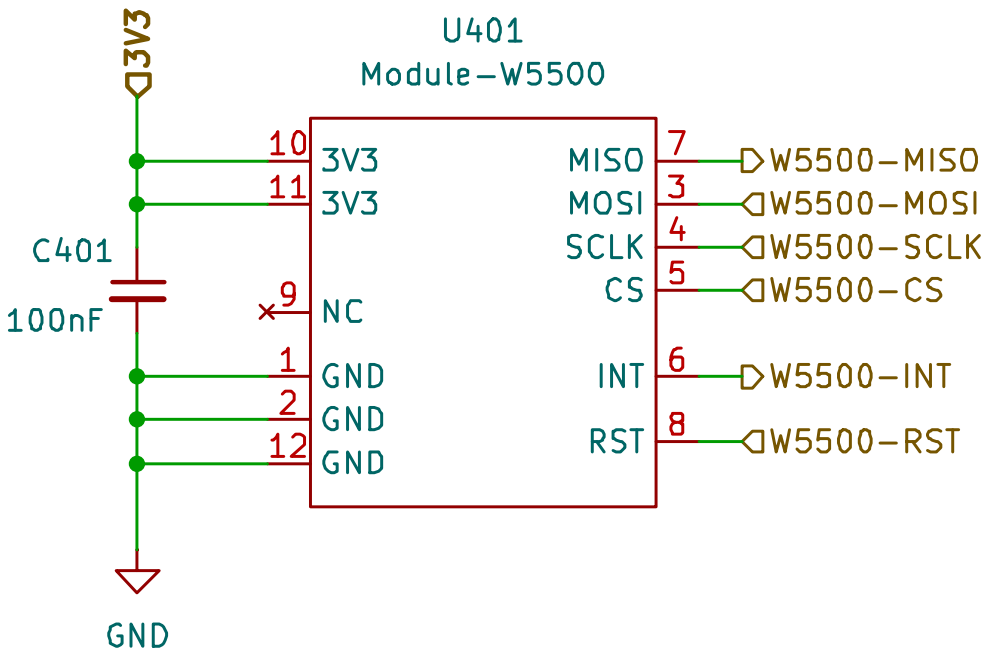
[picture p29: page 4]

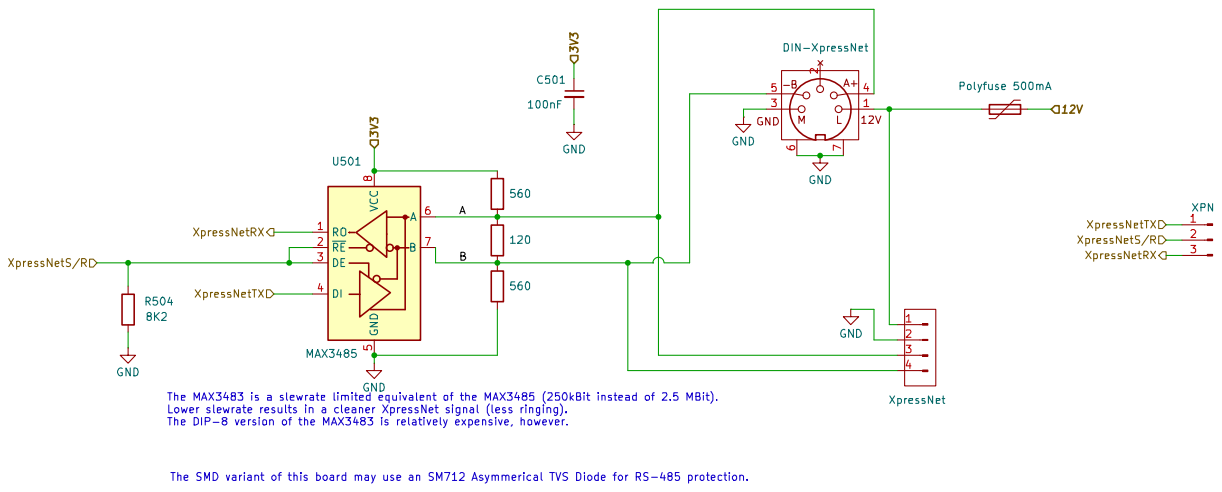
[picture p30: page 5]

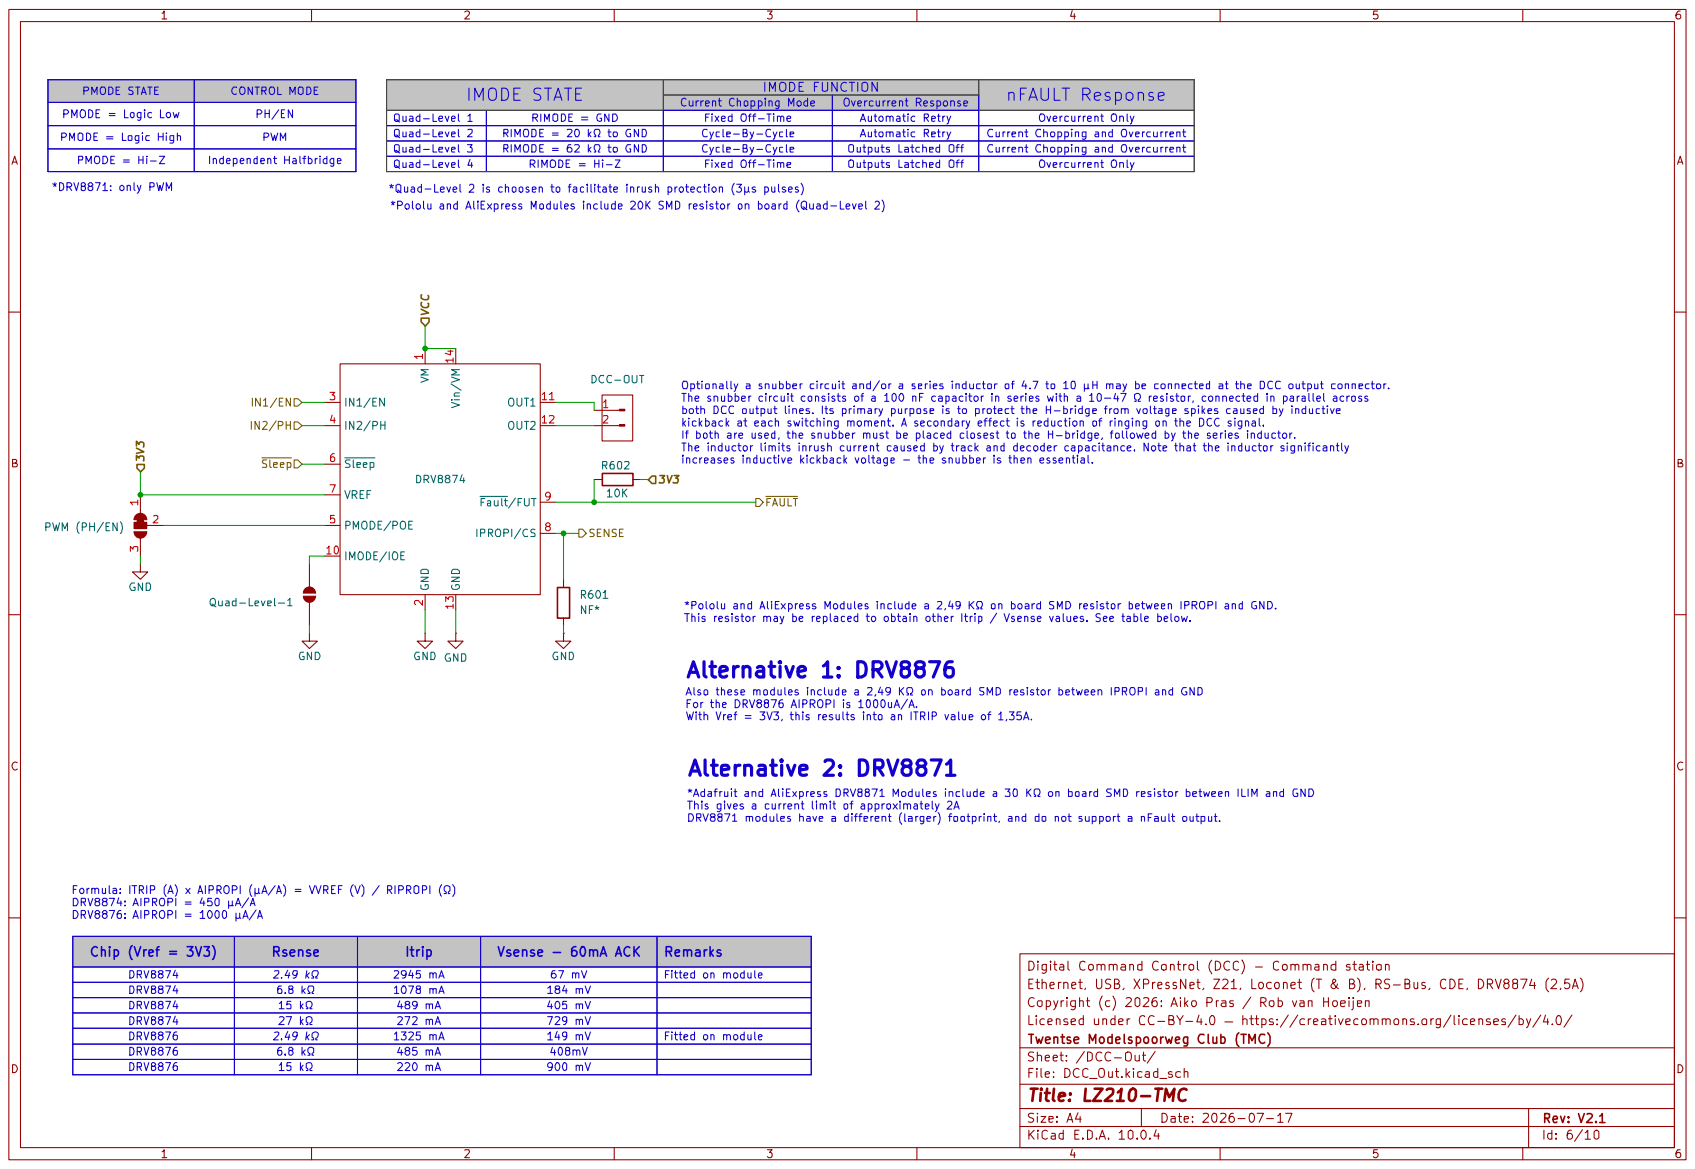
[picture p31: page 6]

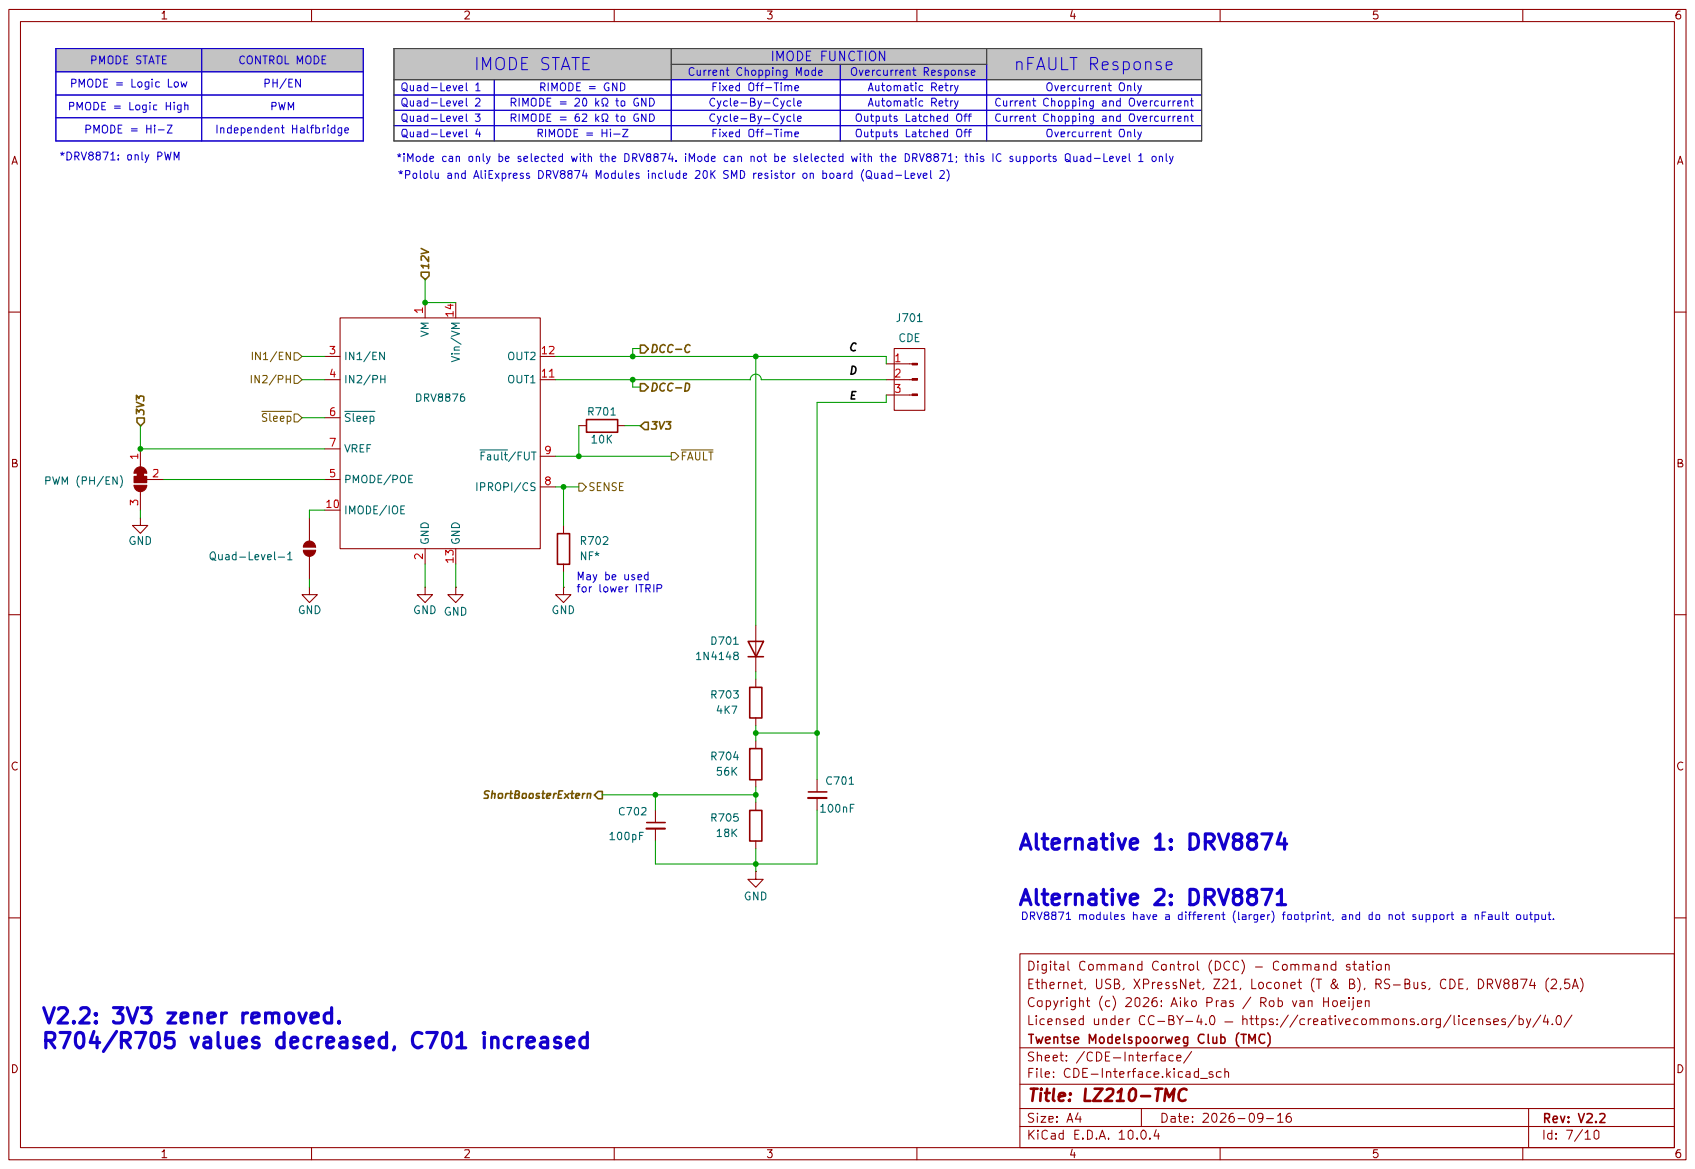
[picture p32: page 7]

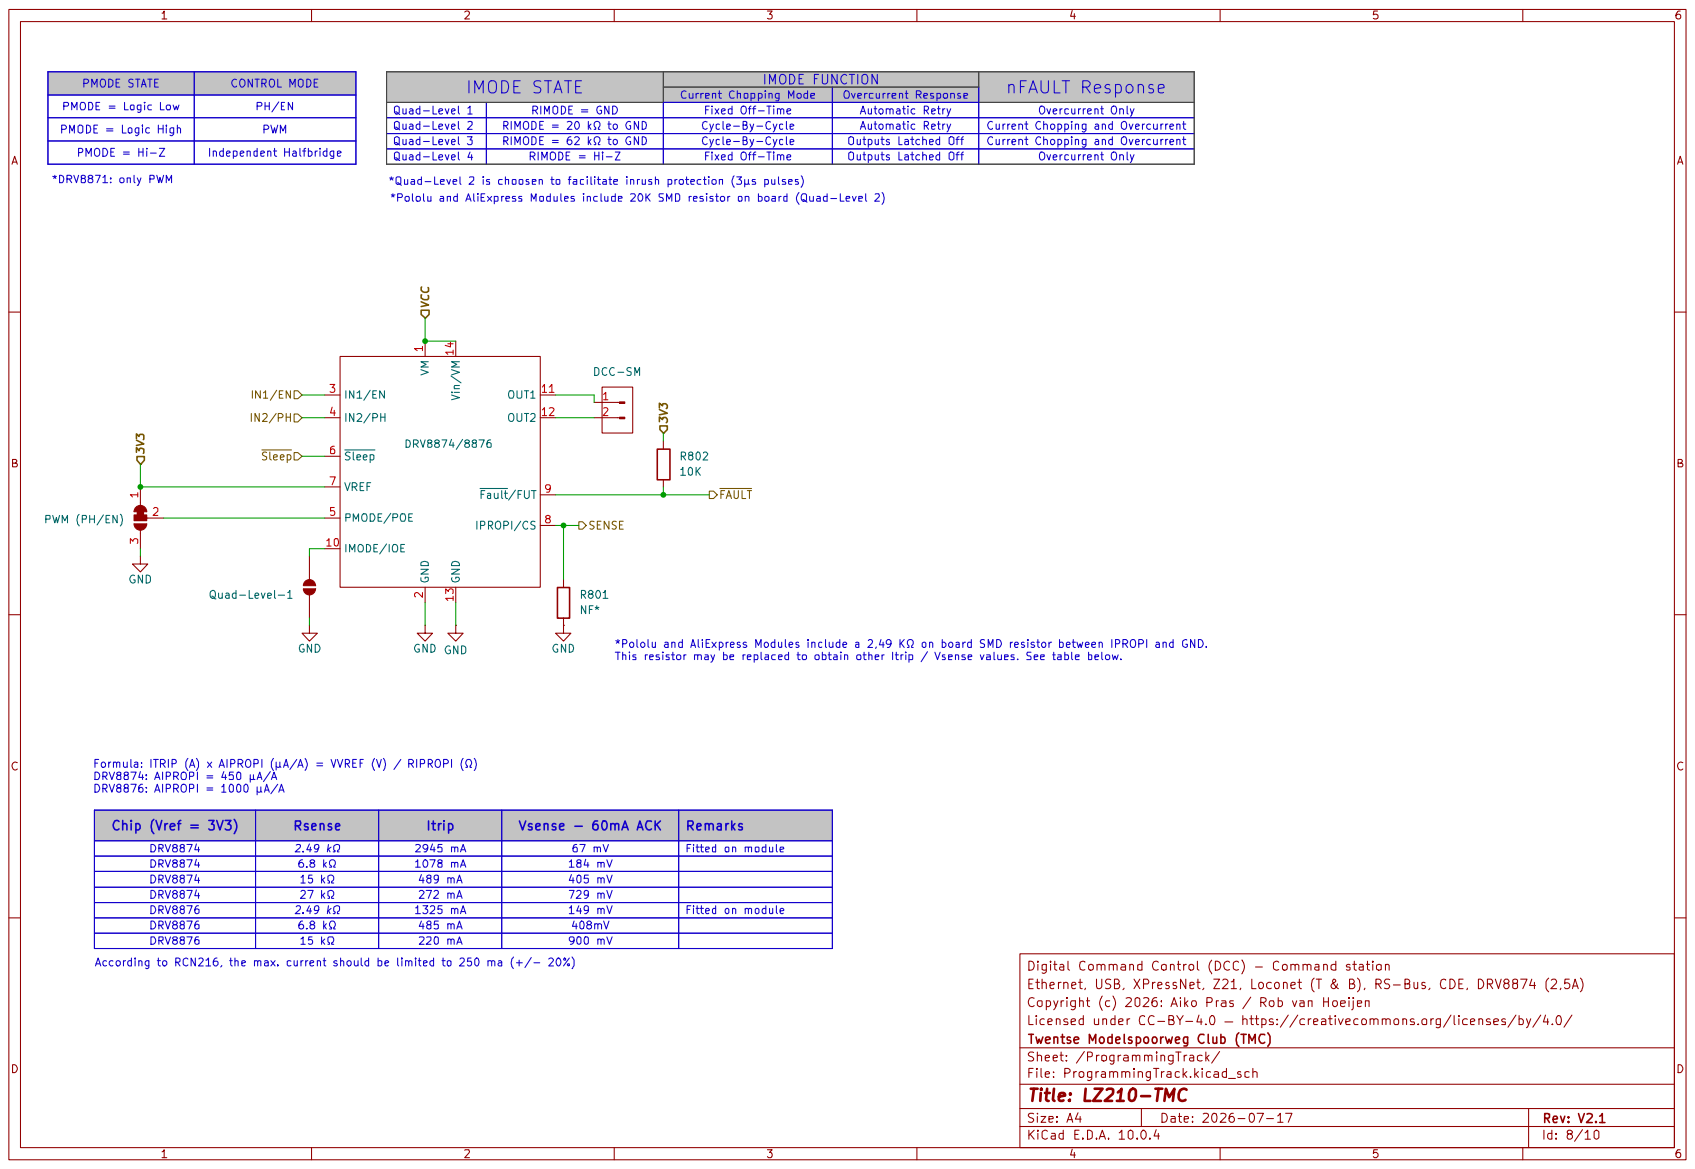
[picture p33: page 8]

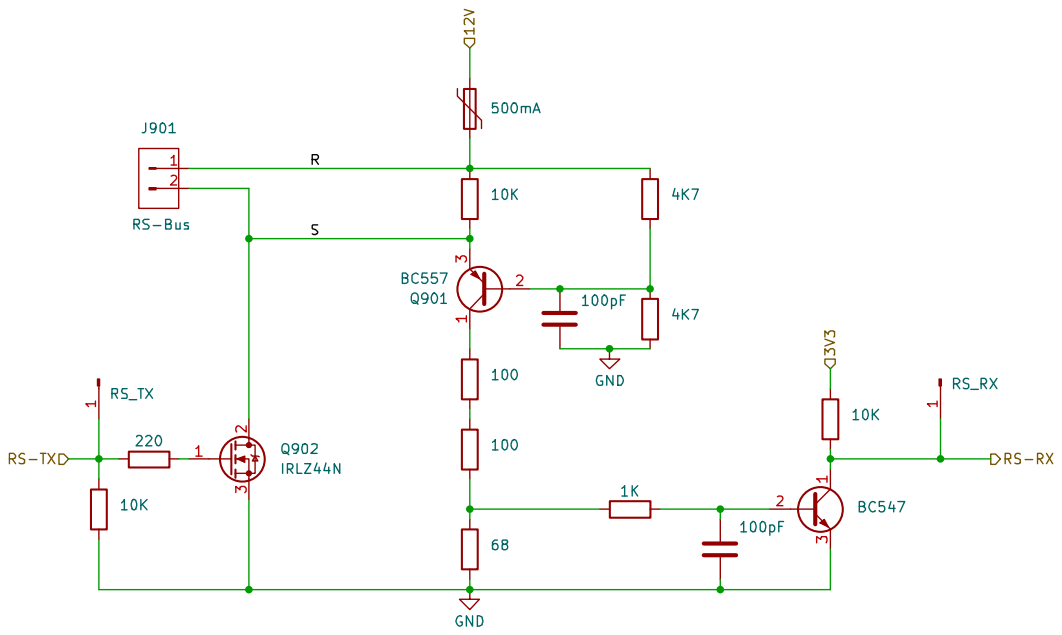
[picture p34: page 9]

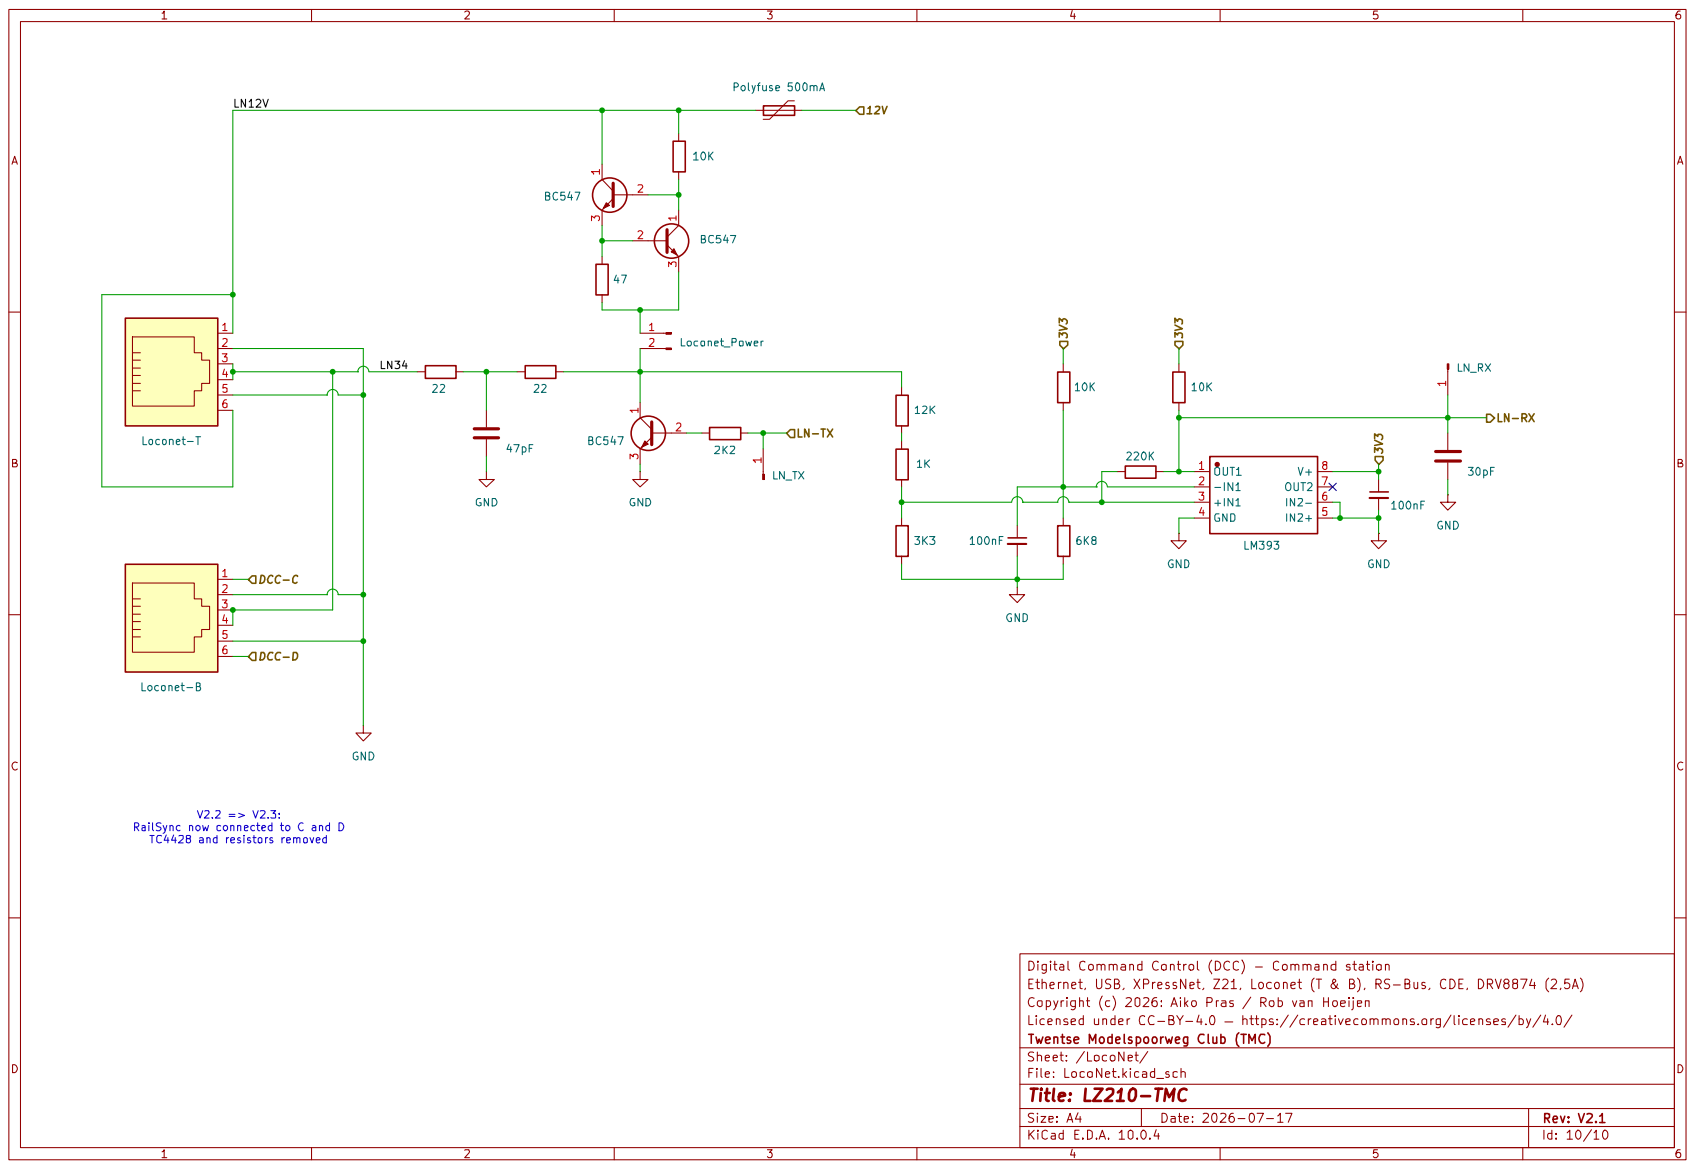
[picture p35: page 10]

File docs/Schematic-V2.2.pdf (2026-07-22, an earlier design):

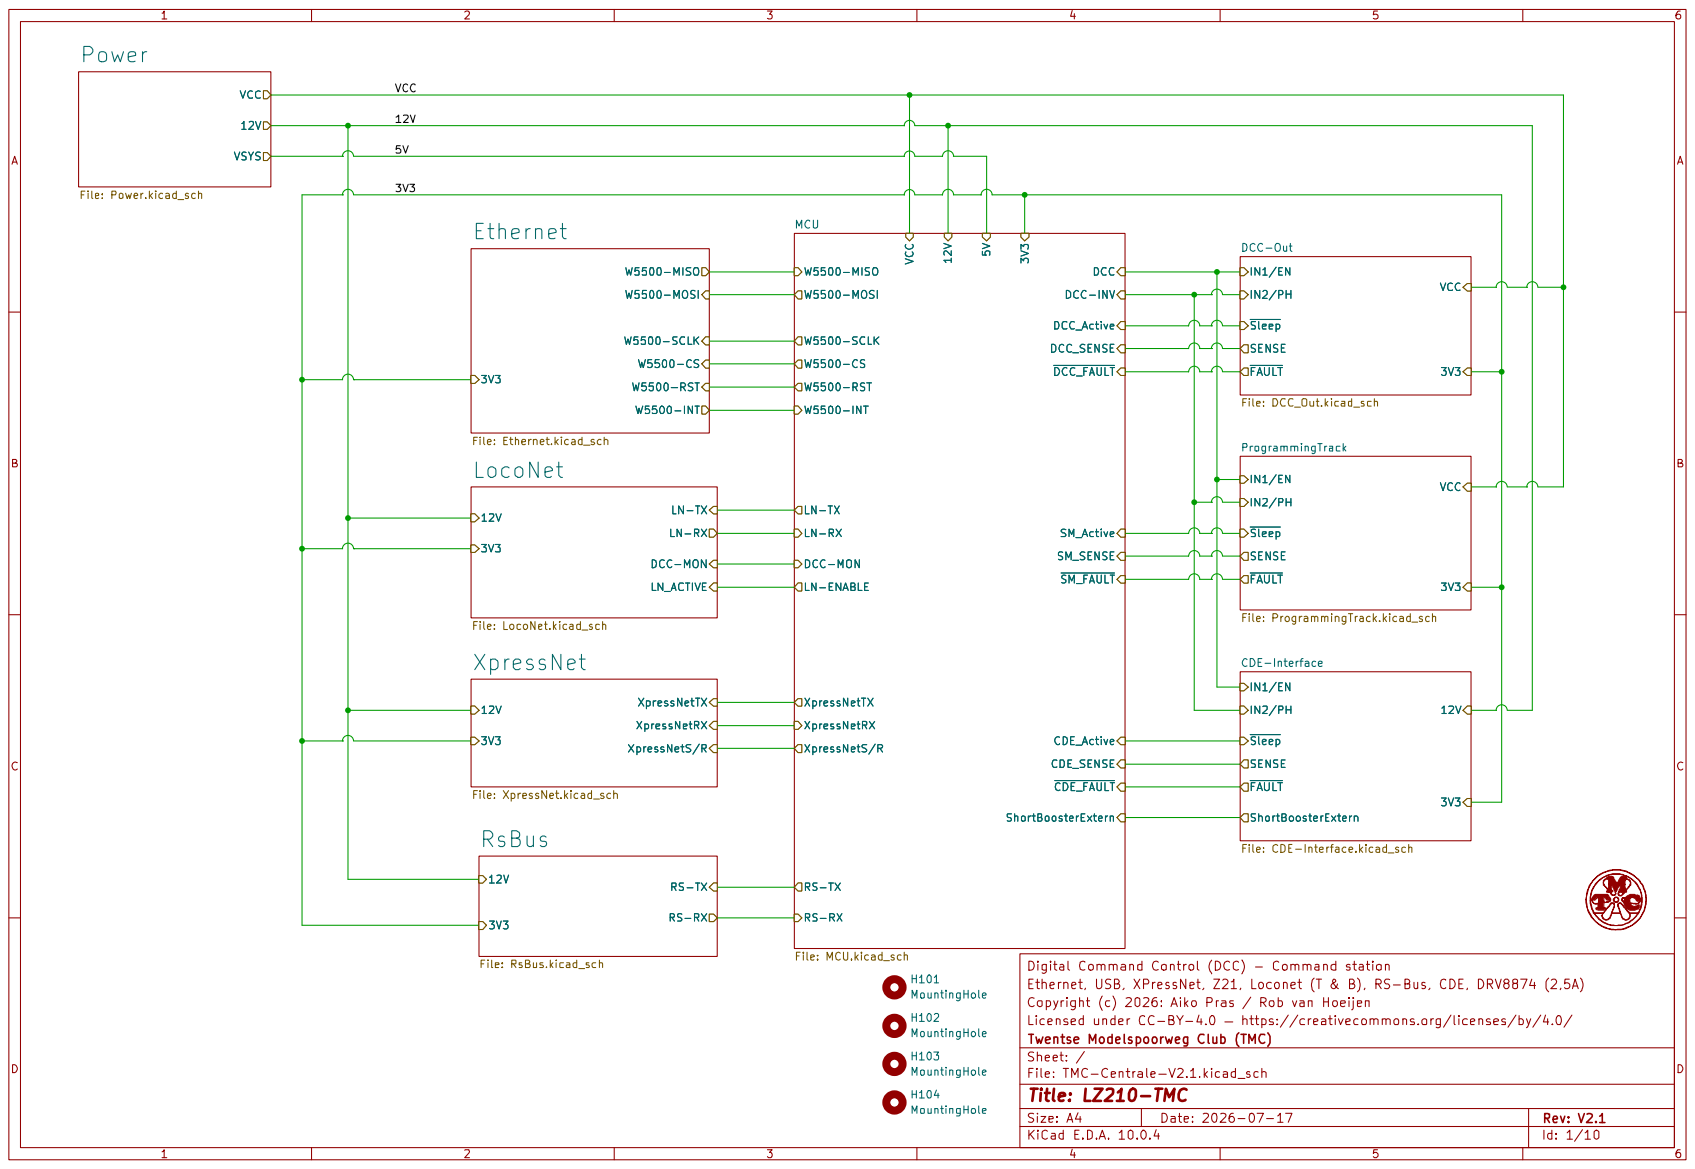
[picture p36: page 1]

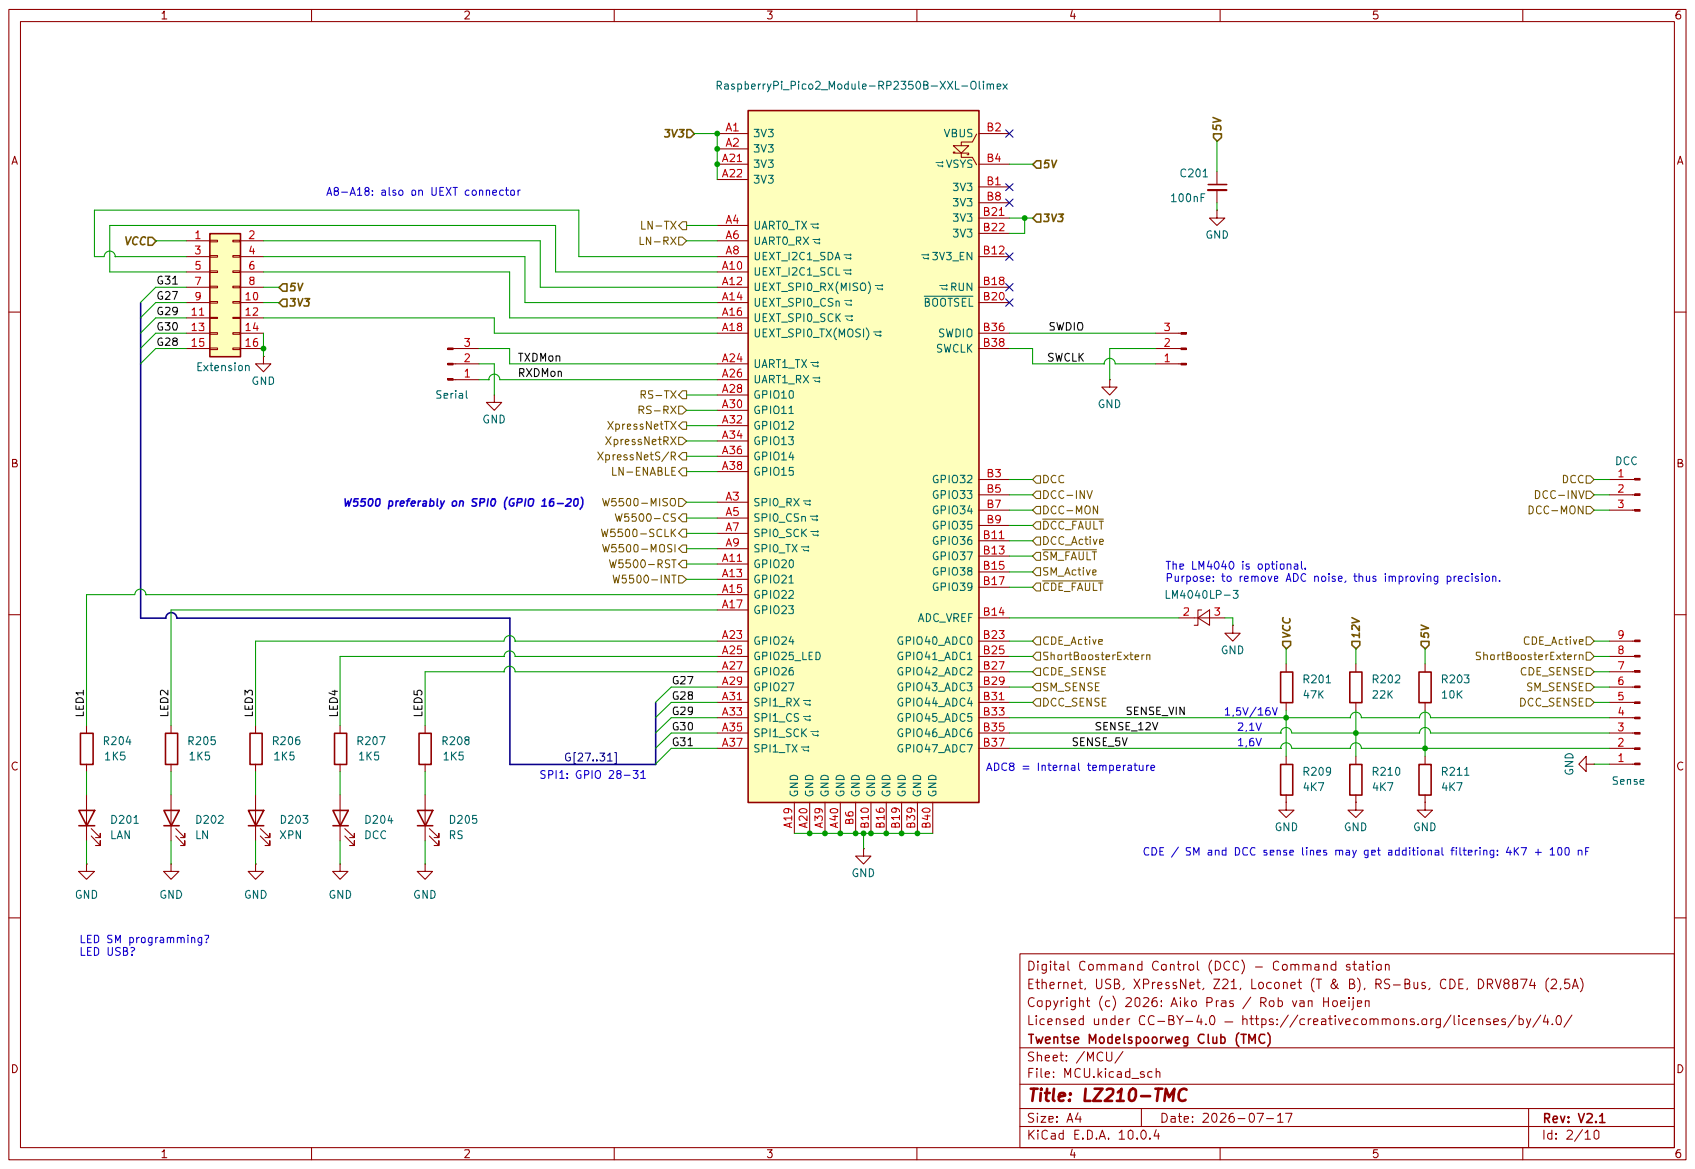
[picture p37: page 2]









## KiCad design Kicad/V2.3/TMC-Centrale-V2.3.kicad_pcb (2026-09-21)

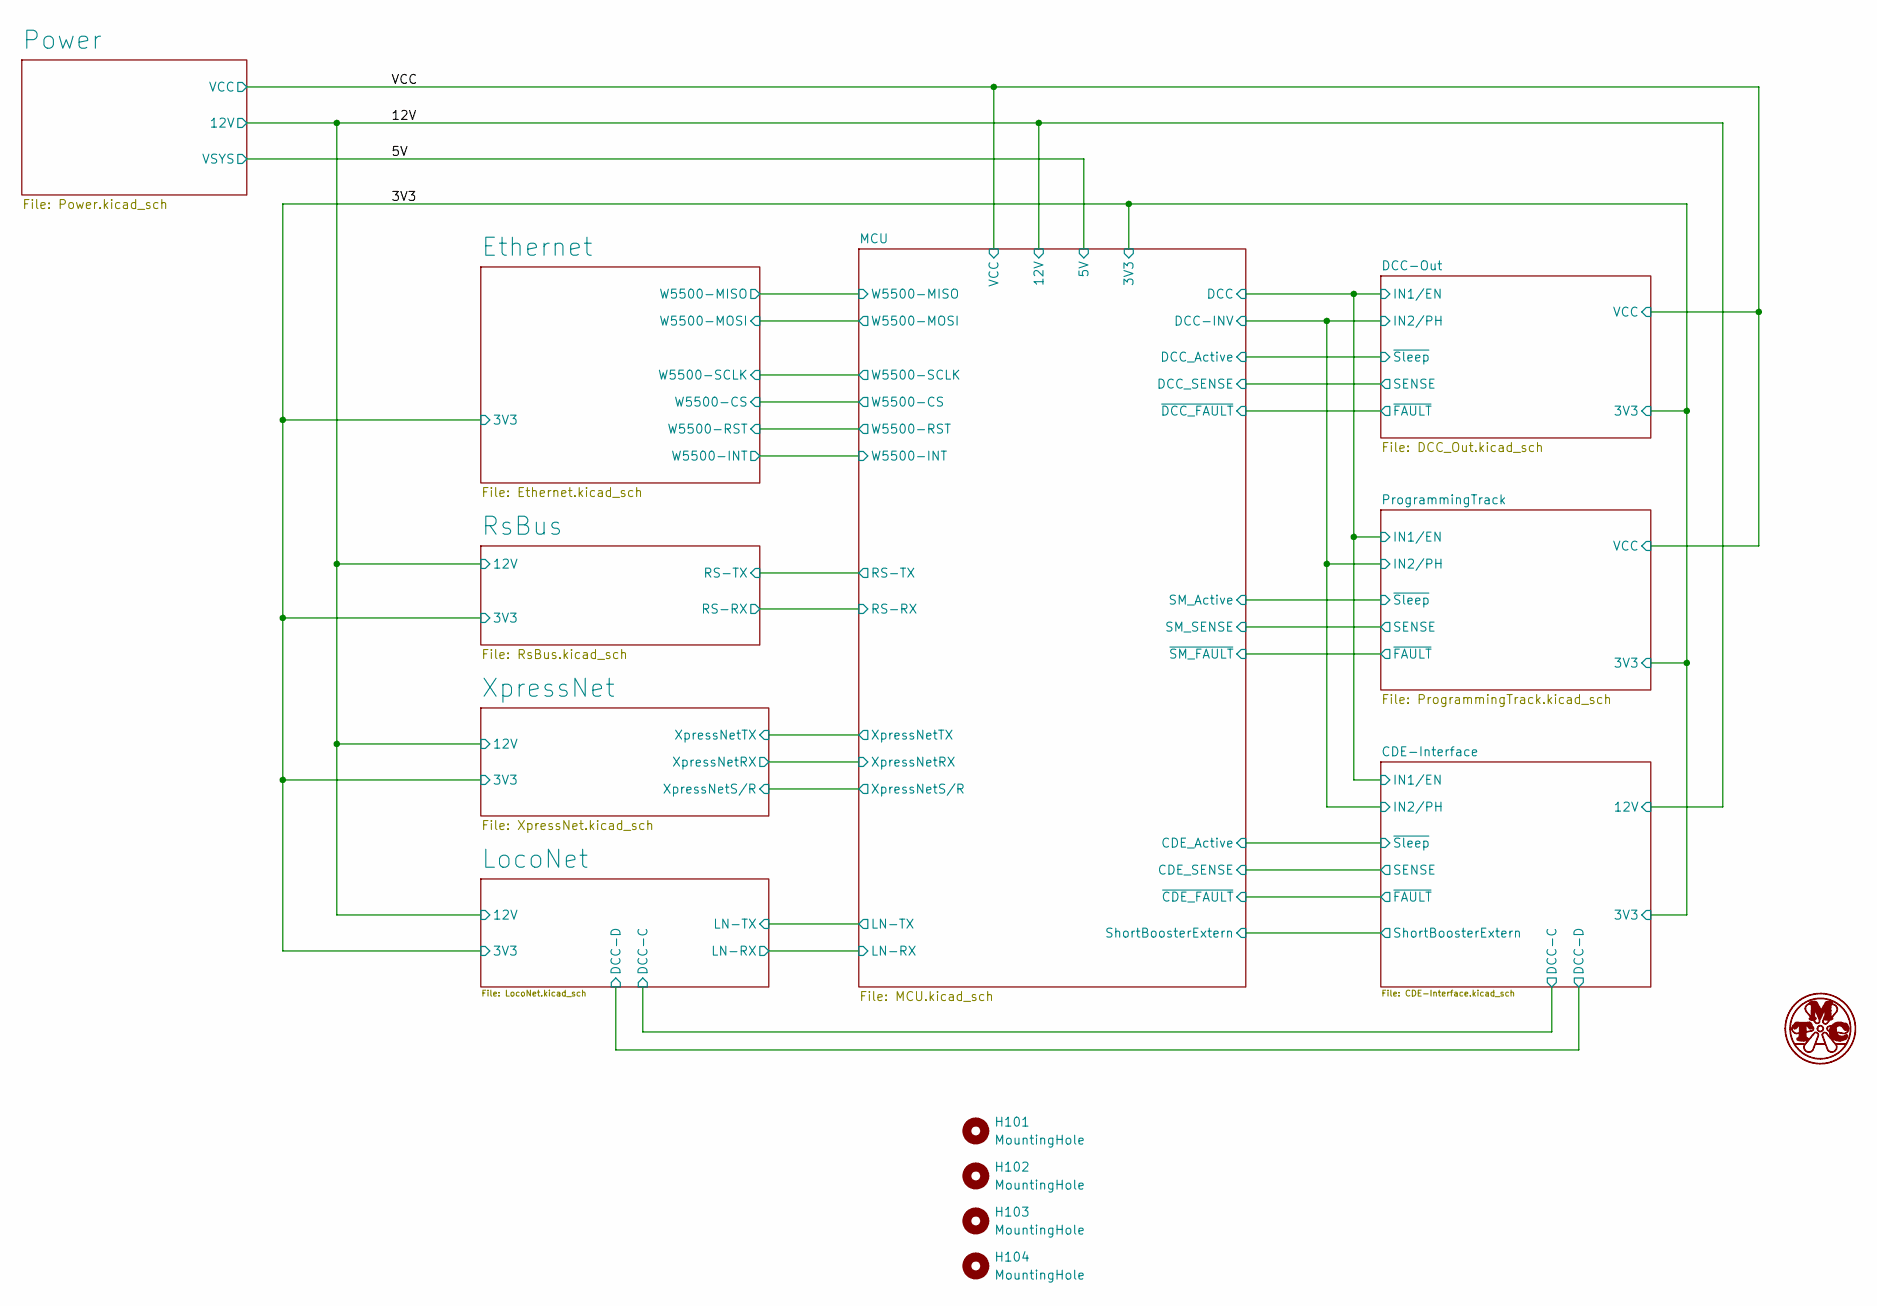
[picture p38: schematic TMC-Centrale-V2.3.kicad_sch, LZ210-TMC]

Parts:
H101, H102, H103, H104: MountingHole; MountingHole_3.2mm_M3

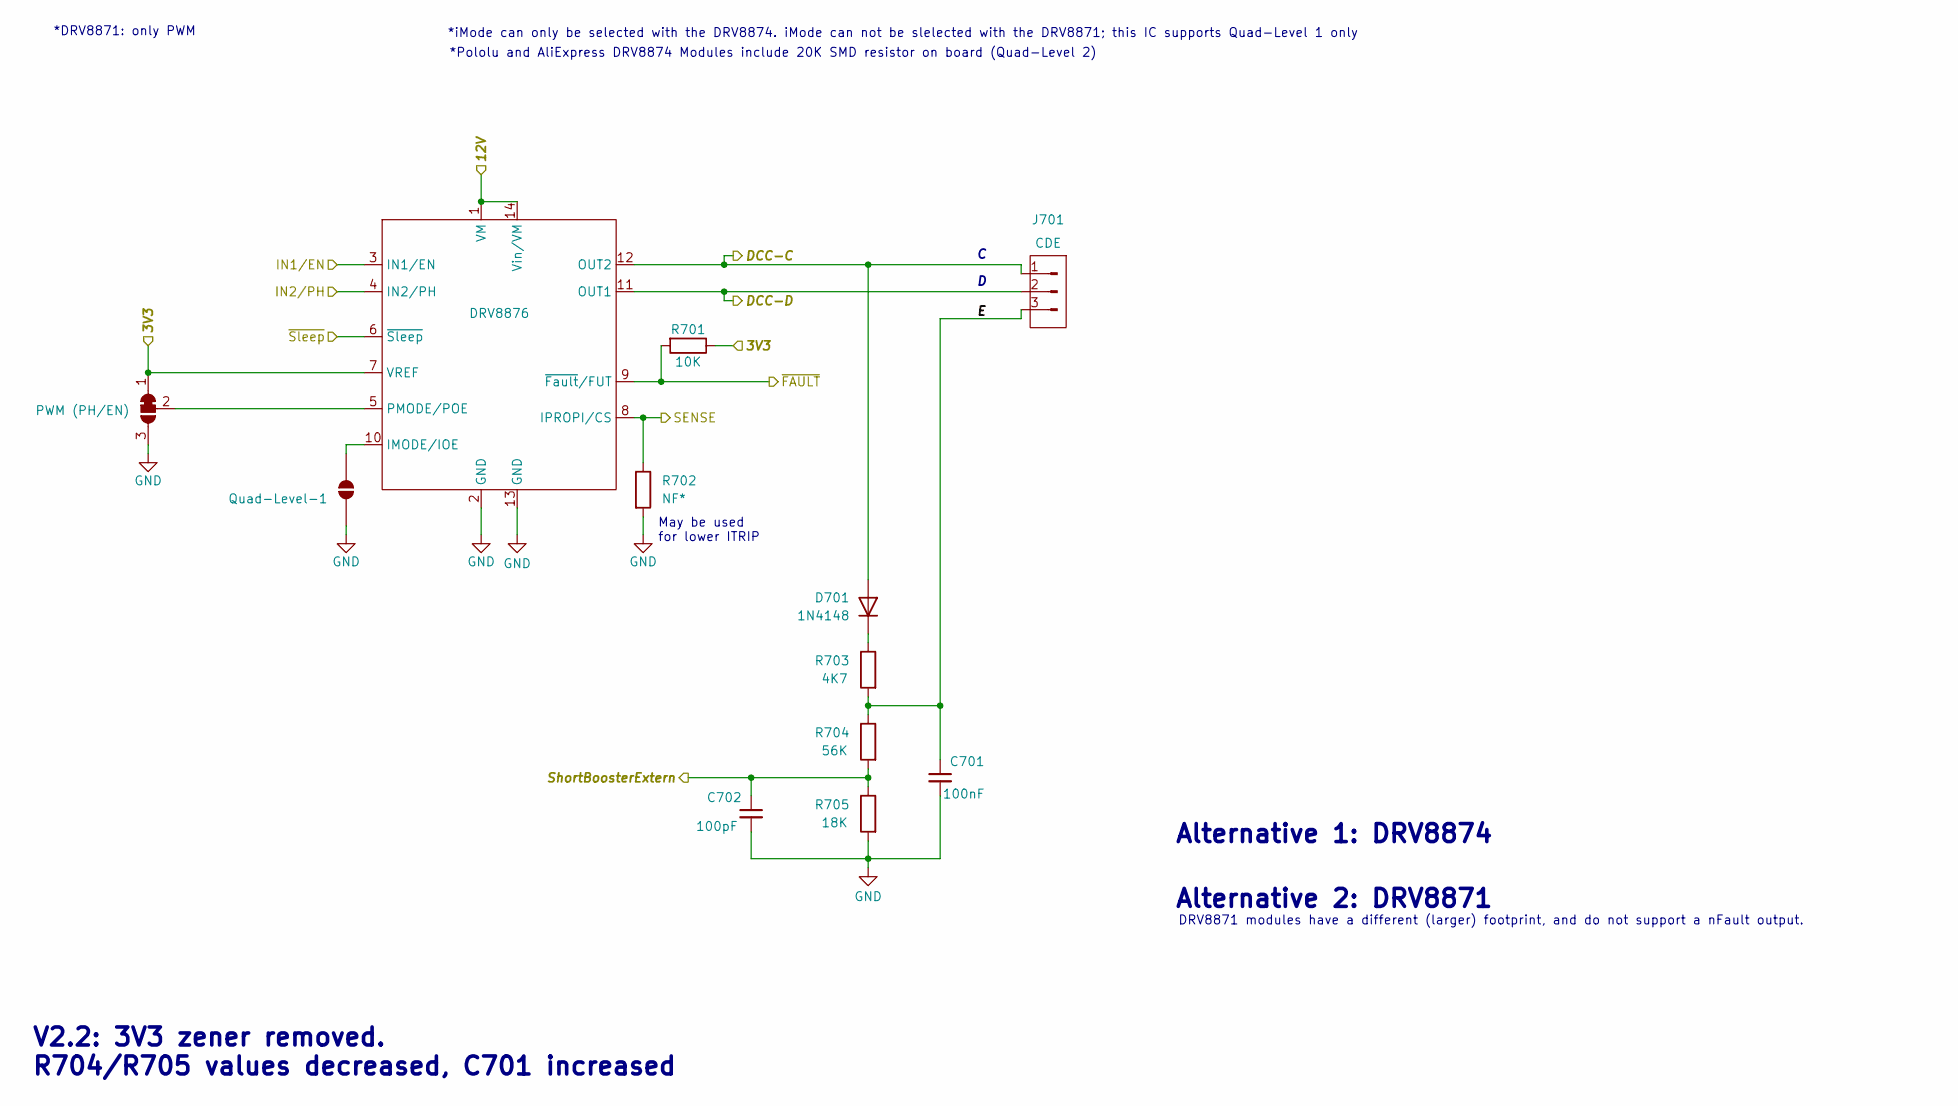
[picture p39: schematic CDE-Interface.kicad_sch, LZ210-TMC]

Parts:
C701: 100nF; C_Disc_D5.0mm_W2.5mm_P5.00mm
C702: 100pF; C_Disc_D5.0mm_W2.5mm_P5.00mm
D701: 1N4148; DO35-7
J701: CDE; PhoenixContact_MC_1,5_3-G-3.81_1x03_P3.81mm_Horizontal
JP701: PWM (PH/EN); SolderJumper-3_P1.3mm_Bridged12_RoundedPad1.0x1.5mm_NumberL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
JP702: Quad-Level-1; SolderJumper-2_P1.3mm_Open_RoundedPad1.0x1.5mm
R701: 10K; R-0207-10
R702: NF*; R-0207-10
R703: 4K7; R-0207-10
R704: 56K; R-0207-10
R705: 18K; R-0207-10
U701: DRV8876; Module-DRV8874

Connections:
/3V3: JP701.1 (A), R701.1, U701.7 (VREF); also elsewhere on the board
/12V: U701.1 (VM), U701.14 (Vin/VM); also elsewhere on the board
/CDE-Interface/DCC-C: D701.2 (A), J701.1, U701.12 (OUT2); also elsewhere on the board
/CDE-Interface/DCC-D: J701.2, U701.11 (OUT1); also elsewhere on the board
/CDE-Interface/E: C701.1, J701.3, R703.2, R704.1
/CDE-Interface/IN1/EN: U701.3 (IN1/EN); also elsewhere on the board
/CDE-Interface/IN2/PH: U701.4 (IN2/PH); also elsewhere on the board
/CDE-Interface/SENSE: R702.1, U701.8 (IPROPI/CS); also elsewhere on the board
/CDE-Interface/ShortBoosterExtern: C702.1, R704.2, R705.1; also elsewhere on the board
/CDE-Interface/~FAULT: R701.2, U701.9 (~Fault/FUT); also elsewhere on the board
/CDE-Interface/~Sleep: U701.6 (~Sleep); also elsewhere on the board
GND: C701.2, C702.2, JP701.3 (B), JP702.1 (A), R702.2, R705.2, U701.2 (GND), U701.13 (GND); also elsewhere on the board
unnamed: D701.1 (K), R703.1
unnamed: JP701.2 (C), U701.5 (PMODE/POE)
unnamed: JP702.2 (B), U701.10 (IMODE/IOE)

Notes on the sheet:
*iMode can only be selected with the DRV8874. iMode can not be slelected with the DRV8871; this IC supports Quad-Level 1 only
May be used for lower ITRIP
DRV8871 modules have a different (larger) footprint, and do not support a nFault output.
Alternative 1: DRV8874
*Pololu and AliExpress DRV8874 Modules include 20K SMD resistor on board (Quad-Level 2)
Alternative 2: DRV8871
V2.2: 3V3 zener removed. R704/R705 values decreased, C701 increased
*DRV8871: only PWM

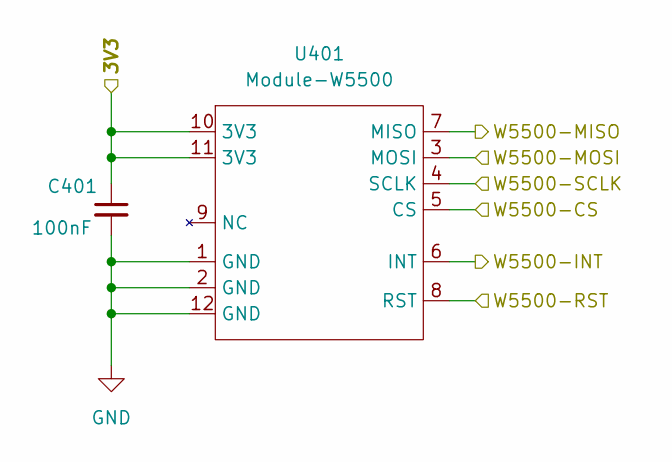
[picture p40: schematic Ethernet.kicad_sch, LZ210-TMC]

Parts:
C401: 100nF; C_Disc_D5.0mm_W2.5mm_P2.50mm
U401: Module-W5500

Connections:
/3V3: C401.1, U401.10 (3V3), U401.11 (3V3); also elsewhere on the board
/Ethernet/W5500-CS: U401.5 (CS); also elsewhere on the board
/Ethernet/W5500-INT: U401.6 (INT); also elsewhere on the board
/Ethernet/W5500-MISO: U401.7 (MISO); also elsewhere on the board
/Ethernet/W5500-MOSI: U401.3 (MOSI); also elsewhere on the board
/Ethernet/W5500-RST: U401.8 (RST); also elsewhere on the board
/Ethernet/W5500-SCLK: U401.4 (SCLK); also elsewhere on the board
GND: C401.2, U401.1 (GND), U401.2 (GND), U401.12 (GND); also elsewhere on the board

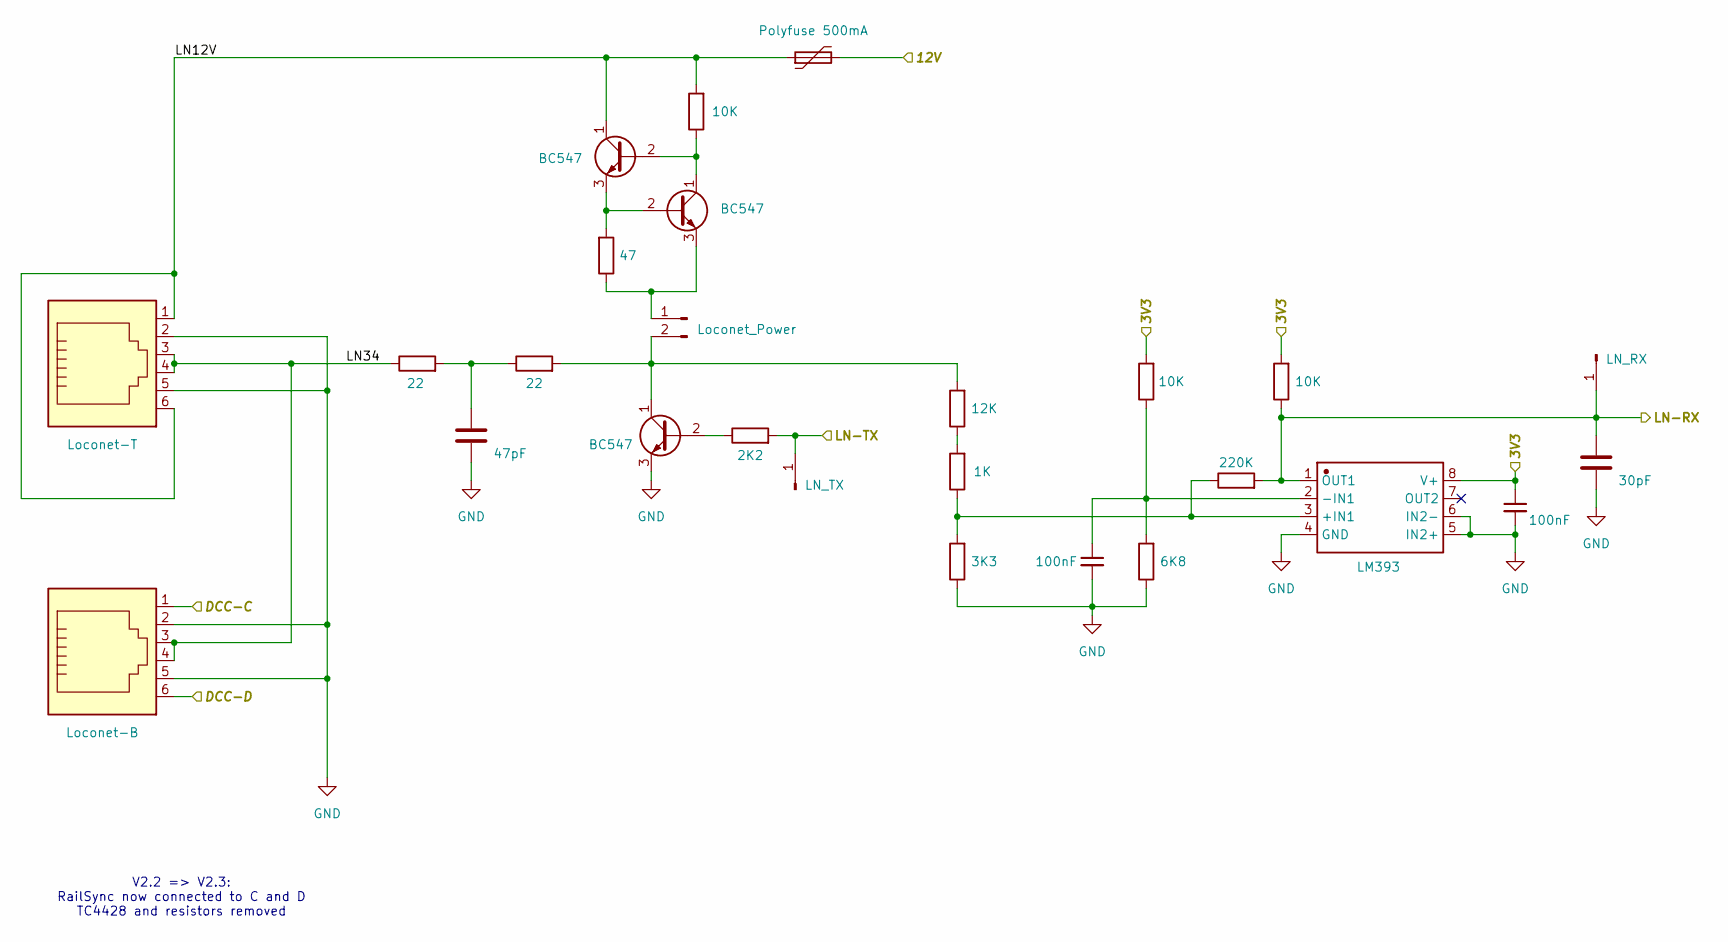
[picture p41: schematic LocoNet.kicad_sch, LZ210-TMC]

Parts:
C1001: 47pF; C_Disc_D8.0mm_W2.5mm_P5.00mm
C1002: 30pF; C_Disc_D8.0mm_W2.5mm_P5.00mm
C1003, C1004: 100nF; C_Disc_D5.0mm_W2.5mm_P2.50mm
F1001: Polyfuse 500mA; Fuse_Bourns_MF-RHT050
J1001: Loconet_Power; PinHeader_1x02_P2.54mm_Vertical
J1002: Loconet-T; RJ25_Wayconn_MJEA-660X1_Horizontal
J1003: LN_RX; PinHeader_1x01_P2.54mm_Vertical
J1004: LN_TX; PinHeader_1x01_P2.54mm_Vertical
J1006: Loconet-B; RJ25_Wayconn_MJEA-660X1_Horizontal
Q1001, Q1002, Q1003: BC547; TO-92_BC5xx_HandSolder
R1001, R1005, R1006: 10K; R-0207-10
R1002: 47; R-0207-10
R1003, R1004: 22; R-0207-10
R1007: 12K; R-0207-10
R1008: 2K2; R-0207-10
R1009: 1K; R-0207-10
R1010: 220K; R-0207-10
R1011: 3K3; R-0207-10
R1012: 6K8; R-0207-10
U1001: LM393; DIL08

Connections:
/3V3: C1003.1, R1005.2, R1006.2, U1001.8 (V+); also elsewhere on the board
/12V: F1001.2; also elsewhere on the board
/CDE-Interface/DCC-C: J1006.1; also elsewhere on the board
/CDE-Interface/DCC-D: J1006.6; also elsewhere on the board
/LocoNet/LN12V: F1001.1, J1002.1, J1002.6, Q1001.1 (C), R1001.2
/LocoNet/LN34: J1002.3, J1002.4, J1006.3, J1006.4, R1003.1
/LocoNet/LN-RX: C1002.1, J1003.1 (Pin_1_1), R1006.1, R1010.2, U1001.1 (OUT1); also elsewhere on the board
/LocoNet/LN-TX: J1004.1 (Pin_1_1), R1008.2; also elsewhere on the board
GND: C1001.2, C1002.2, C1003.2, C1004.2, J1002.2, J1002.5, J1006.2, J1006.5, Q1003.3 (E), R1011.1, R1012.1, U1001.4 (GND), U1001.5 (IN2+), U1001.6 (IN2-); also elsewhere on the board
unnamed: C1001.1, R1003.2, R1004.1
unnamed: J1001.1, Q1002.3 (E), R1002.1
unnamed: J1001.2, Q1003.1 (C), R1004.2, R1007.2
unnamed: Q1001.2 (B), Q1002.1 (C), R1001.1
unnamed: Q1001.3 (E), Q1002.2 (B), R1002.2
unnamed: Q1003.2 (B), R1008.1
unnamed: R1007.1, R1009.2
unnamed: R1009.1, R1010.1, R1011.2, U1001.3 (+IN1)
unnamed: C1004.1, R1005.1, R1012.2, U1001.2 (-IN1)

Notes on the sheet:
V2.2 => V2.3: RailSync now connected to C and D TC4428 and resistors removed

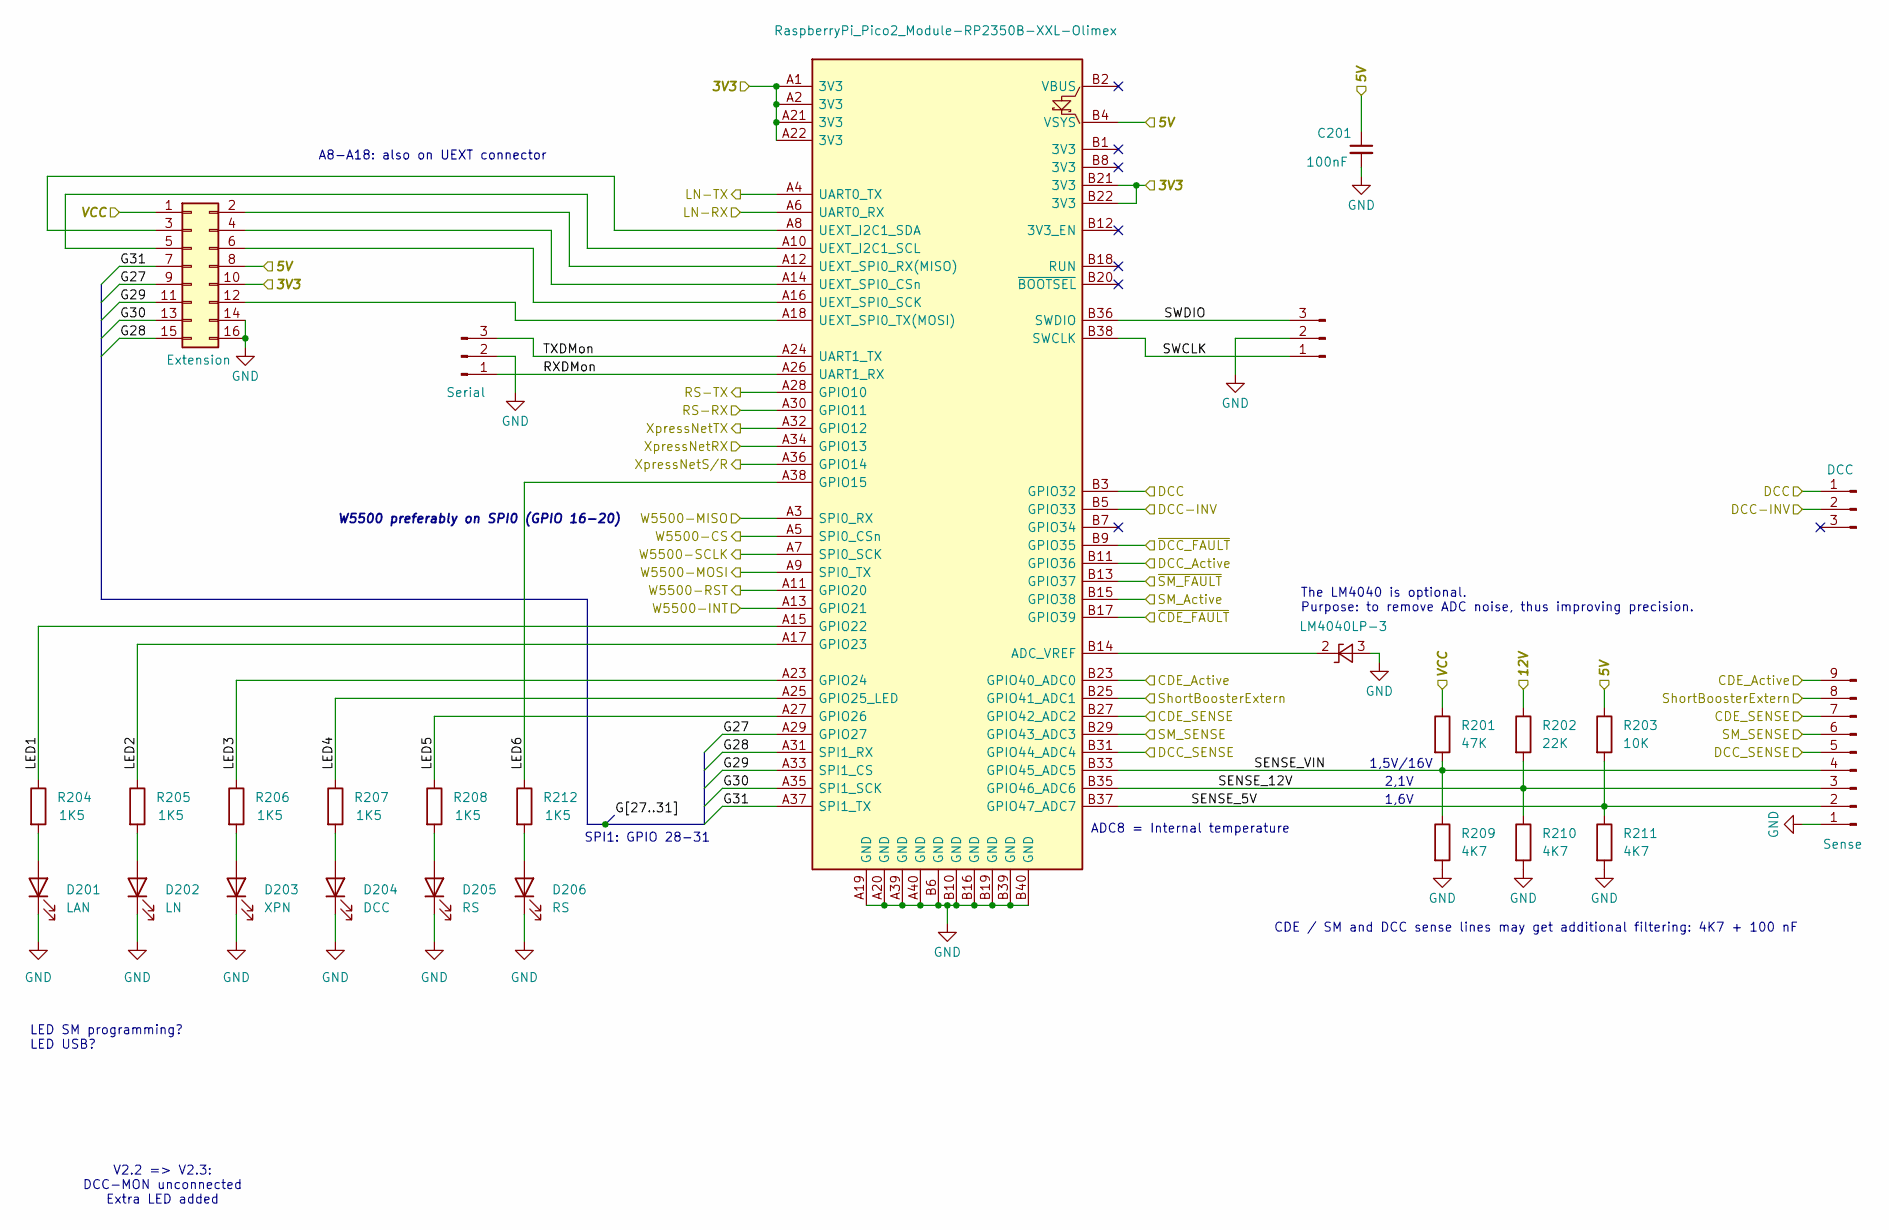
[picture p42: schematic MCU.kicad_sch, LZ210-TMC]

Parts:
C201: 100nF; C_Disc_D5.0mm_W2.5mm_P2.50mm
D201: LAN; LED_D3.0mm
D202: LN; LED_D3.0mm
D203: XPN; LED_D3.0mm
D204: DCC; LED_D3.0mm
D205, D206: RS; LED_D3.0mm
J201: Extension; IDC-Header_2x08_P2.54mm_Vertical
J202: Debug; Molex_KK-254_AE-6410-03A_1x03_P2.54mm_Vertical
J203: Serial; Molex_KK-254_AE-6410-03A_1x03_P2.54mm_Vertical
J204: DCC; PinHeader_1x03_P2.54mm_Vertical
J205: Sense; PinHeader_1x09_P2.54mm_Vertical
R201: 47K; R-0207-10
R202: 22K; R-0207-10
R203: 10K; R-0207-10
R204, R205, R206, R207, R208, R212: 1K5; R-0207-10
R209, R210, R211: 4K7; R-0207-10
U201: RaspberryPi_Pico2_Module-RP2350B-XXL-Olimex; Module-RP2350B-XXL-Olimex
U202: LM4040LP-3; TO-92_Inline

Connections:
/3V3: J201.10, U201.A1 (3V3), U201.A2 (3V3), U201.A21 (3V3), U201.A22 (3V3), U201.B21 (3V3), U201.B22 (3V3); also elsewhere on the board
/5V: C201.1, J201.8, R203.1, U201.B4 (VSYS); also elsewhere on the board
/12V: R202.1; also elsewhere on the board
/CDE-Interface/IN1/EN: J204.1, U201.B3 (GPIO32); also elsewhere on the board
/CDE-Interface/IN2/PH: J204.2, U201.B5 (GPIO33); also elsewhere on the board
/CDE-Interface/SENSE: J205.7, U201.B27 (GPIO42_ADC2); also elsewhere on the board
/CDE-Interface/ShortBoosterExtern: J205.8, U201.B25 (GPIO41_ADC1); also elsewhere on the board
/CDE-Interface/~FAULT: U201.B17 (GPIO39); also elsewhere on the board
/CDE-Interface/~Sleep: J205.9, U201.B23 (GPIO40_ADC0); also elsewhere on the board
/DCC-Out/SENSE: J205.5, U201.B31 (GPIO44_ADC4); also elsewhere on the board
/DCC-Out/~FAULT: U201.B9 (GPIO35); also elsewhere on the board
/DCC-Out/~Sleep: U201.B11 (GPIO36); also elsewhere on the board
/Ethernet/W5500-CS: U201.A5 (SPI0_CSn); also elsewhere on the board
/Ethernet/W5500-INT: U201.A13 (GPIO21); also elsewhere on the board
/Ethernet/W5500-MISO: U201.A3 (SPI0_RX); also elsewhere on the board
/Ethernet/W5500-MOSI: U201.A9 (SPI0_TX); also elsewhere on the board
/Ethernet/W5500-RST: U201.A11 (GPIO20); also elsewhere on the board
/Ethernet/W5500-SCLK: U201.A7 (SPI0_SCK); also elsewhere on the board
/LocoNet/LN-RX: U201.A6 (UART0_RX); also elsewhere on the board
/LocoNet/LN-TX: U201.A4 (UART0_TX); also elsewhere on the board
/MCU/G27: J201.9, U201.A29 (GPIO27)
/MCU/G28: J201.15, U201.A31 (SPI1_RX)
/MCU/G29: J201.11, U201.A33 (SPI1_CS)
/MCU/G30: J201.13, U201.A35 (SPI1_SCK)
/MCU/G31: J201.7, U201.A37 (SPI1_TX)
/MCU/LED1: R204.1, U201.A15 (GPIO22)
/MCU/LED2: R205.1, U201.A17 (GPIO23)
/MCU/LED3: R206.1, U201.A23 (GPIO24)
/MCU/LED4: R207.1, U201.A25 (GPIO25_LED)
/MCU/LED5: R208.1, U201.A27 (GPIO26)
/MCU/LED6: R212.1, U201.A38 (GPIO15)
/MCU/RS-RX: U201.A30 (GPIO11); also elsewhere on the board
/MCU/RS-TX: U201.A28 (GPIO10); also elsewhere on the board
/MCU/RXDMon: J203.1, U201.A26 (UART1_RX)
/MCU/SENSE_5V: J205.2, R203.2, R211.1, U201.B37 (GPIO47_ADC7)
/MCU/SENSE_12V: J205.3, R202.2, R210.1, U201.B35 (GPIO46_ADC6)
/MCU/SENSE_VIN: J205.4, R201.2, R209.1, U201.B33 (GPIO45_ADC5)
/MCU/SM_Active: U201.B15 (GPIO38); also elsewhere on the board
/MCU/SM_SENSE: J205.6, U201.B29 (GPIO43_ADC3); also elsewhere on the board
/MCU/SWCLK: J202.1, U201.B38 (SWCLK)
/MCU/SWDIO: J202.3, U201.B36 (SWDIO)
/MCU/TXDMon: J203.3, U201.A24 (UART1_TX)
/MCU/XpressNetRX: U201.A34 (GPIO13); also elsewhere on the board
/MCU/XpressNetS/R: U201.A36 (GPIO14); also elsewhere on the board
/MCU/XpressNetTX: U201.A32 (GPIO12); also elsewhere on the board
/MCU/~SM_FAULT: U201.B13 (GPIO37); also elsewhere on the board
/VCC: J201.1, R201.1; also elsewhere on the board
GND: C201.2, D201.1 (K), D202.1 (K), D203.1 (K), D204.1 (K), D205.1 (K), D206.1 (K), J201.14, J201.16, J202.2, J203.2, J205.1, R209.2, R210.2, R211.2, U201.A19 (GND), U201.A20 (GND), U201.A39 (GND), U201.A40 (GND), U201.B6 (GND), U201.B10 (GND), U201.B16 (GND), U201.B19 (GND), U201.B39 (GND), U201.B40 (GND), U202.3 (A); also elsewhere on the board
unnamed: D201.2 (A), R204.2
unnamed: D202.2 (A), R205.2
unnamed: D203.2 (A), R206.2
unnamed: D204.2 (A), R207.2
unnamed: D205.2 (A), R208.2
unnamed: D206.2 (A), R212.2
unnamed: J201.2, U201.A12 (UEXT_SPI0_RX(MISO))
unnamed: J201.3, U201.A8 (UEXT_I2C1_SDA)
unnamed: J201.4, U201.A14 (UEXT_SPI0_CSn)
unnamed: J201.5, U201.A10 (UEXT_I2C1_SCL)
unnamed: J201.6, U201.A16 (UEXT_SPI0_SCK)
unnamed: J201.12, U201.A18 (UEXT_SPI0_TX(MOSI))
unnamed: U201.B14 (ADC_VREF), U202.2 (K)

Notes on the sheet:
1,5V/16V
LED SM programming? LED USB?
1,6V
The LM4040 is optional. Purpose: to remove ADC noise, thus improving precision.
2,1V
CDE / SM and DCC sense lines may get additional filtering: 4K7 + 100 nF
SPI1: GPIO 28-31
W5500 preferably on SPI0 (GPIO 16-20)
A8-A18: also on UEXT connector
V2.2 => V2.3: DCC-MON unconnected Extra LED added
ADC8 = Internal temperature

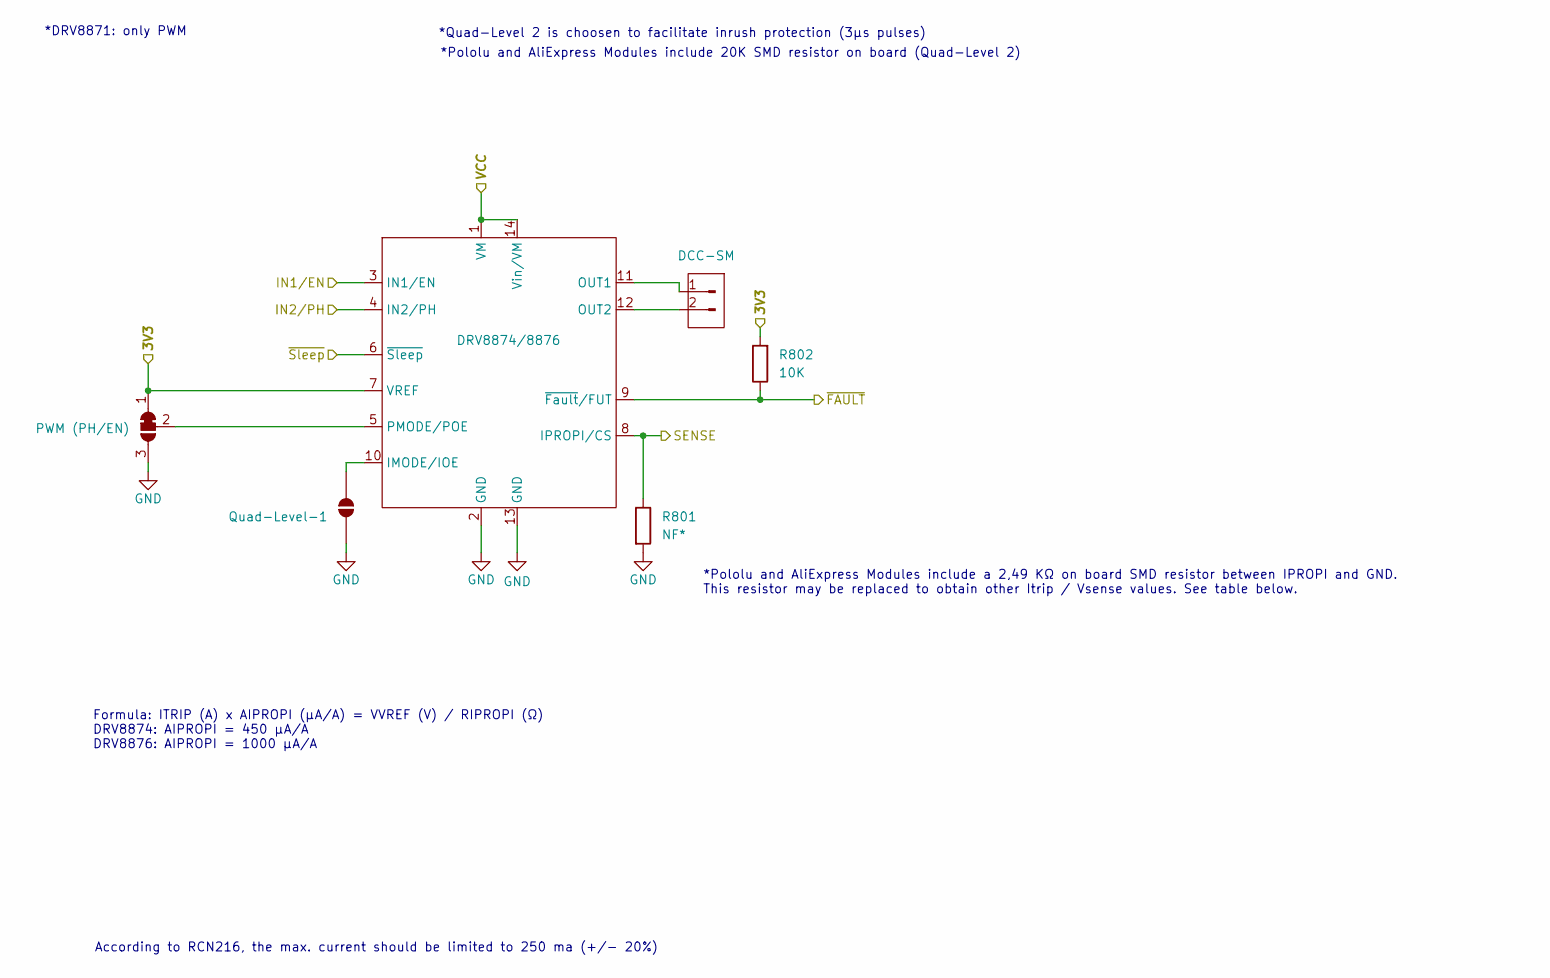
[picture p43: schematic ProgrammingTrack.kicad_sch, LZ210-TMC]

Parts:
J801: DCC-SM; PhoenixContact_MC_1,5_2-G-3.81_1x02_P3.81mm_Horizontal
JP801: PWM (PH/EN); SolderJumper-3_P1.3mm_Bridged12_RoundedPad1.0x1.5mm_NumberL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
JP802: Quad-Level-1; SolderJumper-2_P1.3mm_Open_RoundedPad1.0x1.5mm
R801: NF*; R-0207-10
R802: 10K; R-0207-10
U801: DRV8874/8876; Module-DRV8874

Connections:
/3V3: JP801.1 (A), R802.2, U801.7 (VREF); also elsewhere on the board
/CDE-Interface/IN1/EN: U801.3 (IN1/EN); also elsewhere on the board
/CDE-Interface/IN2/PH: U801.4 (IN2/PH); also elsewhere on the board
/MCU/SM_Active: U801.6 (~Sleep); also elsewhere on the board
/MCU/SM_SENSE: R801.1, U801.8 (IPROPI/CS); also elsewhere on the board
/MCU/~SM_FAULT: R802.1, U801.9 (~Fault/FUT); also elsewhere on the board
/VCC: U801.1 (VM), U801.14 (Vin/VM); also elsewhere on the board
GND: JP801.3 (B), JP802.1 (A), R801.2, U801.2 (GND), U801.13 (GND); also elsewhere on the board
unnamed: J801.1, U801.11 (OUT1)
unnamed: J801.2, U801.12 (OUT2)
unnamed: JP801.2 (C), U801.5 (PMODE/POE)
unnamed: JP802.2 (B), U801.10 (IMODE/IOE)

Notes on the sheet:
*Quad-Level 2 is choosen to facilitate inrush protection (3µs pulses)
*DRV8871: only PWM
According to RCN216, the max. current should be limited to 250 ma (+/- 20%)
*Pololu and AliExpress Modules include a 2,49 KΩ on board SMD resistor between IPROPI and GND. This resistor may be replaced to obtain other Itrip / Vsense values. See table below.
*Pololu and AliExpress Modules include 20K SMD resistor on board (Quad-Level 2)
Formula: ITRIP (A) x AIPROPI (μA/A) = VVREF (V) / RIPROPI (Ω) DRV8874: AIPROPI = 450 μA/A DRV8876: AIPROPI = 1000 μA/A

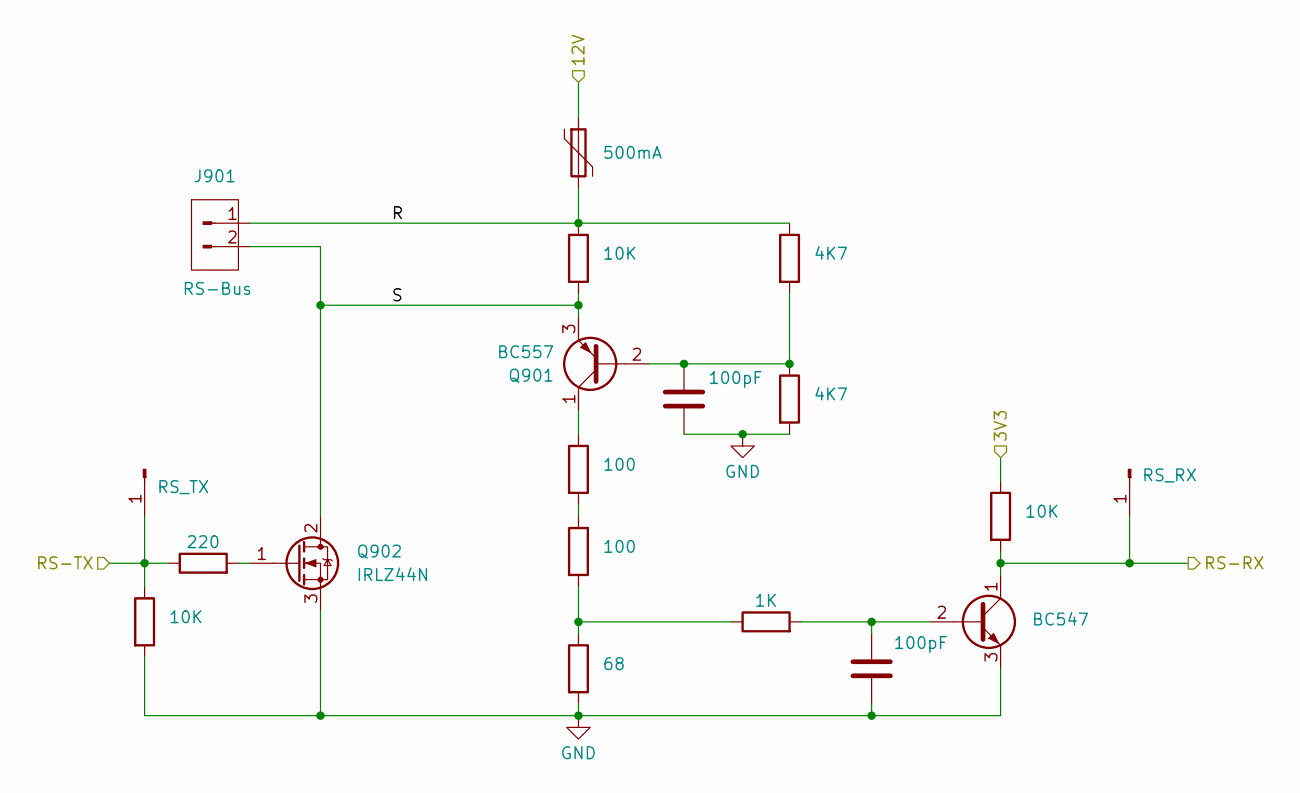
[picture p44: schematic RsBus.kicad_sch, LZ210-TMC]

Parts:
C901, C902: 100pF; C_Disc_D8.0mm_W2.5mm_P5.00mm
F901: 500mA; Fuse_Bourns_MF-RHT050
J901: RS-Bus; PhoenixContact_MC_1,5_2-G-3.81_1x02_P3.81mm_Horizontal
J902: RS_TX; PinHeader_1x01_P2.54mm_Vertical
J903: RS_RX; PinHeader_1x01_P2.54mm_Vertical
Q901: BC557; TO-92_BC5xx_HandSolder
Q902: IRLZ44N; TO-220-3_Vertical
Q903: BC547; TO-92_BC5xx_HandSolder
R901, R905, R908: 10K; R-0207-10
R902, R903: 4K7; R-0207-10
R904, R906: 100; R-0207-10
R907: 220; R-0207-10
R909: 1K; R-0207-10
R910: 68; R-0207-10

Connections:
/3V3: R905.1; also elsewhere on the board
/12V: F901.1; also elsewhere on the board
/MCU/RS-RX: J903.1 (Pin_1_1), Q903.1 (C), R905.2; also elsewhere on the board
/MCU/RS-TX: J902.1 (Pin_1_1), R907.1, R908.1; also elsewhere on the board
/RsBus/R: F901.2, J901.1, R901.1, R902.1
/RsBus/S: J901.2, Q901.3 (E), Q902.2 (D), R901.2
GND: C901.2, C902.2, Q902.3 (S), Q903.3 (E), R903.2, R908.2, R910.2; also elsewhere on the board
unnamed: C901.1, Q901.2 (B), R902.2, R903.1
unnamed: Q901.1 (C), R904.1
unnamed: Q902.1 (G), R907.2
unnamed: C902.1, Q903.2 (B), R909.2
unnamed: R904.2, R906.1
unnamed: R906.2, R909.1, R910.1

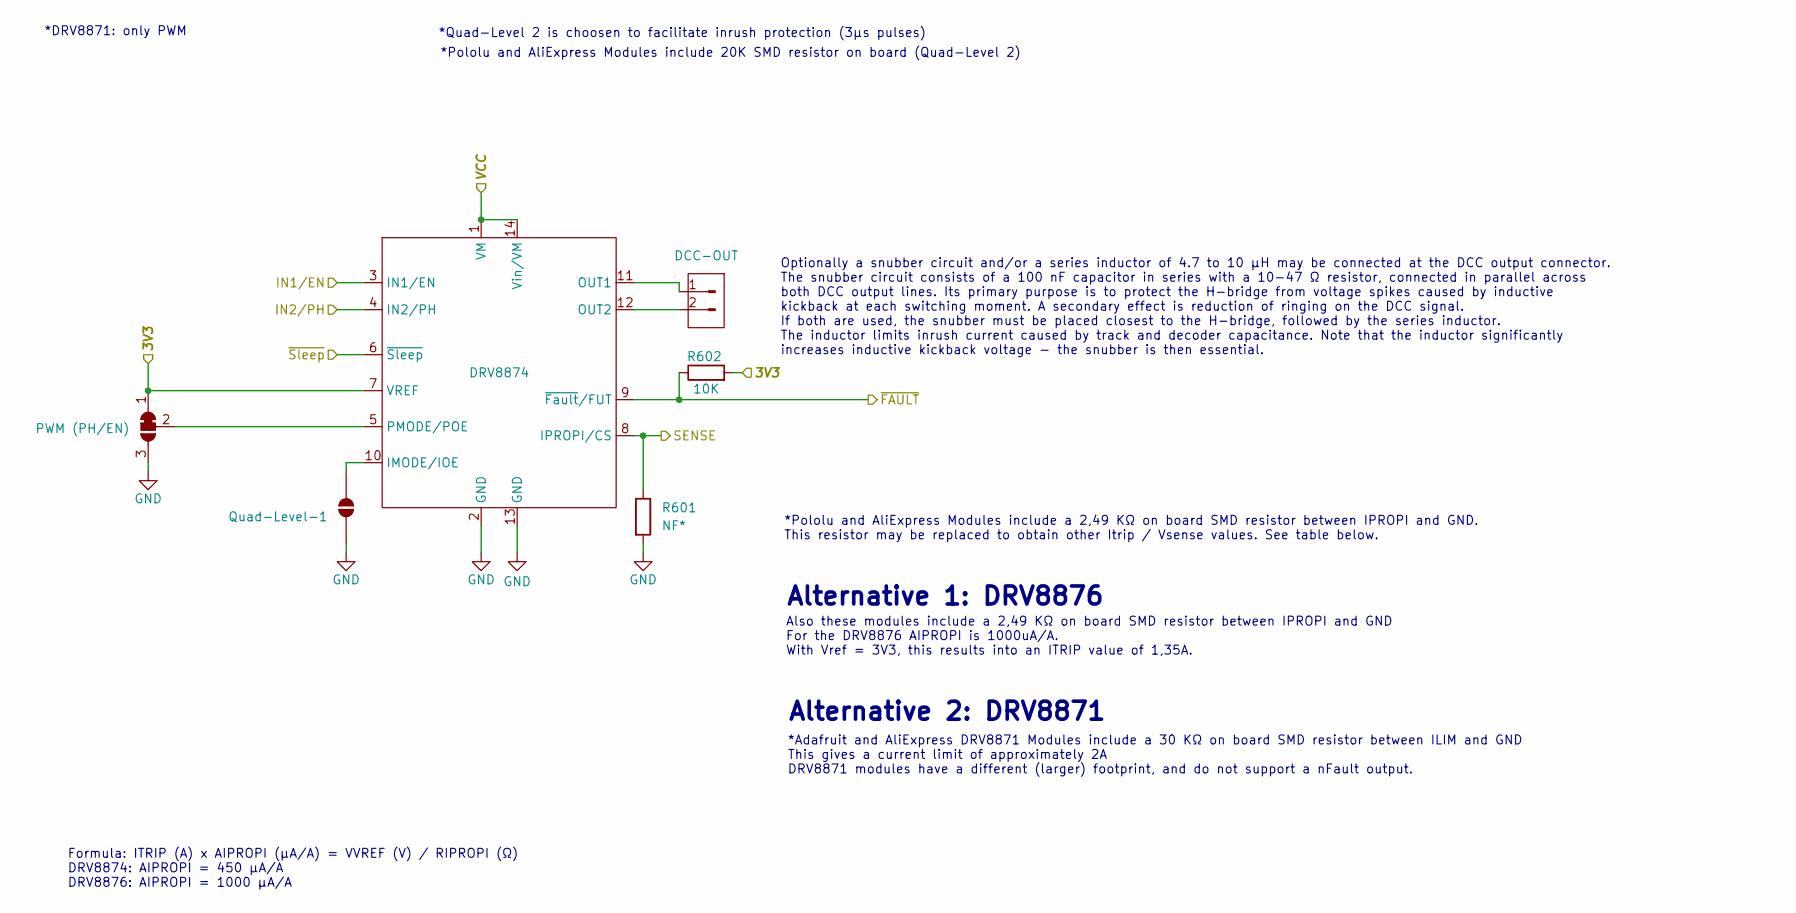
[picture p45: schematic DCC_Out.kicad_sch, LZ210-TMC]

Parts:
J601: DCC-OUT; PhoenixContact_MSTBA_2,5_2-G_1x02_P5.00mm_Horizontal
JP601: PWM (PH/EN); SolderJumper-3_P1.3mm_Bridged12_RoundedPad1.0x1.5mm_NumberL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
JP602: Quad-Level-1; SolderJumper-2_P1.3mm_Open_RoundedPad1.0x1.5mm
R601: NF*; R-0207-10
R602: 10K; R-0207-10
U601: DRV8874; Module-DRV8874

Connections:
/3V3: JP601.1 (A), R602.2, U601.7 (VREF); also elsewhere on the board
/CDE-Interface/IN1/EN: U601.3 (IN1/EN); also elsewhere on the board
/CDE-Interface/IN2/PH: U601.4 (IN2/PH); also elsewhere on the board
/DCC-Out/SENSE: R601.1, U601.8 (IPROPI/CS); also elsewhere on the board
/DCC-Out/~FAULT: R602.1, U601.9 (~Fault/FUT); also elsewhere on the board
/DCC-Out/~Sleep: U601.6 (~Sleep); also elsewhere on the board
/VCC: U601.1 (VM), U601.14 (Vin/VM); also elsewhere on the board
GND: JP601.3 (B), JP602.1 (A), R601.2, U601.2 (GND), U601.13 (GND); also elsewhere on the board
unnamed: J601.1, U601.11 (OUT1)
unnamed: J601.2, U601.12 (OUT2)
unnamed: JP601.2 (C), U601.5 (PMODE/POE)
unnamed: JP602.2 (B), U601.10 (IMODE/IOE)

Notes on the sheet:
*Pololu and AliExpress Modules include 20K SMD resistor on board (Quad-Level 2)
Alternative 2: DRV8871
*Quad-Level 2 is choosen to facilitate inrush protection (3µs pulses)
Alternative 1: DRV8876
*Adafruit and AliExpress DRV8871 Modules include a 30 KΩ on board SMD resistor between ILIM and GND This gives a current limit of approximately 2A DRV8871 modules have a different (larger) footprint, and do not support a nFault output.
Formula: ITRIP (A) x AIPROPI (μA/A) = VVREF (V) / RIPROPI (Ω) DRV8874: AIPROPI = 450 μA/A DRV8876: AIPROPI = 1000 μA/A
Also these modules include a 2,49 KΩ on board SMD resistor between IPROPI and GND For the DRV8876 AIPROPI is 1000uA/A. With Vref = 3V3, this results into an ITRIP value of 1,35A.
*DRV8871: only PWM
*Pololu and AliExpress Modules include a 2,49 KΩ on board SMD resistor between IPROPI and GND. This resistor may be replaced to obtain other Itrip / Vsense values. See table below.
Optionally a snubber circuit and/or a series inductor of 4.7 to 10 µH may be connected at the DCC output connector. The snubber circuit consists of a 100 nF capacitor in series with a 10-47 Ω resistor, connected in parallel across both DCC output lines. Its primary purpose is to protect the H-bridg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

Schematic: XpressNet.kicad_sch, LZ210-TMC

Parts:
C501: 100nF; C_Disc_D5.0mm_W2.5mm_P2.50mm
F501: Polyfuse 500mA; Fuse_Bourns_MF-RHT050
J501: DIN-XpressNet; Connector-DIN-XpressNet
J502: XPN; PinHeader_1x03_P2.54mm_Vertical
J503: XpressNet; PhoenixContact_MC_1,5_4-G-3.81_1x04_P3.81mm_Horizontal
R501, R503: 560; R-0207-10
R502: 120; R-0207-10
R504: 8K2; R-0207-10
U501: MAX3485; DIL08

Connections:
/3V3: C501.1, R501.2, U501.8 (VCC); also elsewhere on the board
/12V: F501.2; also elsewhere on the board
/MCU/XpressNetRX: J502.3, U501.1 (RO); also elsewhere on the board
/MCU/XpressNetS/R: J502.2, R504.1, U501.2 (~RE), U501.3 (DE); also elsewhere on the board
/MCU/XpressNetTX: J502.1, U501.4 (DI); also elsewhere on the board
/XpressNet/A: J501.4, J503.3, R501.1, R502.2, U501.6 (A)
/XpressNet/B: J501.5, J503.4, R502.1, R503.2, U501.7 (B)
GND: C501.2, J501.3, J501.6, J501.7, J503.2, R503.1, R504.2, U501.5 (GND); also elsewhere on the board
unnamed: F501.1, J501.1, J503.1

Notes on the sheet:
The MAX3483 is a slewrate limited equivalent of the MAX3485 (250kBit instead of 2.5 MBit). Lower slewrate results in a cleaner XpressNet signal (less ringing). The DIP-8 version of the MAX3483 is relatively expensive, however.
The SMD variant of this board may use an SM712 Asymmerical TVS Diode for RS-485 protection.

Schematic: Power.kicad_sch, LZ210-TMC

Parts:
C301: 470uF; CP_Radial_D10.0mm_P5.00mm
D301: 1N5822; D_DO-201AD_P15.24mm_Horizontal
D302: D; Module-XL74610
F301: Polyfuse; Fuse_Bourns_MF-RG300
J301, J302: GND; PinHeader_1x01_P2.54mm_Vertical
J303: Connector-Power-Barrel-Jack
U301: 5V Step down Module; Module-StepDown-MP1584-Formfactor
U302: 12V Step down Module; Module-StepDown-MP1584-Formfactor

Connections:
/5V: D301.1 (K); also elsewhere on the board
/12V: U302.3 (VOUT+); also elsewhere on the board
/Power/POW_IN_AFTER_FUSE: D302.2 (A), F301.2
/Power/POW_IN_FOR_FUSE: F301.1, J303.1
/VCC: C301.1, D302.1 (K), U301.1 (VIN+), U302.1 (VIN+); also elsewhere on the board
GND: C301.2, J301.1 (Pin_1_1), J302.1 (Pin_1_1), J303.2, J303.3, U301.2 (GND), U302.2 (GND); also elsewhere on the board
unnamed: D301.2 (A), U301.3 (VOUT+)

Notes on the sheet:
The Olimex RP2350-XL Module can not be powered from external 3V3, but requires external 5V. The Module has a TPS62A02, which can not be disabled since it has Active Output Discharge. Active Output Discharge connects the output via a resistor to GND. The extra diode is needed to protect against pote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

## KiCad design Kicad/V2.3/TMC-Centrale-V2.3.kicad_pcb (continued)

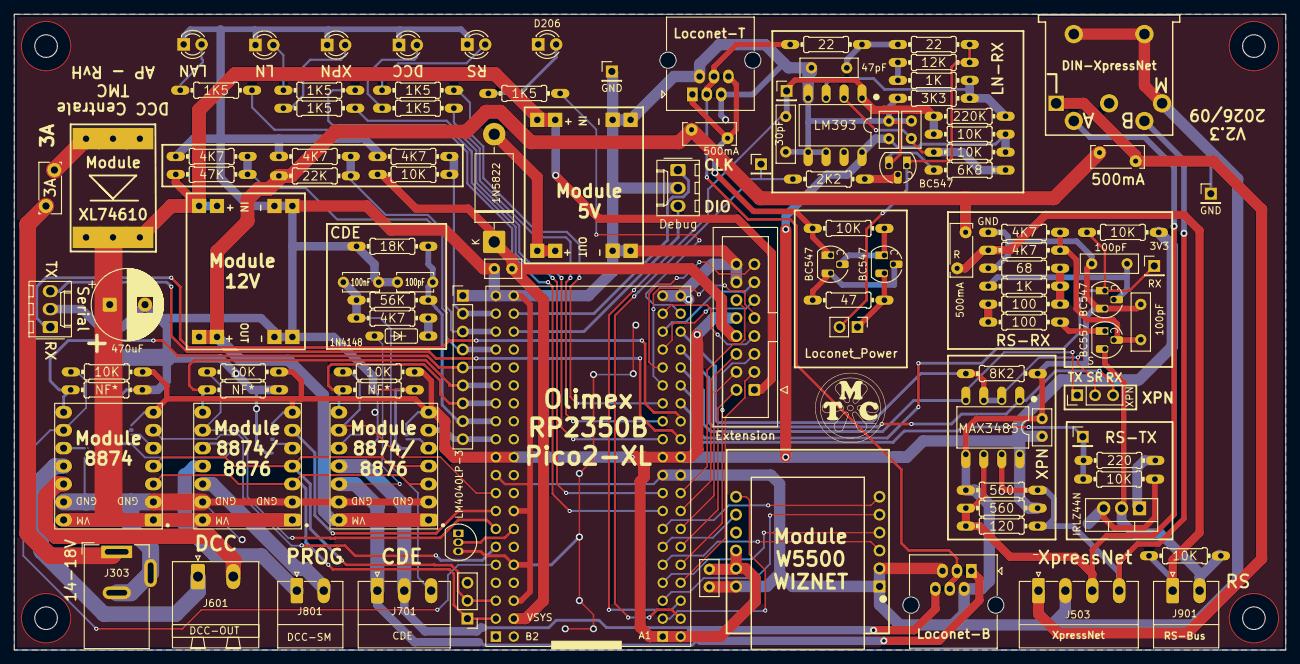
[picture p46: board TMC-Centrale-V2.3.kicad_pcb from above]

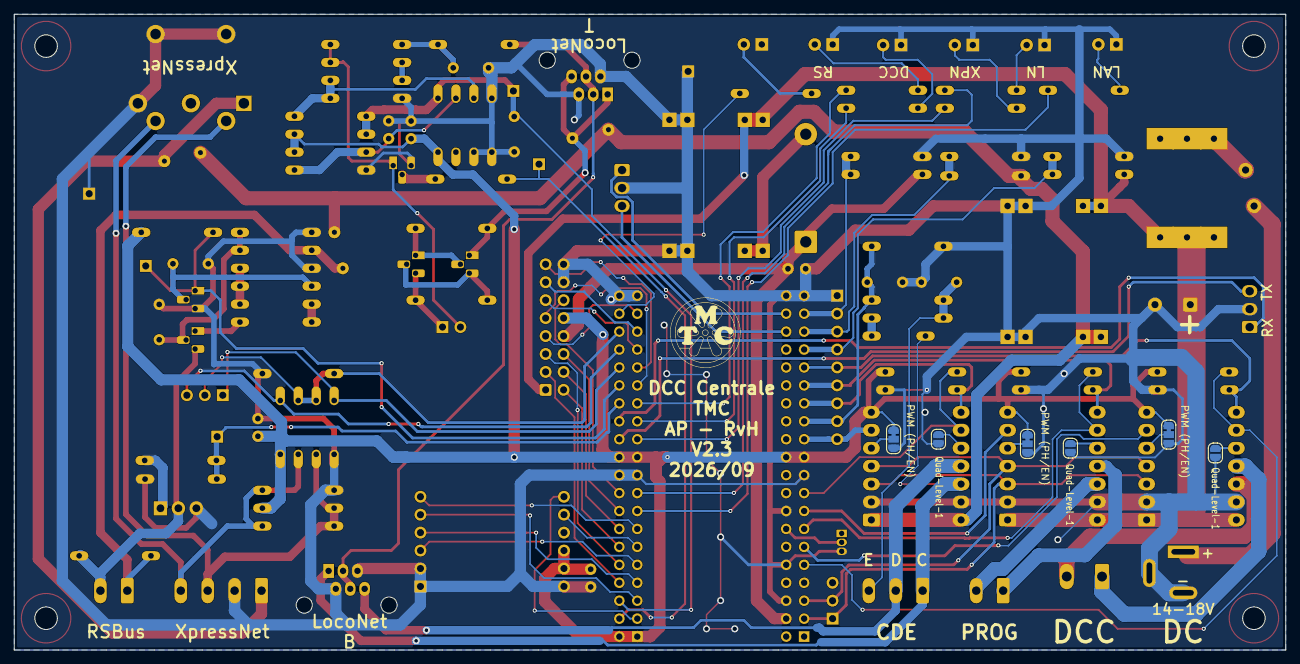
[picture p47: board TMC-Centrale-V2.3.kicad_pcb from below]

Board: 2 copper layers, 180.0 x 90.0 mm, 120 parts (6 on the bottom side), 100 nets.

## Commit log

2026-07-22 PCB for the LZ210
    First commit
    [CDE-Interface.kicad_sch, DCC_Out.kicad_sch, Ethernet.kicad_sch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]
2026-09-16 Version 2.2
    Version 2.2 is a small update of the CDE interface (the 3V3 zener removed, some values changed). If you already have a V2.1 board, there is no need to change: kust remove the 3V3 zener and change 2 r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
    [CDE-Interface.kicad_sch, DCC_Out.kicad_sch, Ethernet.kicad_sch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]
2026-09-19 Centrale V2.3 (1)
    [CDE-Interface.kicad_sch, LocoNet.kicad_sch, MCU.kicad_sch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]
2026-09-21 Version of the PCB added
    [CDE-Interface.kicad_sch, DCC_Out.kicad_sch, Ethernet.kicad_sch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]
2026-09-21 PCB Version 2.3 added
    Version 2.3 changed the RailSync signal generation. The special line drivers (plus resistors and other components) were removed, and the RailSync signal now comes from the C and D pin of the CDE conn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
    [CDE-Interface.kicad_sch, DCC_Out.kicad_sch, Ethernet.kicad_sch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]
2026-09-21 Update PCB file reference in README
2026-09-21 Documentation RailSync improved
    The markdown texts were improved, to present the modified RailSync signal generation
2026-10-03 Update documentation
    the FAULT.md is extended with an "recommendations" section. Dutch and German translation of the FAULT.md are added. Several errors and nconsistencies were corrected. A photo of the PCB (V2.1) was added.

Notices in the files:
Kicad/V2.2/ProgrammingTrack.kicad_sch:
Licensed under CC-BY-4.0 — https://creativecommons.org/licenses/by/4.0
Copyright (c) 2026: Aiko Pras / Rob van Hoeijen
